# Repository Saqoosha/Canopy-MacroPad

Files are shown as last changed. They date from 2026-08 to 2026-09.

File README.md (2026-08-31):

# Canopy MacroPad

Six keys next to the keyboard. Each key mirrors one Canopy pane: its
LED shows what that pane's Claude session is doing, and pressing it
focuses that pane and brings Canopy forward.

**There are two of these, and one firmware runs both.** The first is
three boards butted together: keys 2-5 a NeoKey 1x4 on I2C, keys 0-1 two
single-key breakouts read straight off GPIO, landing on one 19.05 mm
pitch because the breakout happens to be exactly one pitch wide with its
switch centred in it. The second is a **custom PCB** that is all six keys
on one board — see [Phase 1 scope](#phase-1-scope).

Which board a key sits on, and which device it is, are both invisible to
the host: the protocol has one index space and the device reports its
size. The firmware picks a board profile from the CircuitPython build it
booted, so neither the wire protocol nor the key numbering moves.

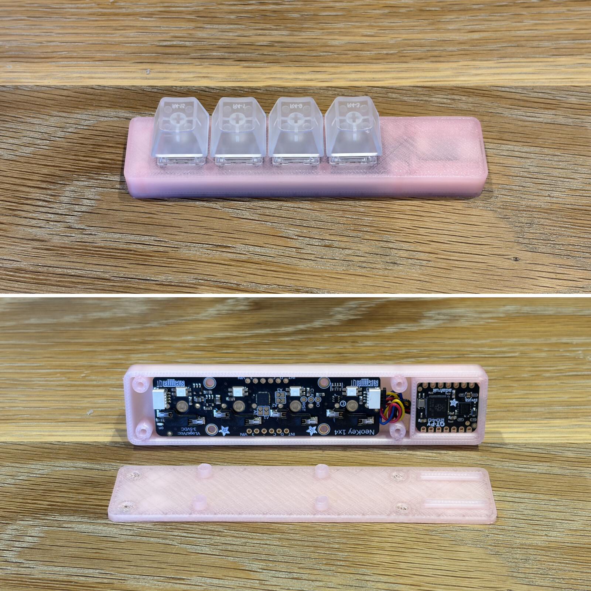
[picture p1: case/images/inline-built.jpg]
The four-key inline case, closed with keycaps on, and open with the NeoKey and the QT Py seated in the shell above the bottom plate


**That photograph is the four-key print**, which is the pad that existed
before the breakouts. The six-key `inline` case is printed, wired and
closing; the photograph of *it* is the wiring shot further down, taken
with the shell turned over. Nothing here is waiting on hardware.

That is the **first** device, in the `inline` case, printed on a Bambu A1
mini. The enclosure is parametric, and it is also **[a model you can turn
in a browser](https://saqoosha.github.io/Canopy-MacroPad/)** — orbit,
explode, cutaway. The published page is the `choc` case, for the custom
board, so it is **not** the case in the photo above. It is a copy rather
than a build, so it goes stale on its own; `case/README.md` carries the
five lines that republish it. How the case is built is there too.

This repository holds the device half. The macOS half lives in the
[Canopy](https://github.com/saqoosha/Canopy) repository under
`Sources/Canopy/MacroPad/`.

## Why not HID

The device enumerates as USB serial only — `usb_hid.disable()` in
`boot.py`. It is never a keyboard. Consequences, all of them the reason:

- keystrokes cannot leak into whatever app is focused
- with Canopy not running, pressing a key does nothing at all
- macOS never asks for the Input Monitoring permission, because nothing
  reads HID. (OpenAI's Codex Micro required it as of 2026-08.)
- a serial port is plain file I/O on `/dev/cu.*` — no entitlement, no
  Hardened Runtime or notarization friction
- raw press/release edges, with no OS key-repeat logic in between

Verifiable rather than asserted: `ioreg -w0 -l -r -c IOHIDDevice | grep
-c 'Canopy MacroPad'` returns 0, and the device's USB descriptor offers
CDC control and CDC data, plus mass storage in the states described
under [The CIRCUITPY drive](#the-circuitpy-drive) — no HID class at all,
in any of them.

Two limits worth stating, since the argument above reads as exhaustive
and is not. **The filesystem is still writable from the host**, and the
drive gate below does not change that: any process that can open the
console port has the REPL, and `storage.remount("/", readonly=False)`
from there rewrites `code.py` with no finger going near the device. A
plain `/dev/cu.*` open needs no entitlement, which is exactly the
property this section advertises three paragraphs up. So the threat
model here is "no input injection", not "tamper-proof" — the gate is a
convenience, not a boundary. And a **sandboxed** app would
need `com.apple.security.device.serial` to open the port; Canopy
sidesteps that by not being sandboxed at all (no
`com.apple.security.app-sandbox` key in `Canopy.entitlements`). If that
changes, this design has to be revisited.

## The CIRCUITPY drive

`boot.py` calls `storage.disable_usb_drive()` unless a key is held while
the device boots. The reason is mundane: this pad is unplugged the way
any desk toy is, and a mounted volume disappearing makes macOS say
*"Disk Not Ejected Properly"* every single time, about a disk nobody was
using. Ejecting first works and nobody does it.

**Hold any of the six keys through a boot and `CIRCUITPY` mounts as
before.** Any hard reset counts — replug, `RST` where there is one, or
`microcontroller.reset()` — since that is when `boot.py` runs. The drive
then stays mounted for the rest of the session, so an edit-and-copy loop
needs the finger only once.

How the six are read differs by board, and `boot.py` carries its own small
copy of the profile table to know which. On the **PCB** all six are GPIO
and there is no bus to probe. On the **wired pad** the GPIO pair is read
first, because two pin reads cost nothing against the seesaw's 0.5 s
software reset and a key held there skips the bus entirely; on the I2C
side only `0x30` is probed, so a second NeoKey's keys would not work as
the gate.

Rather than enumerate the ways the read can fail, state the property
that holds by inspection: **`disable_usb_drive()` is reachable on
exactly one path — a completed read that saw no key held.** Every other
outcome leaves the drive enabled, whether it raises inside the guard,
escapes it, or never returns at all. That direction is deliberate: the
filesystem is how a broken board is recovered, and hiding it exactly
when the board is broken would be the worst possible time. The cost of
failing this way is that the macOS warning comes back, which is merely
the annoyance this whole thing exists to remove.

Which way the gate went is recorded in `boot_out.txt` — transcripts, not
examples; every line below was captured from a real boot:

```
usb drive: disabled; hold a key while plugging in for CIRCUITPY
usb drive: enabled (key held at boot)
usb drive: enabled (gate failed: ImportError: no module named 'adafruit_neokey')
```

Read that file **from the REPL** on the console port — `print(open(
"/boot_out.txt").read())`. Reading it off the mounted drive can only
ever show you the two `enabled` lines, because mounting the drive is
what makes the gate take the other branch and overwrite the line you
came for.

Two other ways back to the files, for when a key cannot be held. From
the REPL, `import storage` / `storage.remount("/", readonly=False)`
gives *the device* write access — the drive stays gone, so a new
`code.py` has to be pasted through serial; `os.remove("/boot.py")` and a
reset is the shorter version of the same idea. Or unseat the Qwiic
cable **and then hard reset** — the gate fails open on the next boot and
hands the drive back. Unseating alone changes nothing; `boot.py` does
not run again until the board does.

## Hardware

Two devices, so two bills of materials. The custom PCB is the current one
and replaces every board in the other; the wired pad is still assembled
and still works, and the numbers its assembly settled are inherited whole.

### The custom PCB

One board, 139.60 × 21.59 mm, two layers, 1.6 mm, fabricated and partly
assembled by JLCPCB. Designed in EasyEDA by script — `pcb/README.md` for
that side of it, `pcb/BRINGUP.md` for what to do with the article when it
arrives.

| Ref | Part | LCSC | Role |
|---|---|---|---|
| U3 | RP2040 | C2961140 | controller, CircuitPython |
| U1 | W25Q64JVSSIQ | C179171 | 8 MB QSPI flash |
| U2 | ABM8-272-T3 | C9900091606 | 12 MHz crystal |
| U4 | XC6206P332MR-G | C5446 | 3V3 LDO, everything sits behind it |
| D1 | USBLC6-2SC6 | C323793 | USB ESD |
| USBC1 | TYPE-C-31-M-12 | C165948 | USB-C receptacle |
| LED1-6 | SK6812MINI-E | C5149201 | reverse-mount pixels, one chain on GPIO25 |
| SK1-6 | CPG135001S30 | — | Kailh Choc hot-swap sockets, 19.05 pitch |
| SW1 | TS263065A | — | BOOT, beside the USB-C |
| R3, R4 | 27 Ω | C25100 | USB D+/D− series |
| R5, R6 | 5.1 kΩ | C25905 | USB-C CC pulldowns |
| R1, R2 | 1 kΩ | C11702 | BOOT series, crystal damping |
| — | Kailh Choc v2 ×6 | — | low-profile, hot-swappable |
| — | wrk. MX Pure keycaps ×6 | — | frosted PC |

Everything is on the **bottom** face — the Gerber archive carries a bottom
paste layer and no top one, which is the quickest way to confirm it. No
Qwiic cable, no inter-board wiring, and nothing hangs off an unregulated
rail: the pixels' `VDD` and the RP2040 both sit on 3V3 behind U4. That
last one is a real difference and not a detail — see `pcb/BRINGUP.md` for
what it cost to check, and for why the pixels run below their own
datasheet minimum on purpose.

### The wired pad, which came first

Still assembled, still driven by Canopy, and the source of every number
the case inherited.

| Part | SKU | Role |
|---|---|---|
| Adafruit QT Py RP2040 | ssci 7211 / ADA-4900 | controller, CircuitPython |
| Adafruit NeoKey 1x4 QT | ssci 10048 / ADA-4980 | keys 2-5, on I2C `0x30` |
| Adafruit NeoKey Socket Breakout ×2 | ssci 10047 / ADA-4978 | keys 0-1, on GPIO |
| Qwiic cable 50mm | ssci 6896 / SFE-PRT-17260 | QT Py ↔ NeoKey |
| Durock Ice King Linear ×6 | — | MX compatible, clear housing |
| Clear ABS keycaps ×6 | — | placeholder for printed caps |

Everything from here to this section's last paragraph is that device —
the cable, the five wires, the power tap, the rail argument. None of it
describes the PCB, which has one board and no cable at all.

One thing in there does carry over, because it is physics rather than
wiring: **an SK6812's green and blue dies drop out first**, so a sagging
rail reads as a warm shift and not as darkness. The PCB runs the same
family on 3V3 deliberately, and that sentence is why a white pixel is the
sensitive test for its rail — `pcb/BRINGUP.md` uses it twice.

**Why not a second NeoKey 1x4**: it gives eight keys, not six, and is
152 mm of board. **Why not the Snap-Apart 5x6 broken to 1x6**: one
uniform board with guaranteed LED consistency, but it carries no seesaw,
so I2C disappears, the drive gate is rewritten, and every error path
proven by injection has to be proven again — for ¥5,088 against ¥858.

The 4978s go to the **left** of the NeoKey, and the cable is what forces
it: on the right they strand the NeoKey's socket 114 mm from the QT Py
against a 50 mm cable. This used to give a second reason — that a mated
Qwiic plug stands 2.50 mm proud of its board edge while a butted
breakout's switch body starts 2.525 mm from that edge, so the two miss
by the tolerance — and it was not a reason at all. The plug hangs below
the board and the switch stands above it, so that pair was never in the
same space. Booleaned since, and then assembled: a plug in the NeoKey's
left socket clears the breakouts, the switches and both printed parts,
and there is a photograph of one sitting in there with both breakouts
butted on. The socket is not blocked; the built unit simply leaves it
empty, because power ended up coming off the headers instead.

Five wires and no per-key soldering — the breakouts ship with Kailh
sockets and their NeoPixels already fitted:

| from | to |
|---|---|
| QT Py `MOSI` | breakout 0 `NEO_IN`; its `NEO_OUT` to breakout 1 `NEO_IN` |
| QT Py `MISO` | breakout 0 `SWITCHA`, pulled up |
| QT Py `SCK` | breakout 1 `SWITCHA`, pulled up |
| NeoKey `JP1`/`JP5` `VIN` | both breakouts' `VDD` |
| NeoKey `JP1`/`JP5` `G` | both breakouts' `GND`, and `SWITCHC` |

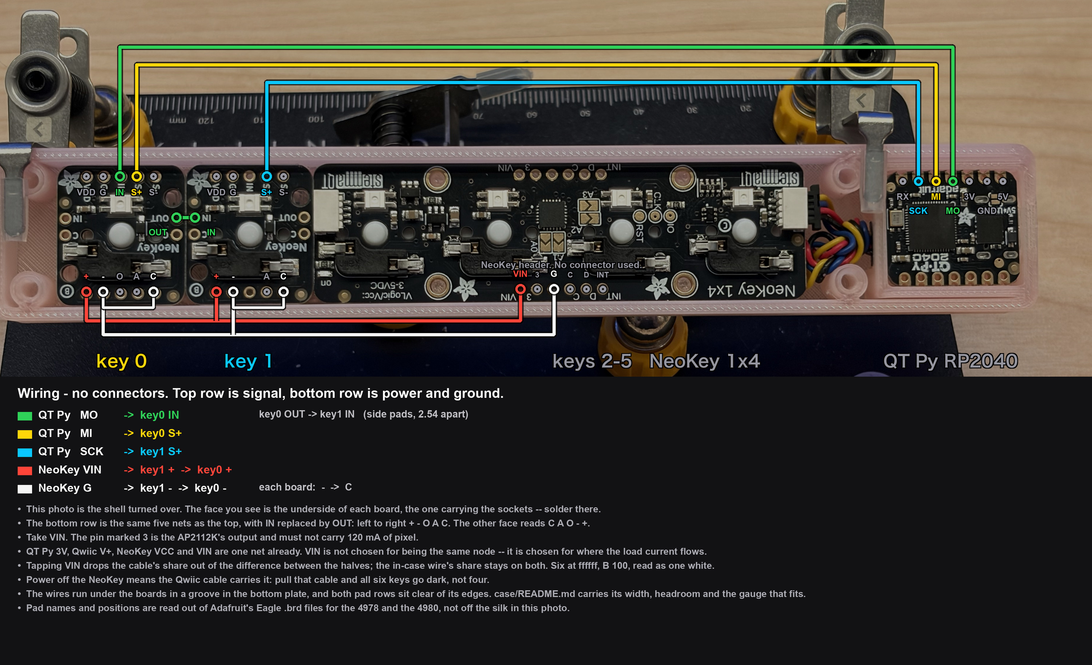
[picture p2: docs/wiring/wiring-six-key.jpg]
The same wiring drawn on the assembled boards: every pad named, the three signal wires on the top row and the two power wires on the bottom one


The photograph is the shell turned over, so the face in it is the one the
wires go on. Pad names and positions in it come out of Adafruit's Eagle
`.brd` files for the 4978 and the 4980, **not** off the silk in the photo
— the boards sit rotated in the case, so that silk runs the opposite way
from the table above, and reading left to right off the picture is how
you get the wiring mirrored.

`docs/wiring/` holds the photograph and the script that draws on it;
`python3 docs/wiring/annotate.py` redraws the image. Every coordinate in
it is a pixel position on `boards.jpg` at its native size, so replacing
that photograph means re-reading all of them — nothing derives a scale.

Power comes off the NeoKey rather than the QT Py, so only three wires
cross the case. `JP1` and `JP5` are the headers on the NeoKey's long
edges, `INT D C - 3 VIN`, and that `VIN` is the `VCC` net — the one the
STEMMA receptacles' `V+` lands on. The pin marked `3` is the `AP2112K`'s
output and feeds no pixel anywhere.

The NeoKey's spare STEMMA socket carries the same net and sits closer to
the boards, and it was the plan for a while. The schematic has both
receptacles fully parallel — `V+`, `GND`, `SDA` and `SCL` all common —
so the left one is the same node as the right, and a plug goes into it
with both breakouts butted on, which there is a photograph of. It is a
real option and it is not the one taken. A header wins on parts: a
solder joint instead of a connector, and the second cable's other pair
would have been `SDA`/`SCL`, live and terminated in nothing — 50 mm of
unterminated stub on a 100 kHz bus, harmless, but better decided on than
discovered.

Neither tap relaxes the wire channel. Both sit at or beyond the NeoKey's
left edge and the narrowest point in the case is immediately left of
that, so all five wires are still abreast where it matters. What the tap
buys is length, not width.

**Taking power off the NeoKey means the Qwiic cable carries it.** Pull
that cable and keys 0 and 1 lose their supply and their ground reference
together: the pixels go dark, `SWITCHA` floats high through its pull-up,
and they report as never pressed. The device stays up and still says
`HELLO 3 6`. Every *other* I2C fault — a missing library, a wrong
address, a seesaw that stops answering — still costs exactly the four
keys behind it, which is what the firmware's separate guards are for. So
the promise is narrower than it reads elsewhere: **a dead NeoKey costs
four keys, a dead cable costs six.** Running `3V` and `GND` from the QT
Py instead buys the wider promise back, for two more wires through that
lane.

Each breakout carries a 1N4148 from `SWITCHA` to `SWITCHC`, so grounding
`SWITCHC` makes a press read low. The forward drop at the ~55 µA an
internal pull-up supplies is about 0.45 V, under the RP2040's 0.8 V
V<sub>IL</sub> but not by much: a key stuck reading pressed is the
symptom of that being wrong, and an external pull-up is the fix.

Both boards carry the same pixel — the schematics name it `_SK6812E`,
same device on both — and on the NeoKey it runs off `VCC`, the incoming
Qwiic rail, *ahead* of the `AP2112K-3.3` that feeds the seesaw. A
`74*1G125` shifts the seesaw's data up to that same rail. So the pixels
see whatever the cable brings, and the status colours below were tuned at
whatever that is.

That is the argument for the colours carrying over: identical part, and
one net. Traced through both schematics rather than assumed — the QT Py's
`3V` pad, its STEMMA `V+` and its regulator output are all `+3V3`; the
cable carries that to the NeoKey's `VCC`, which is what its four pixels'
`VDD` and its `JP1`/`JP5` `VIN` sit on. Wherever the breakouts are
tapped, they are on the same node as the pixels the colours were tuned
against.

Which settles the topology and not the question. What the colours
actually depend on is the **voltage under load**, and six SK6812s at full
white pull it down through a connector, a cable and however much wire
this case makes them share. Same net says nothing about the drop across
it.

The tap point does matter, and not for the reason it first looks. One net
does not mean one potential: taking the breakouts off the QT Py leaves
the NeoKey carrying the Qwiic cable's drop alone, so the two halves land
at different voltages and drift apart in colour. Taking them off the
NeoKey puts that drop in front of all six at once. It does not make the
difference vanish — the breakouts still sit behind their own wire — it
removes the cable's share of it. Whether any of this is visible is a
different question again, since the rail is already about 200 mV below an
SK6812's datasheet floor before a single wire is counted.

**The rail has still not been metered, and it no longer needs to be.**
The voltage was only ever a proxy for a question that can be looked at
directly: on the assembled unit, all six set to `ffffff` at `B 100` —
the worst case, three dies lit on every pixel, the breakouts' current
crossing the cable too — the two halves are the same white. So the
argument above was right, and the tap point stopped being a colour
decision. If a number is ever wanted anyway, `tools/mpad.py --load`
produces that same worst case; probe at an LED's `VDD`, not at the QT
Py.

**The pixels are not identical to each other, though.** One of the six
sits slightly purple against the other five under that test, and it does
not follow the supply — it is on the same node as its neighbours, and
they agree. It is part-to-part variation in the LED. Worth writing down
because the alternative explanation is the rail, and the rail is now
exonerated: a small mismatch found later is a pixel, not a wire.

One consequence worth knowing before anyone "fixes" it. An SK6812's
datasheet floor is 3.5 V and its green and blue dies drop out first, so a
3.3 V rail shows up as a warm shift rather than as darkness. If that is
what this is, all six keys are equally under it and equally warm, which
is the outcome that makes them match — so **do not feed the breakouts 5 V
on their own.** That would fix two keys, break the match, and leave the
breakouts needing a level shifter the NeoKey already has. Both rails or
neither.

Key count is never hardcoded in Canopy — the device reports it in
`HELLO` — and `tools/mpad.py` now reads it from `PONG` rather than
assuming.

## Protocol

Line-delimited ASCII on the **data** CDC port. Human-typeable on
purpose: the whole thing can be driven from a serial monitor.

**host → device**

| Command | Meaning |
|---|---|
| `C <idx> <rrggbb>` | set key to a solid color, e.g. `C 0 ff8000` |
| `S <idx> <rrggbb> [ms] [floor]` | pulse that color, eased by the firmware's `PULSE_CURVE`. `ms` is clamped to ≥100, `floor` to 0-100 |
| `B <0-100>` | global brightness |
| `X <ms>` | crossfade duration for `C` and `S`, default 500 |
| `P` | ping |
| `R` | all keys off, immediately |

`S` runs on the device, not the host. A square blink is one command per
half period and would sit on the host happily, but an eased fade is ~50
updates a second — silly to push down a wire, and it stutters on any host
hiccup. It is also already where it needs to be for BLE. `ms` is the full
period (default 2500); `floor` is the percentage the dip bottoms out at
(default 0). `C` on the same key cancels the pulse.

**Every colour and floor change is crossfaded**, over `X` milliseconds.
An instant switch reads as "something just happened", but most
transitions are a session moving from one continuous state to the next,
so an abrupt change makes the pad overstate the event.

Internally there is only one appearance model: a colour and a floor,
where **solid is a pulse whose floor is 100%** and the curve term drops
out. One interpolation therefore covers all four transitions with no
special cases:

| Transition | What happens |
|---|---|
| solid → solid | colour crossfades |
| solid → pulsing | colour and floor crossfade; phase starts here |
| pulsing → solid | colour and floor crossfade; the breath flattens out |
| **pulsing → pulsing** | **phase is held**; only colour and floor move |

That last row is the one that matters. Going from running to awaiting
approval changes the floor from 50 to 10 — restarting the phase would
drop the breath to its trough, and "the heartbeat stopped" reads louder
than "the urgency changed", which is the opposite of what happened.
Phase restarts only when a solid key starts pulsing, or when the period
itself changes.

**Re-issuing the appearance a key is already heading for is a no-op.**
Not just an identical `S` — any `C` or `S` whose colour, floor and period
match the current target returns without restarting either the crossfade
or the breath. So the host never has to track which keys are already
doing what: push the full picture whenever convenient — after every
`HELLO`, on a timer — and only genuine changes are acted on.

Phase, then, is simply "when the key started breathing". Keys whose
states change at different moments drift apart on their own, with no
phase bookkeeping on either side.

An earlier revision also added a fixed per-key offset, to stagger keys
told to pulse in the same instant. It was removed: an offset that is
non-zero at t=0 is exactly a key that does not start at its floor, and
with four keys it put key 2 at full brightness on its first frame —
breaking the fade-up on whichever key held the approval state. The two
properties cannot both hold for simultaneous starts, and fading up won.

**device → host**

| Message | Meaning |
|---|---|
| `HELLO <ver> <keys>` | a host opened the data port |
| `PONG <ver> <keys>` | reply to `P` |
| `K <idx> <0\|1>` | key pressed (1) / released (0) |
| `ERR <msg>` | command could not be handled, or the firmware died |

`<ver>` is 1 for `C`/`B`/`P`/`R`, 2 once `S` exists, and 3 once `X`,
crossfading, and phase-held colour changes exist. Accept anything `>= 1`:
the number says which verbs and behaviours are available, it is not a
compatibility gate. A v3 device needs no `X` to behave correctly — the
default is already 500 ms.

Three behaviours the host depends on:

- **`HELLO` is sent on host connect, not at power-on.** A banner printed
  at boot is lost whenever the host was not listening yet. Treat every
  `HELLO` as "the device just came up — re-push every color."
- **The device clears all LEDs when the host disconnects.** Stale status
  is worse than none; a frozen orange key claims a session still wants an
  answer. Sending `R` before closing is belt and braces, not required.
- **`C` and `S` with an out-of-range index are dropped in silence**, so
  the host may paint before it has learned the key count.

`ERR unknown <cmd>` covers two cases, not one: a verb outside the six,
**and a known verb with the wrong argument count** — `C 0` reports as an
unknown `C`. Misleading, but stable; a host should not read it as "this
firmware lacks that verb".

### When the firmware itself dies

An uncaught exception is the worst failure here and the quietest one:
CircuitPython stops `code.py`, the data port goes silent, and the LEDs
freeze at whatever they last showed. From the host that is exactly what a
board that never booted looks like.

So the loop has a last line of defence. On any escaped exception the
device sends `ERR fatal <type>: <detail>`, paints every key red, and then:

- **after the first minute of uptime** — waits two seconds and resets,
  landing on the recovery path that already exists. The host sees a fresh
  `HELLO` and re-pushes everything; nothing new has to be wired up.
- **within the first minute** — stays halted and red instead. A fault
  that fires on every boot would otherwise reset-loop, and a board whose
  USB re-enumerates every few seconds is hard to write a new `code.py`
  to. Red-and-halted is both the louder signal and the state you can
  actually recover from.

Painting red is best effort: if the fault *was* the I2C bus, it cannot
work, which is precisely when the reset matters most.

A host that wants to notice silent self-healing can watch for `HELLO`
arriving repeatedly in a short window — that is a reset loop, and it is
detectable entirely host-side.

Debug output goes to the *console* port via plain `print`, never to data
— unless `boot.py` did not take effect, in which case there is no data
port and both share the console. The host is told: it gets
`ERR no-data-cdc-check-boot-py` right after `HELLO`.

Keep the protocol layer separate from the transport in the host code: on
BLE these same lines become a GATT characteristic payload.

## Status colors

Tuned on the assembled hardware — clear housings, clear keycaps, normal
desk lighting. Values picked on a screen do not survive that trip.

| Pane state | Color | Motion | Command |
|---|---|---|---|
| no pane, or launcher | off | — | `C n 000000` |
| idle | `273027` | static | `C n 273027` |
| running (`isThinking`, `.spawning`) | `00ffff` | breath | `S n 00ffff 2500 40` |
| background task (`isWaiting`) | `2800ff` | breath | `S n 2800ff 2500 40` |
| **awaiting approval (`isAsking`)** | `ff8000` | **pulse** | `S n ff8000 2500 10` |
| done, unread | `00ff00` | static | `C n 00ff00` |
| error (`.crashed`, `.reconnectFailed`) | `ff0000` | static | `C n ff0000` |

Global brightness 60. Every period is 2500 ms; only the floor changes,
and that is what separates "alive" from "answer me".

**This table is a copy and `SessionActivity.swift` is the original.** Two of
these colours were wrong here for a while -- `running` and `background task`
were listed as `0040ff` and `00ffa0` long after Canopy had moved them to
`00ffff` and `2800ff`, and the Swift's own comment records the blue slot
changing meaning in that same edit. Nothing checks the two against each
other, so read the source before trusting a value here.

The floors are `40 / 40 / 10` now rather than `50 / 40 / 10`: `running` was
deepened on a lit pad, which costs the thing the original 50 bought -- it
used to read as static in peripheral vision and no longer does. `running`
and `background task` are told apart by hue alone.

**These values are tuned against a supply voltage nobody has written
down, and that is no longer a debt.** The pixels sit on the incoming
Qwiic rail rather than behind the NeoKey's regulator, so the number that
produced this table is whatever the QT Py hands the cable, minus whatever
the wire drops under load. It was never metered — see
[Hardware](#hardware): the voltage was only ever a proxy for whether the
two halves of the keypad match, and six pixels side by side answer that
directly. They do.

If a number is ever wanted anyway, `tools/mpad.py --load` puts every key
at full white and brightness 100. Two things about that reading, each of
which changes what it means:

- **Probe at an LED's `VDD`, not at the QT Py.** The two differ by
  exactly the cable drop being looked for.
- **Under full white, not at idle.** Idle is the flattering case and it
  is not the case that browns out. `--load` exists to produce the other
  one; the shipped brightness of 60 is not what the supply has to
  survive.

What the bench actually taught, none of which was predictable on paper:

- **Hue does all the state separation, amplitude does the ranking.** The
  colors are spaced by hue alone, as the design requires. Depth of pulse
  is a second, orthogonal axis: static → shallow breath → deep pulse
  reads as increasing urgency without ever competing with hue.
- **Cyan is boxed in between blue and green and cannot be fixed by moving
  it.** At 180° it is equidistant from both. The separation came from
  moving its *neighbours* — green off `00ff40` to pure `00ff00` — and
  from cutting cyan's blue channel so it reads green-dominant against a
  blue-dominant blue.
- **Dark colors are unstable, and it is quantisation, not the LED.**
  `101010` at 30% brightness is `(5,5,5)` — it was `(4,4,4)` when the
  brightness multiply lived in pixelbuf and truncated twice; five steps above off, where
  WS2812 mixing is coarse enough to visibly flicker. Hence a lighter idle grey
  (white-balanced to `273027` below), and 60% global brightness rather than 30.
- **The same shortage stalls a deep pulse — and the first explanation of
  why was half wrong.** At 30% brightness an orange pulse with a floor of
  5 has a handful of distinct values in its lower half, so it freezes at
  the bottom; that much held. What was blamed for it was `PULSE_GAMMA`
  2.0 "crawling through" those few values, and the fix was to drop the
  constant to 1.0. Simulated against the exact quantiser afterwards, the
  two effects turn out to be independent and to *meet*. The gamma-2.0
  breath really does dwell — its bottom is quartic in time where gamma
  1.0 is quadratic, so the lowest 1% of the swing lasts 410 ms of a
  2000 ms breath against 128 — measured at the 2 s period of the time,
  and both scale with it — but that is true at infinite precision and
  at any brightness, and in what the eye responds to rather than in
  linear units it is not a dwell at all. The freeze is those 410 ms
  landing inside a span under 2 LSB wide. Raising global brightness buys
  steps, and dimming via the color value is the same multiply, so trading
  one for the other buys none — scaling the color down on its own makes
  the shortage worse. What actually buys steps back is temporal
  dithering, which the firmware now does on boards that can paint at
  200 Hz and above `DITHER_FLOOR`.

  **And then the board answered a question this note could not.** Keys held
  at 0/1/2/3/4/5 side by side: 0 to 1 is a different world, 1 to 2 is
  plainly visible, and 2/3/4/5 cannot be told apart at all. So the visible
  steps are the first two and nothing below the floor is recoverable by any
  temporal trick -- but also, the deepest breath Canopy sends bottoms out at
  7.7 of 255 in its faintest lit channel, which never reaches them.
  Everything above was found at brightness 15 with a floor of 0. That is
  outside the envelope the pad is driven in, and the whole quantisation
  story is insurance rather than a fix for something happening.

  The curve moved for a different reason, and the gamma question is closed:
  1.0 read as "the bottom is short and the top is long", 2.0 as a pause at
  the bottom, 1.5 was the best of that family, and `exp(sin)` beat all of
  them -- each judged against five alternatives carried on the six keys at
  once. `firmware/code.py`'s `PULSE_CURVE` carries the numbers and
  `tools/dither_check.py` re-measures the quantisation without a device.
- **Equal RGB is not neutral, and the correction is level-dependent.**
  The green channel is the weak one, so an equal-RGB value reads purple
  through a clear keycap. What is surprising is that the size of the fix
  is not constant: white needed red and blue trimmed ~6% (`ffffff` →
  `f0fff0`), while idle at the same global brightness needed ~18%
  (`303030` → `273027`). Per-channel efficiency diverges as drive drops,
  so **a single global white balance is wrong at one end or the other by
  construction** — the grey-axis values are corrected individually
  instead, by eye, like every other colour here. The five saturated status
  colours need none of this.
- **Some of the cast is per-LED, and that part is left alone.** On the
  four-key pad, one of the NeoKey's four read neutral at a value the
  other three did not; on six, one pixel reads faintly purple against the
  rest. Same finding twice, and the second time it was checked against
  the supply and cleared — that pixel is on the same node as its
  neighbours, and they agree. Correcting it needs a per-key gain table,
  which would be valid for this one assembled unit and wrong for the next
  — so only the systematic part is corrected, and the residual spread is
  accepted. Idle is the one colour carrying no hue meaning, so a little
  variation in it costs nothing.
- **Equal amplitude does not read as equal motion across hues.** Cyan sits
  near the eye's sensitivity peak and looks far brighter than blue, so the
  same modulation reads as less movement.

  **The arrangement that compensated for it is gone, twice over.** This
  note was written when `running` was blue at a floor of 50 and the
  background state was a green-cyan at 40 — so cyan really was the deeper
  one. The colours later swapped (`running` became cyan `00ffff`,
  background became blue `2800ff`) and the floors did not move with them,
  which silently inverted the compensation; nothing caught it, because
  nothing relates the two. Both are 40 now, so there is no compensation at
  all. The observation still holds and the pad no longer acts on it —
  recorded rather than fixed, because the two states are told apart by hue
  and the deliberate ladder is `asking` against everything else.

## Bring-up

**This is the wired pad's procedure.** The PCB's is different in its first
two steps and has its own file: [`pcb/BRINGUP.md`](pcb/BRINGUP.md). Three
things differ and each will stop you. It has **no RST button** — SW1 is
BOOT and there is nothing to tap, so the bootloader is entered by holding
SW1 through a plug-in (or by bridging its bare footprint, before SW1 is
soldered). It runs a **stock `raspberry_pi_pico` build**, not the QT Py
one. And its `lib/` needs **`neopixel.mpy` only** — `adafruit_neokey` and
`adafruit_seesaw` are for a bus it does not have, and their absence is
never even reported. Everything from step 3 down is the same on both.

1. With USB connected, **hold BOOT, tap RST, release BOOT** → the
   `RPI-RP2` volume appears. Double-tapping RST did not work here on
   2026-08-08 with CircuitPython 10.2.1. Drop the [CircuitPython
   UF2 for QT Py RP2040](https://circuitpython.org/board/adafruit_qtpy_rp2040/)
   on it; the board reboots as `CIRCUITPY`.
2. From the [CircuitPython Library
   Bundle](https://circuitpython.org/libraries), copy `adafruit_neokey/`,
   `adafruit_seesaw/` **and `neopixel.mpy`** into `CIRCUITPY/lib/`.
   `neopixel` is the one the breakouts need; without it keys 0-1 still
   report presses and simply never light, and the host is told
   `ERR gpio pixels ...`. `adafruit_hid` is not needed and must not be
   used. `adafruit_pixelbuf` is a core module and is not in the bundle
   list for that reason.
3. Copy `firmware/boot.py` **and** `firmware/code.py` to `CIRCUITPY/`,
   then **hard reset**. `boot.py` only re-runs on a hard reset, and only
   a hard reset re-enumerates USB, which is what actually applies the CDC
   interface change. Unplug and replug, or from the REPL on the console
   port: `import microcontroller` / `microcontroller.reset()`.
4. `ls /dev/cu.usbmodem*` — two ports must appear (console and data).
   Give it a second or two: the keypad gate runs before USB enumerates
   and costs about half of one. One port after that means `boot.py` did
   not take effect; repeat step 3, and note that in *that* failure the
   gate never ran either, so `CIRCUITPY` is still mounted to repeat it
   with.
5. `CIRCUITPY` is now gone, which is `boot.py` working as intended — see
   [The CIRCUITPY drive](#the-circuitpy-drive). Hold a key through the
   next hard reset to get it back for the next copy.
6. `tools/mpad.py --probe` — reports which port is data, plus the VID,
   PID and product string the macOS side matches on.
7. `tools/mpad.py --demo` — reads the key count off `PONG`, lights that
   many keys, then turns each one white while it is held. This is the
   whole loop: LED out, key in. Six keys lit means both halves of the
   keypad came up; four means the breakouts did not.
8. **Focus a text editor and press the keys. Nothing must be typed.**

Step 8 is the one that matters. If characters appear, `usb_hid.disable()`
is not in effect and the entire premise of the design is broken. The
objective version of the same check does not need a human:

```
ioreg -w0 -l -r -c IOHIDDevice | grep -c 'Canopy MacroPad'
```

Zero means macOS's HID subsystem cannot see the device at all, so no
keystroke can reach any app — a stronger result than "nothing appeared in
my editor".

### Measured on the bench

First bring-up, 2026-08-08, CircuitPython 10.2.1, board ID
`adafruit_qtpy_rp2040`:

| What | Measured |
|---|---|
| product string | `Canopy MacroPad` (set by `boot.py`, confirmed in the descriptor) |
| manufacturer | `Saqoosha` |
| VID / PID | `0x239A` / `0x80F8` |
| console port | `/dev/cu.usbmodem20101` |
| data port | `/dev/cu.usbmodem20103` |
| USB interfaces | CDC control (class 2), CDC data (class 10), mass storage (class 8). **No class 3 — no HID.** |
| `IOHIDDevice` entries | none |

That table is what the instrument said on that date, and the drive gate
did not exist yet — mass storage was unconditional then. It is not any
more; see [The CIRCUITPY drive](#the-circuitpy-drive) for which boots
carry it. The port names shift with it, since macOS derives the
`usbmodem` suffix from the interface layout, which is one more reason
for the paragraph below.

The data port took the higher trailing number here, but do not select on
that. `P` → `PONG` is the only reliable discriminator: the console port
runs the REPL, which echoes `P` as typed text and never answers.

**And do not select on the PID either.** `boot.py` sets the manufacturer
and product strings and nothing else, so the VID and PID are whatever the
CircuitPython build carries — a property of the binary, not of this
firmware and not of the product. The same `boot.py` on the custom PCB,
running a stock `raspberry_pi_pico` build, measures `0x239A` / **`0x80F4`**
against the QT Py's `0x80F8` above. Both readings are correct; neither is
the device's identity.

So **`Canopy MacroPad` is the identifier**, and `P` → `PONG` is the port
test. `tools/mpad.py` was already written that way — it matches the VID
and the product string and never looks at the PID, which is why it found
the PCB unchanged. A host that matches on the PID will not.

Setting a fixed VID/PID in `boot.py` would make the identity independent
of the build, and is deliberately not done — **and the host agrees.**
Canopy matches on the product string plus the vendor id (accepting a
missing vendor), and `MacroPadDevice.swift` says why the product id is
left out: it belongs to the board and the CircuitPython build rather than
to this project, so pinning it would *fail closed*, and a device that
never connects looks exactly like a bad cable. So the PCB's `0x80F4` costs
nothing on that side, and pinning a PID here would only reintroduce the
coupling both halves went out of their way to avoid.

### When the keypad is missing

**The wired pad only.** The PCB has no bus and no cable, so its profile
carries no I2C addresses and that whole half of the firmware is never
built — no `ERR i2c` of any kind can appear on it. Its equivalent failure
is a different one, `ERR board`, below.

`board.STEMMA_I2C()` raises `RuntimeError: No pull up found on SDA or SCL`
when the Qwiic cable is not seated — the I2C pull-ups live on the NeoKey
board, not the QT Py. The firmware catches this and keeps the serial half
running rather than dying, so the host sees:

```
HELLO 3 6
ERR i2c setup RuntimeError: No pull up found on SDA or SCL; check your wiring (reset required after fixing)
```

The verb is `setup`, not `bus` — this document said `bus` until the
`ImportError` half of it was captured off a real board, which arrives on
the same path and reads `ERR i2c setup ImportError: no module named
'adafruit_neokey' (reset required after fixing)`. `code.py` builds both
from one `"setup {}: {}"`.

**The key count does not drop for a missing keypad.** It used to:
`HELLO <ver> 0` once meant "device present, keypad absent". It stopped
meaning that, because the GPIO half cannot fail to enumerate and key 2 has
to stay key 2 whether or not the NeoKey answered — the host maps index to
pane, and letting the boards renumber when a cable is out would quietly
focus the wrong session. So for any hardware fault the count is 6 and the
`ERR` is what says which half is missing. The host should hold the
connection and paint normally; the four keys behind the missing board
simply do not light, and writes to them are dropped in silence exactly
like an out-of-range index.

`CIRCUITPY` comes back in this state, because the same missing keypad
fails the drive gate open. That is a useful tell rather than a second
fault: drive present *and* two ports means the gate could not read the
keypad, and the keypad is what to go and look at.

### When the firmware does not know what board it is on

`HELLO <ver> 0` is reachable again, with one meaning and only one: the
board profile did not resolve. It arrives with

```
HELLO 3 0
ERR board build 'something' is not one of pcb/qtpy (set MPAD_BOARD in settings.toml)
```

and the device claims no pins and no addresses at all. That is deliberate.
The profile is chosen from `sys.implementation._build`, a compile-time
string, and if it is not in the table the firmware has no honest way to
guess: a wrong guess renumbers every key silently, which is the one
failure the whole file is arranged to prevent. Claiming six keys that
resolve to no hardware would be a positive claim of health, and that is
worse than saying nothing.

It is not a wiring fault and no amount of looking at the board will fix
it. The fix is one line in `CIRCUITPY/settings.toml` — `MPAD_BOARD="pcb"`
or `"qtpy"` — and a reset; no reflash. The most likely cause is a
CircuitPython upgrade that renamed a build.

### When nothing enumerates

No `RPI-RP2`, no `/dev/cu.usbmodem*`, and no VID `0x239A` in `ioreg -p
IOUSB -w0 -l`: the board is not on the bus at all. A missing `CIRCUITPY`
is *not* part of this symptom — that is the normal state now, and says
nothing either way; go by the ports. In
descending order of likelihood — a charge-only USB-C cable (most USB-C
cables sold with phones carry no data pairs), a hub or dock passing power
but not data, or a dead cable. Try a known-good data cable straight into
the Mac before suspecting the board.

## Where this is

Six keys, USB wired, status out and focus in. **Built, and built twice.**

The first device is an Adafruit QT Py RP2040 with two 4978 breakouts on
GPIO and a NeoKey on I2C, in the printed `inline` case — the one in the
photo above. It is assembled, wired, closing, and Canopy drives it.

What that unit settled, none of which the model could have: both halves
of the keypad read as the same white at `B 100`, so the Snap-Apart
fallback is not needed; a breakout wants no locating peg, because the
switch clips to the plate and ties the board to it through its socket;
the five wires needed a millimetre of case they did not have; and the
Qwiic pocket's notch, the last thing on that list, is simply fine at 1.00
several builds later. The rest of its numbers are in [case/](case/), and
the custom board inherited all of them.

The second is a **custom two-layer PCB** that replaces all of it: one
board, six Kailh Choc hot-swap sockets on 19.05, six SK6812MINI-E, an
RP2040 and its flash, USB-C and an LDO. Designed in EasyEDA by script
([pcb/README.md](pcb/README.md)), fabricated by JLCPCB with partial
assembly, and brought up with every circuit on it verified — what that
took, in what order, and which of those steps prove less than they look
like they prove, is [pcb/BRINGUP.md](pcb/BRINGUP.md).

**One firmware runs both.** `firmware/code.py` carries a `PROFILES` table
and picks its entry from which CircuitPython build it booted, so the two
devices share a protocol version, a key count and every line of policy.
The pin tables cannot be shared even though the pin *numbers* are: GPIO3
is the breakouts' pixel line on one board and KEY0 on the other.

The enclosure followed the board. `case/` is one layout now, `choc`, sized
from `pcb/params.py` directly rather than from restated dimensions. Both
halves are printed and both fit: the end hook seats through the C's whole
depth, and `COLUMN_SLACK` at 0.40 stopped the board support columns
holding the seam open — the reprinted bottom closes. The `inline` and
`stacked` directories under `case/out/` are the older device's, from
layouts the source no longer has.

The one part not yet in hand is the keycaps.

The remaining phase — wireless on a MagSafe charger — is sketched in
[docs/canopy-macropad-handoff.md](docs/canopy-macropad-handoff.md) and is
deliberately not built. The only requirement now is not to block it.

The wireless one has since been costed properly, without anything being
built:
[docs/wireless-and-magsafe-findings.md](docs/wireless-and-magsafe-findings.md)
carries Apple's own magnet-ring dimensions, why the Qi coil rather than
the magnets is what decides the case depth, why Qi is pointless without
BLE, and why the board to move to is a XIAO nRF52840 rather than the
nice!nano the handoff names.

## License

MIT — see [LICENSE](LICENSE). The case geometry is covered by it too;
print it, change a number, sell one.

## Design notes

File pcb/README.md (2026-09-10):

# pcb/ — EasyEDA bring-up and known API traps

The board's own geometry, licensing, and what it's cloned from are in
`NOTICE.md`. This file is the operational half: how to talk to the EasyEDA
client from Python, and the specific ways the API has already bitten this
project.

**`BRINGUP.md` is the other kind of bring-up** — what to do with the
fabricated boards once they arrive from JLCPCB, in what order, and which
of those steps prove less than they appear to. Nothing here needs the
physical board; nothing there needs EasyEDA.

## Starting the bridge

The bridge is the `easyeda-api` skill's Node server; the EasyEDA side is
the `run-api-gateway` extension. Start it with:

```
node ~/.claude/skills/easyeda-api/scripts/bridge-server.mjs &
```

It scans ports 49620-49629 and identifies itself with `service ==
"easyeda-bridge"`. Check it's actually up and actually talking to a client
before running anything against it:

```
curl -s http://127.0.0.1:49620/health
```

A healthy answer has `"edaConnected": true`. If `edaConnected` is `false`,
or if nothing answers on any port in the range at all, the fix is the same
either way and it is **not** a port problem:

**In EasyEDA, Extension Manager → Config → `run-api-gateway` → tick
*Allow interactive with external*.** The extension's manifest does not
request this permission by default, so without the box ticked the
extension opens no socket at all. What you see instead is `"Bridge not
found"` (or a `health` check that never returns `edaConnected: true`)
against a bridge process that is itself perfectly healthy — the failure
reads like the bridge is broken when the actual gap is a permission
EasyEDA never granted its own extension. Tick the box, then also tick
*Show at header menu* if you want the API Gateway status visible, then use
API Gateway → Reconnect. `bridge.py`'s `find_port()` raises a message
naming this exact fix.

## API traps this project has actually hit

- **Enums are not in the bridge execution context.** Code sent to
  `execute()` runs in an environment where `EPCB_LayerId`,
  `EPCB_PrimitivePadHoleType`, and every other enum object are simply
  absent — referencing one throws a `ReferenceError`, not a wrong value.
  Every enum used in this codebase is the documented **literal** instead,
  with a comment naming which enum it stands in for: `build.py`'s `TOP =
  1` (`EPCB_LayerId.TOP`), `footprint.py`'s `MULTI = 12`
  (`EPCB_LayerId.MULTI`). Before adding a new one, check the literal
  against the enum's reference page under
  `~/.claude/skills/easyeda-api/references/enums/` — do not guess the
  number.

- **`pcb_PrimitiveComponent.create()` takes a device, not a footprint.**
  The first argument is `{libraryUuid, uuid}` naming a *device* (symbol +
  footprint + 3D model bundled together, EasyEDA's unit of "a part"), not
  a bare footprint UUID. `params.DEV_CHOC_SOCKET` and `params.DEV_PIXEL` are
  both device UUIDs, found with `lib_Device.search()` and confirmed live
  by placing them and reading the result back — not read off a footprint
  browser.

- **A pad's hole is `[type, diameter]` (or `[SLOT, diameter, length]`),
  never a `holeDiameter` field.** `IPCB_PrimitivePad` has no such
  property, confirmed live and absent from the class reference. The real
  shape is `hole`, and it is `null` for an SMD pad with no hole at all.
  `footprint.py._pads_near()`'s comment documents this in detail because
  it is exactly the kind of property name a reasonable guess gets wrong
  silently: reading a nonexistent `holeDiameter` doesn't throw, it just
  reads `undefined` forever.

- **A pad having a hole does not make it Multi-Layer.** The USB-C
  `B4A9`/`A4B9` VBUS pads report `layer: 2` and a round `hole`; their copper
  is still Bottom-only. `route.pad_cells()` used to allow every drilled pad
  as a start on both outer layers, so both VBUS routes left on Top and never
  connected to the real pads. `connect.py` repeated the same mistake and
  called the board complete. Only `layer == 12` spans layers. With that rule,
  the router adds the two required VBUS vias and the connectivity check sees
  the same 32 connected nets EasyEDA sees.

- **Physical overlap does not always retire EasyEDA's ratline.** The grid
  router may legally enter a pad away from its centre; EasyEDA retained seven
  short airwires on six nets even though the same-net copper overlapped.
  `center_ties.py` adds seven same-net 0.15 mm stubs from the diagnosed pad
  centres to copper already touching those pads. The final Net panel must say
  `Ratlines (0)`; hiding the Ratline layer is not verification.

- **`pcb_Drc.check()` still exceeds the bridge's 30 s timeout, and the
  button's speed says nothing about that.** Both halves are measured on the
  same board minutes apart: the client's **Check DRC** finishes in about a
  second, while `pcb_Drc.check(false)` through the bridge times out at
  30000 ms. They are different paths, not a fast case and a slow case, so
  "DRC is slow here" is the wrong lesson to carry — it is quick, and worth
  running often. What cannot be done is *scripting* it, which is why the
  export still has no automated DRC gate. This release has also rejected the
  asynchronous result with an internal `Error: undefined`, and the call can
  redraw stale yellow X markers even when it finds no current violation.

  So: run **Design -> Check DRC** in the client and read the bottom **DRC**
  panel; the required result is `All (0)`. Do not scrape the editor's private
  tab state and call that a DRC result, and do not read the X markers on the
  canvas as a count — if an interactive DRC has left old ones behind, use
  **Design -> Clear Errors** once.

- **The Net panel is the PCB editor's *left* panel, and `plane_ratlines.py`
  cannot run without it open.** Its tabs are `Page | Net | Component |
  Object` at the top left, and the tree under `Net` carries Nets, Net
  Classes, **Ratlines**, Differential Pair, Equal Length Group and Pads Pair
  Group. The script reads `[data-itemid="NetTab|_|Ratlines"]` straight out of
  the DOM, so with the panel closed it stops with `Ratlines row is not
  available` — and that message does **not** distinguish "the panel is shut"
  from "there are no ratlines". Both were guessed at here and the guess was
  wrong: the panel was shut, and there were four, all on 3V3.
  `removeIndicatorMarkers()` is a different marker system and does not remove
  DRC Xs, and the public `pcb_Drc` API exposes no Clear Errors method. Yellow X
  objects are UI state, not stored Multi-Layer primitives; hiding Multi-Layer
  never was the fix.

- **The stock footprint geometry and stock DRC table contradicted each
  other.** The reverse-mount LED opening left only 0.10 mm to its four pads,
  and each switch footprint contained two Multi-Layer circular fills exactly
  on top of two real plated holes. `footprint_fixes.py` moves the LED pads
  0.11 mm outward (about 0.209 mm opening clearance after EasyEDA's mil
  rounding) and deletes only those two duplicate fill records. The actual
  switch holes remain: the final NPTH drill has 6 slots plus 12 x 1.905 mm,
  12 x 2.9972 mm, and 6 x 5.0038 mm switch openings.

  `rules.py` then makes the live table match the measured geometry: 0.102 mm
  between copper objects, 0.20 mm from routed openings to copper, 0.25 mm
  from the USB-C shell holes to the outline, and 1.5 mm maximum USB pair
  skew. All values are read back after writing. The 36 switch-hole keepouts
  prohibit tracks, pours, and inner-layer copper, but not components: each
  switch necessarily overlaps the keepout around its own holes, so adding
  `NO_COMPONENTS` created 18 permanent false DRC errors. `all.sh` verifies the
  stored rule values and prints a reminder to run the client-side DRC; it does
  not claim `All (0)` on behalf of an API call that timed out.

- **Same-net clearance rules do not prevent accidental via-in-pad.** The
  router once produced 33 annulus overlaps, 27 with the drilled opening in a
  solderable pad, so the route grid treats every SMT pad as a no-via area and
  dogbones every router-created via. U3's stock 3x3 exposed-pad via array is
  removed too: `thermal_fanout.py` replaces it with four short bottom-layer
  GND spokes and 0.45/0.30 mm vias outside pad 57's paste area. This retains
  short thermal and ground paths without requiring filled-and-capped
  via-in-pad processing. `via_in_pad.py` rejects every annular SMT-pad
  overlap, without exceptions. Every board via uses the ordinary-cost
  0.45/0.30 mm geometry; the NPTH file still contains all 36 switch openings
  and the two 0.60 mm USB-C locating holes.

- **`eda.lib_Symbol.get()` carries no pin data.** Its return's keys are
  `name`, `libraryType`, `uuid`, `libraryUuid`, `classification`, `type`,
  `description`, `subPartNames` — confirmed live, nothing resembling a pin
  list or a pad-number-to-signal mapping anywhere in it. The instinct when
  a question is "which pad is which signal" is to reach for the symbol,
  since that's where a schematic tool would put it — it isn't here.
  `params.PIXEL_PAD_SIGNALS` (the SK6812MINI-E's pad-number-to-signal
  mapping `build.assert_pixel_signal_orientation()` checks against) comes
  from the datasheet (LCSC C5149201) instead, because the library has
  nowhere to get it from.

- **`sch_Document.save()` persists the open schematic.** Returns `true`
  on success, `false` on upload/save failure -- do not treat false as a
  no-op. Call it after any mutation; do not ask a person to File → Save.

- **`sch_PrimitiveWire.modify({line})` echoes the request and does not
  persist.** `toAsync().setState_Line()` throws `modify failed!`. The
  shape that actually changes a wire is delete-then-create. Same-net
  stubs that touch merge into one object; that is how D+ shorted to D-
  when their stars shared a vertex at x=1025, and how the split put each
  rail back together on its own net without sharing one.

- **`getExportDocumentFile()` leaves a grey loading cover if it times out,
  and the cover locks every menu.** `showLoading()` is documented as
  阻止用户进一步操作 -- clicks and menu items go nowhere while it is up.
  The bridge's default execute timeout is 30s; the PDF export hung past
  that and the cover stayed. `sys_LoadingAndProgressBar.destroyLoading()`
  / `destroyProgressBar()` clears it. `schematic_tidy.clear_overlay()` is
  that call. Restarting EasyEDA also works, but any unsaved annotation is
  gone until you can reach File → Save.

- **PCB coordinates are 1 mil; schematic coordinates are 0.01 inch.**
  `params.mm_to_mil()` is the PCB-side conversion the whole placement
  pipeline runs on. The schematic side is a different unit entirely: a
  live test placing `sch_PrimitiveComponent.create(dev, 100, 100, ...)`
  read back as `x: 100, y: 100`, and that's 1.00 inch each axis, not 100
  mil. The two documents are 10x apart on identical-looking integer
  coordinates -- the same `100` is 0.1 inch on the PCB and 1.00 inch on
  the schematic. Mixing them — e.g. reusing a PCB-side mil value as a
  schematic-side argument — places a part at roughly 1/10 of the
  intended distance from origin, silently; nothing errors, the part just
  lands in the wrong place by a factor that isn't obviously wrong at a
  glance.

- **A pad's rotation is RADIANS. A component's is DEGREES.** Same
  document, same client, same call to `getAll()`. The only sixteen
  rotated pads on this board are the USB-C receptacle's, all at
  `1.5707963`, and reading that as degrees turns a quarter turn into 1.6
  degrees — the shield tabs end up lying flat across the board edge and
  nothing complains. `geom.pad_polygon()` takes radians for that reason
  and says so.

- **A POLYGON pad's points are absolute and already rotated.** Every
  other pad shape is local to the pad and takes its translation and
  rotation; a POLYGON takes neither. Its list is also a *path*, with `L`
  and `ARC` tokens between the numbers, so pairing the raw list into
  points without skipping the keywords produces garbage.

- **A polyline's geometry is wrapped; a pad's is not.** A pad's POLYGON
  field is a bare list. A polyline's `polygon` field is an *object* with
  a `polygon` list inside it. A flattener that only descends into lists
  returns nothing for the second — which reads exactly like "this board
  has no outline", for a board whose outline is right there.
  `geom._flatten()` walks dicts because of this.

- **A polygon path must be explicitly closed.** The docs say an open
  path is closed automatically (`如果首尾不重合将会自动重合`). It is
  not: `createPolygon` refused a triangle and a square, and accepted the
  same square with its first point repeated at the end.

- **`regionName` is accepted and then not stored.** Pass one to
  `pcb_PrimitiveRegion.create()` and read the region back: there is no
  name field at all. A cleanup keyed on the name therefore matches
  nothing and every run adds another set of regions on top of the last.
  `layout.keepouts()` identifies its own by layer and rule set instead.

- **`overwriteCurrentRuleConfiguration` returns `undefined`,** not the
  documented boolean — and an undefined value disappears from the JSON
  the bridge returns, so the key is simply absent rather than false.
  Whether a rule took has to be answered by reading a number back out.

- **The class methods are not all the methods.** `PCB_PrimitivePour` has
  no rebuild function and it is easy to conclude there is no API for
  filling copper. There is: `rebuildCopperRegion()` lives on
  `IPCB_PrimitivePour`, the *instance* interface, reached by
  `pcb_PrimitivePour.get([id])`. When a class looks like it is missing
  an obvious verb, grep `references/_quick-reference.md` — it lists both
  sides.

- **The bridge has its own 30 s request timeout** and the `timeout=`
  passed to `execute()` does not raise it. `pcb_Drc.check()` and
  `sch_Netlist.getNetlist()` both outrun it on this board and come back
  as a bridge timeout while the operation completes fine inside the
  client. Neither is reachable from a script here; run them in the UI.

- **Four lines forming a closed rectangle are not a board outline.** They
  are four lines. `zoomToBoardOutline()` returns true, the render looks
  right, DRC says nothing — and Auto Routing refuses to start with
  "Please draw a board outline first!". The edge has to be **one closed
  polyline** (`pcb_PrimitivePolyline`, layer 11). Related: widening the
  board left the old right-hand edge in place and the client split the
  new top and bottom edges against it, giving seven segments — one of
  them a full-height cut line down the middle of the board, which a fab
  would route. `layout.strip()` checks the edge is a single closed loop
  for both reasons.

- **EasyEDA's rounded-rectangle `R` path has an inverted Y anchor.** For a
  board spanning y=0..21.59 mm, `['R', 0, 0, w, h, 0, r]` produces an
  outline at y=-21.59..0. The source has to start at y=21.59 mm. The
  documented polygon `discretize()` methods return `Not implemented`, so
  `board_edge.py` verifies both the raw path and the primitive's measured
  bounding box after creation. A render that merely looks rounded is not
  enough; the old inverted outline looked plausible below the components.

- **A copper pour whose boundary no longer matches the board vanishes on
  rebuild.** The GND and 3V3 planes were drawn for the 121.60 mm board;
  after widening to 139.60 they were removed by the next copper rebuild,
  silently. The only symptom was an autorouter that did nothing. And a
  pour that reaches *nothing* is discarded the same way: 3V3 refused to
  fill at all until `stitch.py` gave its pads vias, because every 3V3 pad
  on this board is surface-mount on the bottom. `planes.py` derives both
  boundaries from `params` so they cannot outlive the board again.

## Schematic-side API traps (`schematic.py`)

Everything above was learned placing sockets and pixels on the **PCB**.
Building the RP2040 block on the **schematic** turned up a second, distinct
set of traps, all confirmed live:

- **`SCH_ManufactureData.getNetlistFile()` breaks permanently after
  `createNetFlag()` or `createNetPort()`.** Not occasionally -- every time,
  reproduced twice independently, on both calls. Before either is placed the
  netlist reads fine (the very first read after a batch of edits can be
  stale or `undefined`, but a short retry recovers it every time this was
  watched). After either is placed, every subsequent `getNetlistFile()` call
  on that document returns `undefined` forever, with no amount of retrying
  or waiting fixing it -- only a full component clear does.
  `schematic.py`'s `assert_nets()` reads the netlist once, early, for
  everything that is a physical wire (QSPI, the crystal pair, VBUS, DVDD,
  USB D+/D-, CC1/CC2), *before* placing any flag or port, and falls back to
  `assert_nets_by_graph()` (a union-find over this file's own recorded wire
  segments) for anything checked after that point.

- **`eda.sch_PrimitiveComponent.getState_Component().uuid` is not the uuid
  passed to `create()`.** EasyEDA clones the library device into the
  project's own local library on placement and hands back *that* copy's
  uuid from then on -- confirmed live: `params.DEV_RP2040` is
  `"a550c651..."`, but the placed RP2040's own reported component uuid
  reads `"a67eb1f3155fc4f9"`, 16 hex characters, unrelated-looking. The
  netlist's `props.Device` field carries the same cloned uuid, not the
  original. `params.LCSC_OF` matches on the netlist's `props.Supplier Part`
  (the LCSC number) instead, which survives the clone unchanged.

- **A placed part's Designator is assigned by placement order within its
  own default prefix, not by anything this file controls.** The crystal
  (`Y1` in this file's own naming) landed on Designator `"U4"`, not the
  USBLC6-2SC6 -- EasyEDA numbers every `"U?"`-prefixed device (chips,
  crystals, LDOs alike) in one shared counter, in the order they were
  placed. Match components by LCSC number, not Designator.

- **A pin placed exactly coincident with another primitive is not provably
  on its net.** A `Ground`/`Power` net flag, or a net port, placed at the
  exact same coordinate as a target pin, with no wire at all, creates
  successfully and reads back at the right position -- but nothing in the
  API distinguishes that from a symbol merely occupying the same pixel.
  `getAllPinsByPrimitiveId()` on the flag itself shows it does have its own
  real connection point; the fix is a short, real, two-point wire from the
  flag's point to the target pin, not reliance on coincidence.

- **`eda.sch_PrimitiveWire.create()`'s coincidence-based net inheritance
  (rule 1 in its own doc comment: "if one endpoint lands on a primitive
  with a net, follow it") does not populate `getState_Net()` the way an
  explicit `net` argument does.** A stub wire from a net flag to a target
  pin, created with `net` left `undefined` so it should inherit the flag's
  declared net by coincidence, reads back `getState_Net() === ''` --
  every time this was tried. The same stub, created with the net name
  passed explicitly, reads back correctly. Pass `net` explicitly; do not
  rely on inference from a touched flag or port.

- **Two wires sharing any coordinate -- not just their nominal endpoints --
  get silently merged into one wire object, and the merge can reassign
  which net the combined object reports.** Confirmed via
  `ISCH_PrimitiveWire.getState_Line()`: a wire object's line array showed
  two unrelated 2-point segments concatenated together after two separate
  `create()` calls happened to touch the same point. In the densest area
  of this board (the ten 100 nF decoupling caps, all at the same y) a
  handful of GND/3V3 flag stub wires ended up merged into the *other*
  rail's wire object despite passing this file's own pin- and
  segment-crossing checks -- meaning the merge criterion is not fully
  captured by "does a registered pin or a previously-drawn segment sit on
  this new segment", the check `schematic.py`'s `elbow()` and
  `_find_clear_offset()` both use. `assert_power_flags()` samples a few
  stub wires per rail with `getState_Net()` rather than trusting placement
  alone, and reports (not silently swallows) any sample that came back on
  the wrong net -- see its own docstring for the exact count on the last
  run.

- **A single-bend Manhattan route between two pins routinely passes
  through a third, unrelated pin on the same crowded column or row, and
  the collision is a real electrical short, not a cosmetic overlap.**
  Every densely-pinned cluster on this board -- the RP2040's own 57-pin
  symbol, the crystal's 4-pad footprint, the flash's two pin columns, the
  USB-C connector's packed 12-signal column -- produced at least one
  wiring attempt where both of the two "obvious" bend points landed on an
  unrelated pin instead of empty space. `schematic.py`'s `elbow()` checks
  every candidate route against every pin on the board
  (`getAllPinsByPrimitiveId()`, read back once after placement) before
  committing to it, and searches a widening set of detour offsets before
  raising -- six pin columns needed that search before a route was found,
  one (the crystal's boxed-in first pin, and the USB-C connector's
  fully-packed 545-655 column) needed a hand-built path instead. A route
  that "looks like" the obvious 3-point elbow is not evidence it avoids
  every pin in between; only checking it against the actual pin list is.

## PCB-side MCU import traps (`place_mcu.py`)

- **`create()` never builds EasyEDA's flying wires.** UniqueIds,
  `pad.modify({net})`, `importChanges()`, and `setNetlist()` can all
  report success while the canvas still has no ratsnest. The path that
  actually creates them is PCB **Design → Import Changes from Schematic**
  (`Alt+I`) against an empty board (or schematic-tab **Design → Schematic
  to PCB** — that item is not on the PCB Design menu). After convert,
  move existing parts (`place_mcu.py --relayout`); do not delete and
  recreate, and do not run `build.py`. Convert dumps SK/LED on TOP at
  schematic-relative coords (negative Y, off the outline); `--relayout`
  puts them on BOTTOM at `params` field positions and keeps the 32 nets.
  Switch holes are not in the schematic; `footprint.place_switch_holes`
  goes back on after the move. After convert, `pcb/cluster.py` packs the
  MCU block by net (crystal on XIN/XOUT, ESD/LDO on the USB tab, flash
  in the next pixel gap). `cluster.py` records the superseded four-layer
  experiment; the finished board uses `stack.py` to require exactly two
  copper layers. `planes.py` creates Bottom GND and Top 3V3 pours, and
  `rebuildCopperRegion()` verifies that both filled copper primitives remain.
  `sch_Net.getAllNetsName()` stays `[]`
  even when `getNetlistFile("JLCEDA")` is complete — do not call
  deprecated `sch_Netlist.getNetlist()` (hangs). The SK6812 symbol's pin
  *names* (1=GND …) do not match its footprint or `PIXEL_PAD_SIGNALS`
  (1=VDD …); convert maps by pin *number*, which is why it still ran.

## The RP2040 reference: GUI-only

Raspberry Pi's Minimal Viable Board reference design needs to come in by
**hand, through EasyEDA's Start Page → Import KiCad**, not by script.
This was checked, not assumed: every plausible import entry point in the
bridge's API reference was read — `DMT_Project` (`createProject`,
`getAllProjectsUuid`, `getCurrentProjectInfo`, `getProjectInfo`,
`moveProjectToFolder`, `openProject` — no import method of any kind),
`SYS_FormatConversion` (the class whose entire job is cross-EDA format
conversion, and it supports exactly two formats, Altium Designer and
T/DISA 4001 — no KiCad), and a grep across the full 120+-class reference
tree for "kicad" (nothing). There is no scripted path in.

The schematic *primitives* the API does expose — `sch_PrimitiveComponent
.create()`, `.getAllPinsByPrimitiveId()` for pin positions,
`sch_PrimitiveWire.create()` with net names — were each proven live
(placed a test component, read its pins, wired a net-named connection,
then deleted all three). They work. What's missing isn't the ability to
place and wire parts by script; it's a source for the reference design's
actual values (LDO part, ESD diode array, crystal load caps, the exact
decoupling network) that doesn't require either clicking Import KiCad or
hand-transcribing a KiCad schematic into individual `create()` calls,
which is authoring the schematic by hand with extra steps. So: import
the reference by hand, then use the script to verify the result — count
parts, check net names, and so on — rather than trying to build the
schematic from the API end to end.

## Re-running the finished routed board

```
cd pcb
./all.sh
python3 plot.py
```

`all.sh` replaces the rounded outline, requires a two-layer stack, applies
placement and silkscreen, routes all signal and power nets, rebuilds Bottom
GND and Top 3V3 pours, requires the EasyEDA Net panel to read `Ratlines (0)`,
checks that all 32 nets are single connected islands, and runs the
review-specific checks in `polish.py`. The reverse-mount LED rectangles are physical board
openings and are obstacles to both the signal router and power-via stitcher.
KEY0 uses y=7.9 mm through the repeated opening/centre-hole passage, the
farthest legal row on the 0.10 mm router grid; KEY3 avoids the narrow
passage. PIXEL2--PIXEL5 must have no 90-degree copper corners.

There are deliberately no board mounting holes. The printed case already
locates and clamps the PCB between its shell standoffs and bottom support
columns; adding holes would consume routing area without adding retention.
The case imports `BOARD_CORNER_RADIUS` from `pcb/params.py`, so its pocket
and the R2.54 mm board corners have one source.

## Manufacturing export and JLCPCB quote

Export the exact open PCB revision, then verify the three files before an
upload:

```
cd pcb
python3 export_manufacturing.py
```

This writes `out/manufacturing/canopy_macropad-gerber.zip`,
`canopy_macropad-bom.xlsx`, and `canopy_macropad-cpl.xlsx`. The exporter checks
that the archive contains both outer copper layers and drill data, and no
inner copper layers; that the BOM contains U1 as W25Q64JVSSIQ / C179171; that the old
unavailable C2940195 XSON part is absent; and that U1 is present in the CPL.
Passing export checks prove file completeness, not DRC cleanliness, so run the
EasyEDA DRC panel immediately before upload.

**And run `./all.sh` before the export, not after.** The exporter runs
none of the design guards -- not `via_in_pad.py`, not `thermal_fanout.py`
-- so it will produce a perfectly complete Gerber from a document `all.sh`
would reject. This is not hypothetical: U3's stock 3x3 exposed-pad via
array reappeared in the live document after one export, nine GND vias
straight through pad 57, which is exactly the via-in-pad this board is
built to avoid. DRC does not catch it either, because a same-net via in a
same-net pad breaks no rule -- it is a manufacturing decision. The first
fabricated boards escaped only because the export happened before the
regression rather than after it. `pcb/BRINGUP.md` carries the two commands
that compare a fabricated drill file against the document at any time.

The board is now a dedicated two-layer redesign: Bottom carries the GND pour,
Top carries the 3V3 pour and backbone, and every signal and power net has an
explicit ordinary-copper path. Do not reuse an older four-layer Gerber archive.

For the intended cheapest partial assembly, start with 5 green FR-4 boards,
2 layers, 1.6 mm, 1 oz copper and the cheapest available HASL finish. Enable
Economic PCBA on the bottom side for 2 boards and
use customer/self-service parts selection. U3 (RP2040) and U1 (C179171 flash)
must be assembled; the reverse-mount LEDs, hot-swap sockets, and SW1 may be
marked DNP for hand soldering. The checked cheaper flash candidates were
Standard-only in Economic assembly, so retain C179171 unless the live parts
filter shows a compatible in-stock Economic option. Recheck live stock and the displayed total before
saving the quote because JLCPCB availability and fees can change after these
files were exported. Never advance from the reviewed quote to payment without
an explicit order instruction.

## Re-running the original key-cell `build.py`

```
python3 pcb/build.py                # place sockets + pixels, DRC, export
python3 pcb/build.py --inject        # last socket placed half a pitch off
python3 pcb/build.py --inject-pixel  # pixel 0's y nudged off its switch's offset
```

Every run opens the named project (`MPAD_EDA_PROJECT` env var, default
`Canopy MacroPad`), clears and re-places the sockets and pixels (never the
switch holes — those are `footprint.py`'s job and a separate call, since
`probe.clear_components()` only clears components, not the holed pads
`footprint.py` places), then checks count, position, pitch, and pixel
pairing before running DRC and exporting fabrication data. `--inject` and
`--inject-pixel` are mutually distinct faults, each proven to make its own
check fail on its own — not inferred from the other's failure. Neither
flag touches DRC or export; those are checked on whatever's actually on
the board regardless of which (if any) injection flag was passed.

`assert_drc()` calls DRC with `userInterface=false`; the call may still exceed
the bridge timeout or fail inside this EasyEDA release. Use the client-side DRC
panel for the manufacturing decision rather than treating this legacy helper
as final evidence.
`export_fabrication()` does not depend on DRC passing; Gerber, BOM, and
pick-and-place all export successfully even with DRC errors present, which
is realistic (a fabricator's tooling doesn't refuse a design with DRC
violations, a human has to catch that first) but also means a green
`export_fabrication()` is not evidence the board is fabrication-ready.

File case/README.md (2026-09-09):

# Canopy MacroPad — case

A two-part printed enclosure for the **custom MacroPad PCB** — one board,
six Choc sockets on 19.05, its own RP2040 and USB-C. Parametric, in
`build123d`; the way to change it is to change a number in `params.py` and
rebuild.
**One layout**, `choc`, and no switch to select it. `params.py` loads
`pcb/params.py` by path, so the board's width, corner radius, switch pitch
and pad positions are read rather than restated — the two files cannot
drift into disagreeing. It is printed, both halves, its
column heights settled on the printed parts, and the bottom that
`COLUMN_SLACK` asked for has been reprinted and fits. The model has since
grown the **slide latch** — ten small hooks along the long sides that
close the middle of the seam, the end hook multiplied — and the latched
case is **printed and working** at `SLIDE_FIT` 0.30 ("perfect" is the
word that came back from the desk). Six prints shaped it, and *The
slide latch* under *How it holds together* carries every turn and why.
The screws are gone -- the latch carries the case alone -- and with
them went the left bay that existed to hold their posts: the case is
**145.27 long now, 5.73 shorter**, and what remains of the bay is a
looks number -- 1.27 that makes the cap margin equal on the three
non-USB sides (3.795 from cap edge to case edge; the fourth side is
the electronics'). **The corners are the corner cap's, grown.** `OUTER_CORNER_R` is
7.995 -- the 3.795 cap margin plus the cap's own 4.2 -- so the case's
corner arc is concentric with the corner keycap's and the border wraps
it at a constant 3.795, straights and arc alike; the shell's top edge
carries `SHELL_TOP_CHAMFER` 1.20, which also serves as the flipped
print's first-layer relief (a 0.50 chamfer applied later inside a
try/except had silently failed at 1.20 -- the bed-inset probe reading
0.35 instead of ~1.2 is what told). The radius has a price paid at the
diagonals: the board's own corner and the case's arc fight over the
same space, and the corner wall is **0.65** -- all the material the
two leave between them, with `CAVITY_CORNER_R` 2.70 the most the board
permits. Less than that and the cavity pokes a slit hole through the
outer face (0.07 at the old 1.00 -- invisible to every interference
boolean, a hole shares volume with nothing); a four-corner leak probe
owns that class now, watched failing at 4/4 on the reproduced fault.

The **detent** pins home in x, and its second
shape is the one that works on a printer: a vertical round ridge on
the mid tab's pocket skin, parking in a notch cut into that eave's
outboard tip -- vertical features in both halves' print orientations,
immune to the slicing that smeared the first cut (a 0.40 bump raised
on the stair-stepped ledge slope, whose spring was also only the
plate's own weight: "theres no bit change"). The spring now is the
skin panel bending 0.15 -- ~1.5% strain, the barb arithmetic passed,
and the same felt force that expanded the shell at the 0.20 fit.
Slide home: drag, click in. Slide back: the same click in reverse, no
special gesture. Home pinned to +-0.30.

Three sections here are about the **earlier device** rather than this one
— *The earlier device*, *Cable, per layout*, and *Stack, in `stacked`* —
kept because that device is still assembled and in use. Its two layouts
are gone from the source, so those sections are a record rather than a
menu: nothing in them can be rebuilt, and the STLs under `out/inline/` and
`out/stacked/` are the only form of them left. *What the checks have
actually caught* is that device's model too — the lessons carry, the parts
do not, and this case's own catches are in the repository's `AGENTS.md`.

## The earlier device: two layouts, and the `inline` one printed

The device before this one was three boards — a NeoKey 1x4 on I2C and two
single-key breakouts on GPIO — driven by a QT Py, and the case came in two
layouts from one source, chosen with `MPAD_LAYOUT`. They differed only in
where the QT Py went, and that one decision moved every dimension:

| | `stacked` | `inline` (default) |
|---|---|---|
| QT Py | under the keys, **face down** | right of the keys, **face up** |
| USB-C | back wall, low | right end |
| size | **135.7 × 27.6 × 17.49** | **158.6 × 25.99 × 13.33** |
| footprint | 37.5 cm² | 41.2 cm² |
| to the top of a keycap | 31.9 mm | **27.7 mm** |
| BOOT / RESET | open the case: they face you | open the case: unclip the board |
| who holds the QT Py | bottom plate, alone | shell from above, plate below |
| Qwiic cable | **100 mm**, down an end bay | **50 mm**, but with 35 mm of slack to fold into a 12 mm gap |
| handedness | either end takes the cable | **right-handed**: the cable can only come off the right socket |

One plate spans all three boards, which is why they are one field and not
three pockets: `KEY_FIELD_W` is `2 × 19.05 + 76.20 = 114.30`, the boards
are the same 21.59 deep and the same 1.570 thick, and the switch pitch
carries straight across the seams with nothing to tune.

`stacked` was the compact one and `inline` the low one. Neither was
strictly better — a shorter pad sits closer to keyboard height, a smaller
one takes less desk.

The four-key inline case, closed with keycaps on, and open with the NeoKey and the QT Py seated in the shell above the bottom plate
`inline` is the layout that exists as a physical object, and it has been
printed twice: **the four-key case in the photograph, and the six-key one
that replaced it** — printed, wired, closing, and the pad in use. The
photograph is the older one; the picture of the six-key unit is the
wiring shot in the main README, shell turned over.

The four-key print took four numbers out of the guess column. It printed
flat, without supports, and closed on the first attempt: `SWITCH_HOLE` at
14.15 (a Durock Ice King seats correctly), `PEG_DIA` at 2.30 (the NeoKey
drops onto the pegs free, with a little play), `QTPY_SLOP` at 0.40, and
the USB-C opening, where a real cable seats fully with about 1 mm around
its housing — worth knowing, because `USB_PLUG_W/H` were never measured
off anything.

One thing the part says that the model does not. The M3 has now been
driven into a post: it goes, but hard enough to be the first thing
anyone says about the part. That
sent `PILOT_DIA` to the coupon, which settled it at 2.95 — the how is
under "Print the coupon first" — and put a Ø3.40 × 0.60 lead-in at every
mouth. The reprinted shell has both and the screw goes in clean.

Then the part nobody was looking at: the bottom plate's screw holes are
tight. They pass a screw, but they guide it, and a clearance hole is
supposed to be free. The obvious answer was the same 0.15 shrink a third
time, and it was wrong — see "Print the coupon first", where two rows of
holes found the real cause under the counterbore. **A plate has been
printed at Ø3.70 with the 0.60 chamfer and it is right**: the bores come
out clean, with no filament hanging in them, and the screws go in easily.
That is the last *printed fit* on this case to stop being a prediction —
every hole, post and pocket has now been felt against the real part.

**Then the six-key unit was wired, and three things came back that no
check could have asked for.** Each one is a fact about assembly rather
than about geometry, which is exactly the class the boolean cannot see:

- **The wires would not lie down.** `UNDER_BOARD_AIR` went 0.40 → 1.40 on
  that evidence, so the gap under the boards is 4.36 and the case 13.33
  instead of 12.33. It bought a shape rather than a size — see *The wires
  have a trench* below.
- **A breakout wants no locating peg.** A plate-mount switch clips into
  the top plate and its pins go into the board's socket, so the switch is
  what ties the board to the plate; the supports set its height and the
  shell presses it down. Removing the pegs also removed the only feature
  that made a breakout look like it had a wrong way round.
- **The field's outer left edge had nothing pressing on it.** A seam is
  between two boards, so the leftmost breakout was held on one side only.
  `EDGE_RIB_W` at 1.50 is the plate reaching down along that edge —
  more bearing area than the 4.20 circle that will not fit there anyway.

And one that was arithmetic all along: the first six-key unit closed with
0.2 of gap at the centre of the seam, because the board stack was holding
the halves apart. `BOARD_CLAMP_SLACK` at 0.20 stops the standoffs acting
as jacks; the rest is the parts not being flat off the bed, which is what
the seam step is for.

**One entry came off this list by being done again.**
`QTPY_STEMMA_NOTCH` at 1.00 was written up as tight — "the plug goes in,
but a reprint would want 1.5–2.0" — on one impression from one print.
Several builds later the plug goes in every time and nothing about it is
a problem, so 1.00 is settled and the reprint knob is not needed. Worth
keeping as a shape rather than a number: **a fit is a claim about a
distribution, and one assembly is one sample.** The numbers on this case
that held up were all felt more than once, side by side or minutes
apart; this one was not, and it read worse than it was. Nothing checks
it either way — `mock.py` builds the mated plug at the receptacle's own
6.00 width, so the plug's width is assumed rather than measured and no
boolean has an opinion.

`stacked` has never been printed at all.

Print target is a **Bambu A1 mini**, 0.4 nozzle, 0.2 layer, PLA Basic.
Both parts print flat and **neither needs supports**. If the slicer wants
supports, something changed — find out what before printing.

## Print the coupon first

There are four, and the small ones exist so that re-asking one question
does not cost a reprint of the answers already settled:
`out/<layout>/coupon-stem.stl` is the keycap mount's slot sweep, which
*Dummy keycaps* covers;
`out/<layout>/coupon-clear.stl` is the clearance-hole row on its own and
`out/<layout>/coupon-hole.stl` is the switch-hole row, three diameters
engraved, on a plate at the real `PLATE_T` -- a Choc v2 clips into that
thickness, so a thicker test piece would answer neither half.
`out/<layout>/coupon.stl` is 68 × 46 mm and takes about twenty minutes.
It exists because a few numbers in `params.py` are things only a printer
can settle, and getting them wrong costs a two-hour reprint:

| Test | What it settles | Status |
|---|---|---|
| switch into the square hole | `SWITCH_HOLE` | **settled at 14.00 on a Choc v2** — all three swept holes take the switch and 14.00 is the one that grips. It won at the bottom of the sweep, so tighter was never printed; the direction of better is tighter and a hole that grips is the whole requirement. `out/<layout>/coupon-hole.stl` asks this on its own, at the real `PLATE_T`, since the plate's thickness has to hold the clips too. The 14.15 above it is the **MX** answer from the three-board case and does not carry over: 13.95 nominal plus this machine's 0.15 hole shrink predicted 14.10, and 14.00 is what grips, so the shrink is not one number across features |
| M3 self-tapper into four pilots, Ø2.50 to Ø2.95 | `PILOT_DIA` | **settled** — 2.95 bites without a fight; 2.50 is the tight one the built case has |
| M3 dropped through four clearance holes, Ø3.40 to Ø3.85, over two transitions | `SCREW_CLEAR_DIA`, `CLEAR_CHAMFER` | **settled, and confirmed on a printed plate** — 3.70 with a 0.60 chamfer is the smallest that comes out clean and falls through |
| a printed cross socket onto a real stem | `STEM_CLEAR` | **settled at 0.00**, across two sweeps and then on the caps themselves. `out/<layout>/coupon-stem.stl` asks it alone, four tokens at 0.00 to 0.10; what the number is really against is the arm's retention ribs, and *Dummy keycaps* carries why 0.00 is a floor rather than an untested edge |
| standoff + peg against a real NeoKey hole | `PEG_DIA`, standoff height | **settled** — the built `inline` case seats the board flat on Ø2.30 pegs |

`PILOT_DIA` was the last one open, and the only one the coupon could
still save a reprint on: it is the guess that fails destructively. So it
is the one test the coupon runs more than once. `PILOT_SWEEP` puts a post
down for every candidate, each engraved with its own diameter, because
the answer is a feel rather than a measurement — the screw that goes in
too easily and the one that needs a fight only separate side by side,
same screw, same plastic, minutes apart. Driving an M3 into all four
picked 2.95.

Two things about that answer are worth carrying. It is **not** where the
arithmetic pointed: 2.95 prints as ~2.80 here, or 0.93× major, against
the 0.83× the tables want. The tables do not know this screw or this
plastic. And it won at the **top** of the range, so the diameter that
strips was never found — **and is deliberately not being looked for**,
because finding it means driving screws into posts until they fail and
the answer changes nothing. 2.95 works. The failure mode is still real:
this number does not split a post on the first turn, it lets go on the
third time the case is opened. If one ever does, re-run the sweep
downward from 2.95.

`CLEAR_SWEEP` is the same idea pointed at the other end of the same
screw, and it took the longest to answer. Its row is a pad raised to the
bottom plate's real `BOTTOM_T`, not the 1.6 the rest of the coupon is:
how free a hole is depends on how many layers it passes through, and it
is the 12 that ships. The counterbore is on the **bed** face, where
`bottom()` puts it, so the through-hole starts 1.00 up and never meets
the squashed first layer — printed the other way up, the coupon would
read tighter than the plate it stands in for and the answer would be
wrong in the safe-looking direction. The labels are on that same face and
mirrored, so the side you read is the side the screw goes in. **Turn the
coupon over for this row.** The right hole is the smallest one a screw
falls through under its own weight while its head is still fully caught
by the counterbore.

When the clearance row is the *only* thing open — which is where this
sits today — print `out/<layout>/coupon-clear.stl` instead. Same holes,
same pitch, same relative positions, on a 57 × 28 × 2.4 pad of its own:
minutes rather than the full coupon's twenty, and no switch-sized hole
spent on a fit that was settled months ago. It shares the row with the
big coupon rather than restating it, so the two cannot drift.

It prints the row **twice**, and that is what settled the number. The
first one printed came back with filament hanging in every bore, and the
geometry says why: the counterbore is a Ø6.10 void and the hole above it
was Ø3.55 at the time, so the layer closing it is a ring 1.275 mm
wide printed over air, all the way round. It sags, and what it sags into
is the top of the hole. **The built bottom plate has exactly this
feature** — the coupon did not invent it, it made it visible — which
means it is a better candidate for why the screws are guided rather than
cleared than the 0.15 hole shrink is.

Sweeping the diameter alone cannot separate those two explanations: it
would find a diameter that works and leave the reason unknown, which is
the same answer a wrong theory gives. So the rows differ only in the
transition — `C0.00` is the plate as it shipped, `C0.60` puts a 45° cone
above the counterbore. **Do not add supports** — the plate prints without
them, so a supported coupon stands in for nothing.

**Both explanations were right, and neither was the variable.** The eight
holes sort perfectly by the width of the ring left unsupported over the
counterbore, which is `(SCREW_HEAD_DIA - dia) / 2 - chamfer` and which
neither the diameter nor the chamfer sets on its own:

| ring | holes | result |
|---|---|---|
| 0.525, 0.600 | 3.85 and 3.70 at `C0.60` | clean |
| 0.675 | 3.55 at `C0.60` | a little sag |
| 0.750 and up | 3.40 at `C0.60`, all of `C0.00` | filament in the bore |

So **0.60 is this machine's limit for an annular ceiling printed over
air** — `CLEAR_RING_MAX`, a constant about the printer in the same way
`SWITCH_HOLE`'s 0.15 shrink is, and it re-measures with it. The plate now
runs Ø3.70 with a 0.60 chamfer, which lands exactly on that limit. 3.85
also passes and was not taken: it buys nothing and costs 0.075 more of
the seat.

That ring is the one dimension in the case squeezed from both ends — it
is *also* the flat the screw head bears on — so `build.py` checks it
against a maximum as well as a minimum, the only clearance here that
gets both.

To re-settle any of it after a filament or nozzle change: print the
coupon, drive a screw into each post, drop one through each hole, set the
numbers to the smallest ones that pass, rerun `build.py`, print the real
thing. The coupon carries the real features at their real sizes — the
plate is 1.6 mm and the post is whatever that layout's post is, 9.3 mm
inline and 13.5 mm stacked — so a fit that works here works in the case.

## Dummy keycaps

The wrk. MX Pure set is ordered and is not here, so `out/choc/keycap.stl`
is a blank 1U to press in the meantime — 0.65 cm³ each, about 0.8 g in
PLA, and six are printed and on the switches.
It carries the photographed cap's envelope, 18.40 square on a 4.20
corner, so the swap when the real ones land changes the plastic and
nothing else.

**The mount is measured rather than looked up.** Choc v2 is sold as
MX-compatible and its stem is not a bare cross: it is an MX cross
standing *inside* a ring, and the cross does not stand proud of it, so
the only way onto it is a boss that goes down the bore. Every number
below was read off `ref/choc-v2.step` with a boolean probe, and
`build.py` reads all twelve back out of that file on every run — a
re-exported or swapped switch model goes red there instead of quietly
redefining what the cap mounts on.

That dependency is **hard**: `build.py` exits if `ref/choc-v2.step` is
not there rather than falling back to the constants, so a fresh clone
runs `sh ref/fetch.sh` before it can build anything. `product.py` has
always needed the same file, but only for a picture — the difference now
is that a missing reference is a case that will not build.

| | size | switch-local z, 0 at the PCB top |
|---|---|---|
| cross, tip to tip | 4.00 | 0.20 → 8.60 |
| cross arm, body | 1.20 thick | the top 0.10 is chamfered off |
| eight retention ribs | 1.30 over them | 4.10 → 8.39, at 1.20 out the arm |
| ring | Ø6.50 outer, Ø5.50 bore | 3.60 → 8.60 |
| fixed housing, top face | — | 5.30 |
| mouth the ring travels through | Ø6.60 | at 5.30 |

Two things follow from the cross tip and the ring rim being the **same
plane**. The cap seats on the *ring*: a Ø6.50 rim resists rocking that
8.6 mm² of cross tip cannot, so the bore is sunk `CAP_SOCKET_OVER` 0.10
past that plane and the cross never carries the press. And the pad that
lands on it has 1.10 of window to live in — wider than the ring's bore
so it bears on something, narrower than the housing's mouth so it can
never come down on the lip. Ø6.00 leaves 0.25 and 0.30, and neither
clears the 0.25 the margin table asks of everything else, so that pair
is checked on its own terms rather than by loosening the table.

**The arms are not 1.20 and that is the whole fit.** Each carries a rib
on each flat — eight of them, 0.05 proud, about 0.10 wide, running
nearly the stem's full height — so what a slot actually meets is 1.30.
They were found by a boolean and not by reading: every probe of the arm
returned 1.200, because a 0.10-wide feature fits between probes, and the
first version of the cap fouled the switch by 0.075 mm³ with no
explanation until the eight pieces of that interference were listed
individually.

`STEM_CLEAR` is measured from the arm **body**, so the number doubles as
how much rib is left alone: 1.20 + `STEM_CLEAR` against 1.30 is the
squeeze, 0.05 per side at 0.00 and none at 0.10.

**The tube is closed on a 0.4 nozzle at boss 5.40, and the number was
found by two failed prints.** At 4.90 the tip walls are 0.30 and
slicing drops them (the six early caps are tip-less and still grip --
the ribs do that); at 5.20 the tips printed but **floated,
connected to nothing**, because the thin spot is not the tip's centre
but the arm's corners, where a cross meets a circle at 0.37. The rule
that fell out is now a margin -- `tube wall at the arm corners`,
anything under ~0.44 is a slicing casualty -- and 5.40 clears it all
round: 0.468 at the corners, 0.55 at the tips, with the mouth gone
width-only (0.15) so its own corners clear too at 0.447. The price is
the ring bore: 0.05 a side, virtually a press. It is an assembly-only
joint (the ring travels with the cap), the boss's tip carries a 0.25
lead-in, and the rib squeeze is untouched -- but **print one cap and
seat it before printing six**; if it fights the ring, the walk-back
is the tip-less 4.90 that six caps already validated.

**Settled at 0.00, on two printed sweeps and then on the caps
themselves** — six printed at 0.00 go onto the switches and fit really
well, which is the claim the tokens could only stand in for.

The sweeps that got there. The first — 0.10, 0.15, 0.20, 0.25 — came
back *0.10 grips, the other three are loose*, and that
is the ribs answering: 0.10 puts the slot exactly on them and every
looser entry clears them by 0.025 or more, which is a cap held by
nothing. So that whole sweep sat at or above the ribs and could only
find the top of its range. The second ran downward — 0.00, 0.04, 0.07,
0.10, the last kept in as the control, because a feel only separates
from another feel side by side, same plastic, minutes apart — and 0.00
is tight enough.

That is the fourth number in this case to win at the **bottom** of what
was printed, after `SWITCH_HOLE`, `PILOT_DIA` and its own first sweep,
**and it is the first one where the bottom is not an untested edge.**
Those three ran off the end of what had been printed, and each carries a
note saying re-run downward from here if it ever disappoints. This one
has a mechanism under it: 0.00 puts the slot on the arm body, so it
squeezes the ribs flat and nothing else, and below it the bore stops
squeezing ribs and starts eating the arm — a different thing to be
doing, and one `build.py` refuses. There is no third sweep to run.

Print shrink sits underneath all of it — this machine pulls a hole in by
0.05 to 0.15 — so the slot arrives narrower than 1.20 and the ribs give
the difference. That is also the failure mode left: a cap that comes
loose after a few pulls means the ribs were shaved rather than
deflected, and the answer is to come **up** from 0.00, because down is
not available.

`out/choc/coupon-stem.stl` is four tokens, engraved, each with the pad
and boss at the heights the cap has them so the slot prints in the same
air. It stays in the tree for the next filament or nozzle: press each
onto a switch, keep the one that grips, set `STEM_CLEAR`, rebuild. They
are four separate tokens on purpose — at 19.05 a single bar would engage
every switch it spans at once, and the question is one slot on one
stem.

**So the interference check had to be split**, because "the bore must
not touch the stem" stopped being true the moment the ribs were known —
the bore is *supposed* to squeeze them. The arm body is a wall and is
checked at 0.000; the squeeze is printed as a **reading rather than a
guard**, since no value of it is wrong in the model and only a pressed
token can say. The envelope that separates the two is built from
the ribs' own measured extent, and what keeps it *on* them is the
read-back, not the envelope: moved 0.50 out the arm it still caught
0.174 mm³ of the cross's flare and looked healthy, the squeeze silently
read 0.000, and the only thing that went red was `arm over a retention
rib` at 1.200 against 1.300. An envelope that misses reads exactly like
a slot that clears.

The cavity's corner radius is **2.00 and deliberately not**
`CAP_R - CAP_WALL`. Rounding a corner pulls the boundary inward along
the diagonal, and the diagonal is where the switch is widest — its
15 × 15 base stands 1.50 proud of the plate, so the skirt passes it at
bottom-out. At 3.00 the cavity reached 10.071 against the base's
measured 10.200 and the two fouled by 0.082 mm³; 2.00 reaches 10.485.
The cost is a corner wall of 0.79 instead of 1.20, which is two
perimeters on a blank.

Watched failing, because a guard nobody has seen go red is not a guard:
the bore against the real cross 3.032 mm³ at `STEM_CLEAR` −0.20, the cap
into the shell 70.851 mm³ with the ride cut to 2.20, into its neighbour
22.725 mm³ at `CAP_XY` 19.50, into the housing the 0.082 above, the
missing seat 0.532 mm³ with the pad at Ø5.00, the bore itself 7.474 of a
wanted 31.409 mm³ when it was cut in the wrong direction — that one was
a real bug, and the volume is what found it — the sweep's four tokens
identical, and the STEP read-back at `STEM_TOP` 8.50.

It prints top face **down**, like the shell: the cavity opens upward,
the pad and boss stand up out of it, the bore opens up, and there is no
overhang anywhere in it. No supports, and the bed face is the visible
top.

## The keyboard mount

`mount.py` builds two stands that perch the case behind a **Nuphy Air75
v2.1**, at the keyboard's own tilt, and writes them to `out/choc/`:

```bash
.venv/bin/python mount.py      # must say all checks passed; also draws mount.png
```

**The keyboard is a tilted rectangle, and that decides the arithmetic.**
Three numbers were measured on the desk with the feet as used: top
plate 13.0 above the desk at the near edge, 25.8 at the far edge, body
133.2 deep. The body is a slab whose near bottom corner stands on the
desk and whose far end the rear feet hold up, so the 12.8 rise over the
133.2 is a **sine** (`KB_TILT` 5.51°), not a tangent (5.49°), and every
face of the slab is square to its plate. The near height then fixes the
slab's thickness: `KB_T` = 13.0 / cos = 13.06. The first drawing of this
had the body as a slab with slanted front and back faces, which put the
mount's front on a lean the keyboard does not have; the first
correction went the other way and leaned the faces *in*. Both were
guesses standing in for one sentence from the person holding the
keyboard.

**Both mounts are the case's own plan outline pushed down to the
desk.** Same 145.47 x 25.99, same R 7.995 corners, drawn in
slab-local coordinates (x along the keyboard, y toward the far end, z
off the plate), tilted about x by `KB_TILT`, and cut flat at z 0. The
front is a plane at the keyboard's rear face, square to the plate, so
the mount butts against the keyboard with no gap; its foot lands 1.24
behind the keyboard's bottom corner, which is where that plane meets
the desk. The two differ in two numbers:

- **`mount-raised`** -- the case bottom on the keyboard's plate plane
  (`KB_T`), slid `MOUNT_OVER` 10.0 toward the user. The case's front
  rests on the keyboard's rear strip and its back on the mount, which
  is only the 16 mm behind the keyboard. The case's plate stands 9.5
  above the keyboard's. 10 is a knob, up to the width of the plain
  strip behind the F row; the strip was never measured with a rule,
  and the print measured it instead -- at 10 the case clears the
  F-row caps.
- **`mount-flush`** -- the case's plate top on the keyboard's plate
  plane (`KB_T` - `CASE_H`), so the two read as one continued slab and
  the whole case sits on the mount. The case bottom is 3.56 above the
  keyboard's underside plane.

**Location is pegs through the plate, not walls, and the shape of that
joint was settled entirely by printing it.** Ø4.50 x 2.30 pegs
(`MOUNT_PEG_DIA`, `MOUNT_PEG_H`) stand in Ø5.00 bores that run **straight
through** the bottom plate at `FOOT_XY`. One diameter, no counterbore, no
step. Engagement is the plate's whole thickness less 0.10, so the pad's
own bottom face lands on the cradle rather than a peg top on a bore end.
Nothing in x depends on the keyboard: the pad is narrower than either, so
its lateral position is a choice.

**A peg keeps its place if enough of it survives the front cut**, which
is measured rather than guessed from where its centre lands. The Air75's
raised mount overhangs 10.0, its front pegs sit 3.0 forward of the face,
and what would be left is a 0.75 fin -- so that pair is dropped and the
rear two locate it. The K11 overhangs 5.97 and keeps 3.28 of each 4.50,
so it has all four. A rule written on the centre instead threw the K11's
front pair away for a revision, and every other check passed while it
did: the pad still caught on two pegs, and the cradle probe reads the
cradle rather than the peg standing on it. `mount.py` counts them now.

*It began as the rubber feet's Ø8.00 x 0.50 recess with a Ø7.50 x 0.40
peg in it -- printed, fitting, and holding by 0.40, which resists tilt
and barely resists sliding. On a slope, sliding is how it comes off.*
Two attempts to deepen it failed in PLA before the shape stopped
changing. Blind at 1.20, the bore caught stringing under a ceiling
bridged over air, in the one place nothing reaches in to clean. Opened
through, the **step** was still there: Ø8.00 narrowing to Ø5.00 leaves a
1.5-wide annular ledge printed over the void below it, and a ring of
unsupported overhang droops into the bore. **Any change of diameter is
that ledge**; the fix was to have no change of diameter.

The peg's Ø4.50 is reasoned rather than swept. The one fit this project
settled on printed parts is Ø7.50 into Ø8.00 -- 0.50 nominal, 0.35 after
this machine's 0.15 hole shrink -- and the ratio does not transfer, but
that **effective** clearance does: 0.50 nominal at Ø5.00 leaves the same
0.35. Printed, it fits. `MOUNT_OVER` 10.0 against the Air75's F-row caps
is likewise a value that works rather than a range whose ends were felt.

**The rubber feet are retired.** A Ø5.00 bore through the plate cannot
seat a Ø8.00 foot, and they were not being used at either desk -- the pad
lives on a mount. One bottom plate serves every mount here.

**Print with the desk face down.** It is the one flat face; the
cradle is then a 5.5° top surface and nothing overhangs. The block is
modelled solid (61 cm³ raised, 66 flush) and the slicer's infill is the
weight reduction. The desk edge gets `ELEPHANT_CHAMFER`.

**What the checks watch** -- all in `mount.py`, against a keyboard
stand-in (the slab, 320 wide), a case stand-in with its foot recesses,
and a plug in the case's USB-C port: the desk face at z 0 and nothing
below it; mount, case and keyboard pairwise at 0.000 with the pegs in
their recesses; the pegs catching a case shifted 1.0 in each of ±x, ±y
(3.9 mm³ raised, 7.9 flush); the case's plate top at its near edge
against the arithmetic (34.295 raised, 25.800 flush); a probe just
ahead of the front face lying wholly inside the keyboard, so the two
faces touch; a probe under the overhang lying wholly inside the
keyboard, so the raised case rests on it with no step; and a probe
under the rest of the case lying wholly inside the mount, so the
cradle is solid to the surface. Watched to fail: pegs moved 2.0 in y,
9.926 / 19.853 mm³ against the case; tilt sign flipped, the keyboard's
far corner reading 0.200 for 25.800 before the desk chamfer failed on a
part that had none of its edges where it expected.

### The second keyboard: a Keychron K11 Max

**It is a different solid, and that is the whole lesson.** The Air75 is
a tilted rectangle; the K11 Max is a **wedge** -- its bottom is one flat
plane lying on the desk, and only the top plate is tilted. Nothing was
measured with a tape here: Keychron publish their CAD, and
`k11-Max-US-Knob-Version-Full-Model.stp` says the bottom is a single
33,000 mm² planar face standing 3.33° off the plate's normal, which is
also the feet-up typing angle they publish. Front and rear faces are
square to the plate exactly as on the Air75; what differs is where the
rear face meets the desk. `_build` takes the two numbers that follow --
the tilt, and how high the pad's bottom sits at that face -- and each
keyboard has a thin function that works them out its own way.

Measured off that STEP, in desk coordinates: 117.65 deep, 345.37 wide,
top plate 14.54 above the desk at the rear face, USB-C port 7.19 to
13.19 up that face and 21.03 left of the case's centre.

**The plug picks the height.** Level plates would put the macropad's own
case at 5.04 to 14.54 up the rear face, straight across the port -- and
a case cannot be relieved, only moved. Raising it to the plate plane
clears the port's top edge by 1.35, which makes the plate plane the
lowest position that works rather than a matter of taste. The mount
still crosses the port, and a mount *can* be cut.

**The pad follows the keys, not the base.** Six keys stand off to the
right of the Alice cluster and drag the field's extent back onto the
case's own centre -- 68 caps span x 9.52..345.49, mid 177.50 against a
case centre of 176.30, which reads as "centred" and is misleading. The
62 keys anyone types on sit at 158.37, **17.94 left**, and that is where
the pad goes. It also buys reach: the pad's underside rides the plate
plane, so any cap under it is a collision, and the limit is 3.50 centred
against 6.47 on the keys. The limit holds flat from -17.94 to -24.30, so
the offset the keys ask for is already on the plateau. `K11_OVER` takes
5.97 of the 6.47, and the 0.50 also keeps the front pegs whole -- their
leading edge is at 3.25 - `K11_OVER`.

**The cable, not the plug, shapes the front face -- and four printed
rounds shaped it, not the model.** The L-plug needs a pocket, 30 x 17
with its floor at 2.0, clearing a plug grown 4.0 every way. But the cable
leaves that plug **straight right**, has to get out past the pad's right
edge, and does **not** lie on the desk: it floats around the middle of
the keyboard's base height. So the relief is a slot at the cable's own
height, 14.0 back from the face, running from the pocket's left edge out
through the right end. It takes an 8.0 cable.

Every number in it moved once a printed mount met the real keyboard:

- **The pocket sits 7.0 right of where the STEP put the port.** Whether
  the model's plug solid is off or the L-plug's body is not centred on
  the socket, the keyboard on the desk is what has to be cleared, so
  `K11_PORT_X` carries the correction.
- **The ceiling was hit, twice.** The slot was centred on the cable at
  3.87..12.37, leaving 0.88 of plain material above it doing nothing --
  taking that reached 13.05 and still caught. So the cradle itself thins
  over the slot to `K11_SLOT_ROOF` 2.2, measured at the front face, which
  is its thin end (the plate climbs 0.815 across the slot's 14 of depth).
  Top is 14.04 now, 1.67 above where the first print failed. That roof
  bridges 14 as about five walls on a 0.4 nozzle; the pad on it weighs
  little and the rear wall carries the span's far edge.
- **The right-hand exit was too small.** 1.0 past the pad's edge was
  enough on paper; the cable carries further right before it leaves and
  caught the end. 6.0 now. Nothing bears on the last few millimetres of
  that wall.

Two shapes were wrong before those, and the cable stand-in caught both
without a print: a 10-deep step in the face, drawn against a cable
sloping 27 rearward per 97 right, at 330.9 mm³; then a channel cut to the
desk, which cleared the cable only by taking the floor with it.

**There is no post at the right end, and there cannot be one.** Nothing
that ties floor to cradle through the front wall can stand anywhere right
of the port, because the cable exits there -- and a post with a hole cut
for the cable is the same solid as a slot running to the edge. It was
never needed: what ties floor to cradle is the rear wall, 3.0 thick and
full height along the whole length, plus the back of each rib behind the
slot.

**The mount is a shell with a floor.** 3.0 walls on the pad's outline,
ribs on 22.0, cradle solid on top, and the desk face **closed** -- 2.0 of
floor. Open, the first layer of a 145 mm part is a 3.0 outline plus a few
rib ends, a poor grip on the bed for something that long and 21 deep;
closed, the first layer is 2793 mm², the section resists twisting, and it
stands on an area rather than an edge. 22.5 cm³ against 48.6 solid. Print
desk face down: the cradle bridges each bay and the slot, and nothing
overhangs.

**The keyboard sits 1.70 off the desk on rubber strips, and that is the
only place the CAD is wrong.** The section reads 14.54 from the case's
bottom to the plate at the rear face; the strips measure 1.70; the plate
above the desk measures 16.30. 14.54 + 1.70 = 16.24 against that 16.30 --
**two measurements that did not have to agree do**, which is what says
the section is right and puts the whole difference in the feet. Keychron's
own model has those strips at 1.105 and publishes 15.6 to match, so CAD
and catalogue agree with each other and not with the desk. Every height
here rides on `K11_FOOT_H`, the port's included.

**What the K11's checks watch** -- against a wedge stand-in built from
those measurements, a case stand-in with its bores, an L-plug and a
cable: desk face at z 0 with nothing below; mount, case, keyboard, plug
and cable pairwise at 0.000; the pocket clearing a plug grown 4.0 and the
slot an 8.0 cable; the slot open at the right end so the cable can leave;
the roof over it thick enough to print; the pocket removing material at
all; the shell under 0.75 of solid; the pegs catching a case shifted 1.0
**along the plate** in each of ±x, ±y; and cradle under every peg.
Watched to fail: pocket removed, 421.6 mm³ against the plug; hollow
disabled, 0.845; pegs moved 2.0, 9.926; `K11_OVER` at 14.0, the cradle
gone from under two pegs; the slot stopped 10 short of the right end,
265.1 against the cable and 63.9 in the exit probes; the roof at 0.6,
0.718 against a floor of 1.6.

## Cable, per layout

**The earlier device.** Both layouts here are gone from the source, and
this case has no Qwiic cable at all — one board, with the keys, the
pixels and the MCU on it — so nothing below applies to it. The whole
question went away with the boards rather than being answered somewhere
else.

**`inline` uses the 50 mm cable you already have.** The two sockets end up
facing each other 12 mm apart, so the run is trivial — but 50 mm is the
shortest Qwiic cable anyone sells, and the other 35 mm has to be folded
into the gap. It fits; it is not tidy.

**`stacked` does not.** Stacking puts the sockets about 8 mm apart
vertically and at opposite ends of the case; the run is roughly 60 mm
before bends. Either:

- a **100 mm STEMMA QT / Qwiic cable**, or
- **soldered wires** to the NeoKey's `JP1`/`JP5` headers. Nothing in the
  case needs changing for this: wire takes less room than a plug, and the
  channel is sized for the plug.

The old argument for the cable — that it keeps the pad solder-free — is
gone either way. The six-key field needs five soldered wires, and the
`JP1`/`JP5` header is where two of them already land.

## Build

    uv venv --python 3.12 .venv
    uv pip install --python .venv/bin/python build123d trimesh matplotlib
    .venv/bin/python build.py      # must end in "all checks passed"
There is **one layout now**, `choc`, and it writes into `out/choc/`.
`MPAD_LAYOUT` is gone with the two it used to select: `params.OUT_NAME` is
the name, and it is not a switch. The `inline` and `stacked` directories
under `out/` are the older device's, kept because they are the only
remaining form of a case that is physically in use — the source that
produced them was removed with the layouts.

    .venv/bin/python section.py    # sections.png -- cut through the stack
    .venv/bin/python render.py     # *.png -- shaded views
    .venv/bin/python product.py    # product.png -- assembled and exploded

    .venv/bin/python webgl.py dump
    .venv/bin/python webgl.py page                    # -> out/viewer.html

**Run all five after every geometry change.** `build.py`
rewrites only the STLs and STEPs, so a partial sweep leaves the renders
and the viewer describing the previous shape, which reads as verified
rather than stale. Note that the shell's exports come out byte-different
on every run even when nothing changed — see `AGENTS.md`; compare the
geometry, not the bytes.
**The viewer is live at <https://saqoosha.github.io/Canopy-MacroPad/>**,
served off the `gh-pages` branch, which holds nothing but this one file
as `index.html` plus an empty `.nojekyll`. It is a copy, so it goes stale
on its own — regenerate `out/viewer.html`, then republish it:

    blob=$(git hash-object -w case/out/viewer.html)
    empty=$(printf '' | git hash-object -w --stdin)
    tree=$(printf '100644 blob %s\tindex.html\n100644 blob %s\t.nojekyll\n' \
             $blob $empty | git mktree)
    git branch -f gh-pages $(git commit-tree $tree -m 'Publish the case viewer')
    git push -f origin gh-pages

Plumbing rather than a checkout on purpose: nothing here touches the
working tree, so there is no orphan branch to get stranded on and no
chance of committing the rest of the repo onto a branch that should
carry one page.

`out/viewer.html` is the one to actually look at. `product.py` sorts
triangles by distance and paints them back to front, which is the only
depth test matplotlib offers and is wrong wherever two surfaces
interpenetrate or one is concave — most of this case. The viewer hands
that to a GPU depth buffer and the artefacts disappear. Both layouts,
orbit, explode, per-part visibility, one self-contained file with the
geometry embedded as int16.

It has **orthographic projection and Top / Front / Left presets**, which
is what makes it usable for reading the design rather than admiring it —
in ortho a height is a height, and the plan view puts all six keys on
one line with no foreshortening to argue with.

Four things in it were not obvious:

- **The canvas's own antialiasing does nothing here.** `antialias: true`
  only covers what is drawn straight to the canvas, and every pass goes
  into an offscreen framebuffer first. The targets are supersampled and
  box-resolved in the composite instead — simpler than multisampled
  renderbuffers with a blit per attachment, exact rather than pattern-
  based, and it antialiases the transparent edges too. It costs real
  fill, so the frame is only redrawn when something actually moved.

- **The case has a glass mode**, which is the whole reason the viewer is
  worth having: the pad is only ever *used* shut, and exploding it to see
  the inside answers a different question. Turning the two printed parts
  translucent needs nothing special once transparency is
  order-independent — their near walls blend over the boards and their
  far walls fail the depth test against those same boards and drop out.

- **Transparency is order-independent** (weighted-blended, McGuire &
  Bavoil), not sorted. Sorting by object cannot be right here — a
  keycap's skirt and the switch housing inside it interpenetrate, so no
  ordering of that pair is correct from every angle. The canonical weight
  function had to be replaced: it is tuned for many nearly-transparent
  fragments, and at these alphas every fragment pinned to its clamp and
  the accumulation degenerated into a flat average — four keycaps
  rendered as one fog.
- **The boards are bare slabs, and that is a trap**, so there is a
  *Clearance envelopes* toggle that draws what `build.py` actually
  booleans against: hot-swap sockets, both STEMMA receptacles with a plug
  mated, the USB shell and its overhang, the tact buttons. What you look
  at and what was verified are otherwise two different models, which is
  the same gap that produced most of the bugs listed above. The envelope
  has the **board subtracted out of it** — the check's stand-in and the
  viewer's slab are the same board, same outline, same Z, and drawn
  together they were coplanar everywhere and tore at each other. What is
  left is exactly what the check claims *beyond* the board, which is the
  more useful picture regardless.

`product.py` and `webgl.py` are the only files here that are not
load-bearing. Their keycap and switch shapes are eyeballed, nothing checks
them, and no dimension in either feeds anything else — they exist so the
pad can be looked at. The keys wear the status colours from the main
README, since what this device is *for* is the one thing a picture of it
should say.

There is no hole over BOOT or RESET in either layout. They are needed
once, to write a CircuitPython UF2; after that a firmware update is a
file copied to CIRCUITPY. Four screws is a fine price for something done
once. The buttons are still modelled, and nothing is allowed to press on
them — widen a rail over one and the interference check reports 68.9 mm³
and fails.

`build.py` ends in a report, and the report is the point. It re-derives
the stack, prints every clearance that is not implied by something else,
then booleans both printed parts against stand-ins for the boards, the
switches and a mated Qwiic plug — and against each other. Anything left
over is a case that cannot be assembled. **Do not print on a run that
says `SOMETHING IS WRONG`.**

`out/*.stl` are already lying the way they print — the shell comes out
plate-face down. Do not rotate them.

## What the checks have actually caught

Every one of these is from the **earlier device's** model — the QT Py, the
NeoKey and the two breakouts — because that is where the checks were built
and where they earned their keep. The parts are gone; the lessons are the
reason the checks exist at all, and they are why this case's stand-ins
model mated plugs and real component faces rather than boxes. What this
case's own checks have caught since is recorded in the repository's
`AGENTS.md`, under "Editing the case".

Not a hypothetical list. Every one of these was in the model and none was
visible in a render. Three of them are the *same* mistake in three
different places — a wall that fits the board and seals off the socket
its cable plugs into — which is why every stand-in here models mated
connectors and not bare receptacles:

- a QT Py pocket wall standing 1.6 mm inside the NeoKey.
- **that pocket's front wall sealing off the socket the Qwiic cable plugs
  into.** The board fitted; the cable could never have reached it. This is
  why the stand-in includes a *mated plug* rather than just a receptacle —
  the receptacle alone fits fine.
- **the same thing again after the redesign**, in the bottom plate's front
  stop, with the socket now facing down instead of forward.
- retaining lips landing on the BOOT and RESET buttons, which stand 1.94
  proud of the face they are on and clear the rails by 0.2.
- the pocket's side walls running 1.4 mm into the shell's back wall —
  caught by the shell-versus-bottom-plate check on the first run after it
  was added.
- an M3 screw post landing on the mated Qwiic plug — **while the margin
  check that was supposed to prevent exactly that read green**, because it
  measured to the NeoKey's board edge and the plug sticks out past it. The
  boolean caught what the arithmetic missed; the arithmetic was corrected
  afterwards.
- the NeoKey's support columns growing with the screws, because they were
  sized off `POST_DIA` and are not screws at all. They have their own
  `COLUMN_DIA` now.
- **two bottom-plate columns standing through a breakout's hot-swap
  socket** — and this one the checks did *not* find, the assembled part
  did. The stand-in drew the socket as one box around its body, so it
  missed the solder wing off each end; and the back face was never
  mirrored for the fact that the board is turned over to put its switch
  side up, so the whole of it sat on the wrong side. Both are fixed at
  the source: `BREAKOUT_BACK_PARTS` is every part on that face as the
  STEP has them, mirrored once on the way into case space.
- **the whole board stack sitting 0.16 too low**, the same disease one
  level up. The deepest thing under a board is not the hot-swap socket at
  1.85 but the STEMMA receptacle at 2.96, and that was modelled on the
  other face where nothing had to clear it. `SOCKET_CLEARANCE` had been a
  hand-written 2.80 reasoned from the socket; it comes from
  `UNDER_BOARD_MAX` now. The printed case closes on a NeoKey pressed into
  the bottom plate — too little to feel, enough to strain the boards, and
  invisible to every check because the model had the part on the far
  side. The case grows 0.56 to fix it.
- **a NeoKey support column standing through the middle of the QT Py** in
  `stacked`, 116 mm³ of it, the moment the key field grew to three
  boards. The NeoKey stopped starting at the field's left edge, so its
  first pair of mounting holes landed at case `x = 0` — where the QT Py
  had always sat. Nothing about the change looked like it was near the
  QT Py; the boolean is the only reason it was not printed that way. The
  QT Py now sits at `x = 19.05`, the centre of the widest gap the columns
  leave, and USB-C is no longer centred on the back wall as a result.
- **the bottom plate blocking the USB plug** — and this one the checks
  did *not* find, a person looking at the render did. The opening's lower
  edge lands exactly on the seam between the two printed halves, and the
  plug's overmold hangs below it, so the plate stopped the plug about a
  millimetre short of seating. Nothing flagged it because the stand-in
  modelled the *receptacle* and not the plug that has to reach it — the
  same omission the Qwiic sockets had already taught three times. The
  plug is modelled now, both halves are relieved to plug size, and the
  check fails without either relief.
- the USB-C opening and its envelope both drawn as rectangles. A USB-C
  shell is a stadium — fully rounded ends, radius half its height — so
  the square envelope was claiming four corners that do not exist, and
  the square hole was the wrong shape to put it through. Both are
  stadiums now, built from two circles and a rectangle rather than a
  rounded rectangle, which cannot express a radius of exactly half the
  height.
- a sharp-cornered switch fouling a 0.3 mm plate-hole corner. The spec
  allows 0.3 max; the model gives way to 0.2 rather than the mock being
  softened, so the check keeps meaning something.

And one thing the checks did **not** catch, recorded because the mistake
was in believing they had. A Ø5.0 standoff between two keys was reduced to
Ø4.2 on the stated grounds that the check flagged it. It never did: 5.0
clears a 14 mm switch body by 0.025 mm a side, and the 0.009 mm³ that was
blamed on it came from the plate-hole corner instead. 4.2 is still right —
0.025 is not clearance on a printed part, it is the tolerance — but it is
a judgement call, not a finding. Fault injection is what settled it: at
Ø6.0 the check reports 1.016 mm³ and fails, so it does fire, just not
where it was credited.

## Stack, in `stacked`

**The earlier device.** This layout is gone from the source; the numbers
below describe a case that can no longer be rebuilt. Kept because the Z
argument is the same argument this case has, one board fewer.

This one is the `stacked` layout, which is where the Z fight is —
`inline` puts the QT Py beside the keys instead of under them and comes
out 13.33 tall against 17.49. Z is measured from the outside of the bottom
plate. Read it bottom-up — the USB-C shell is the lowest thing in the
case now, and everything above is stacked on that one clearance.

```
 0.00  ├── bottom plate                    2.40   12 layers; the M3 button
 2.40  ├── floor                                   head's bore eats 1.0
 2.80  ├── USB-C shell                     4.20   hanging off a board that
 6.00  ├── QT Py PCB                       1.57    is lying face down
 7.57  ├──   its underside parts           1.10   now pointing up
 8.67  ├──   air                           0.40
 9.07  ├── hot-swap sockets                1.85
10.92  ├── NeoKey PCB                      1.57
12.49  ├──   gap                           3.40
15.89  ├── plate underside
       │   plate                           1.60   8 layers at 0.2
17.49  └── plate top                              → 5.00 above the PCB, per spec
```

Depth is set by the QT Py, not the NeoKey: 20.70 of board plus 2.50 for
the mated Qwiic plug ahead of its socket, plus two walls. Packing it
tighter is possible on paper — 25.99 with the board turned 90° into a
corner — and unbuildable. A screw post has to miss the NeoKey above it
*and* the bottom plate's own columns, which leaves only the two end bays,
and an end-mounted QT Py fills one of them. 1.6 mm of depth was the
cheaper thing to spend.
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

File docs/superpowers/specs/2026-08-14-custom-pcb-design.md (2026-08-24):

# One board, six keys

Replace the three Adafruit boards and the QT Py with a single custom PCB,
assembled by JLCPCB. Smaller footprint, and a low-profile switch option
that the current stack cannot express.

Nothing above the device changes. `PROTOCOL_VERSION` stays 3, `HELLO 3 6`
stays, and the macOS half is not touched.

## What this is measured against

The six-key wired pad, built and working:

| | today |
|---|---|
| boards | NeoKey 1x4 + 2 x 4978 breakout + QT Py RP2040 |
| case (`inline`) | 158.60 x 26.00 x 13.33 |
| key field | 114.30 x 21.59, six switches at `9.525 + n x 19.05` |
| wiring | five hand-soldered wires plus a 50 mm Qwiic cable |
| key reads | four on I2C seesaw, two on GPIO, one index space |

## One switch, and why the other two had to go

~~The pad has to take three switches off the same board.~~ **It cannot,
and the claim was mine to check and I did not.** MX and Choc hot-swap
holes do not fit in one position. Measured, from Adafruit's NeoKey for
the MX side and `foostan/crkbd`'s Choc board for the other:

| pair | centres | radii need | result |
|---|---|---|---|
| MX pin b / Choc pin a | 2.669 | 3.055 | **0.39 overlap** |
| MX pin a / Choc pin b | 1.733 | 3.055 | **1.32 overlap** |
| MX post r / Choc post r | **0.42** | 1.857 | **1.44 overlap** |

The alignment posts sit 0.42 apart and need 1.86. This is not a
tolerance argument.

Two things corroborate it. **`kiswitch` is a generated, maintained
library and ships MX+Alps hybrids but no MX+Choc hot-swap hybrid** --
the gap in a thorough library is itself evidence. And the one MX+Choc
combo footprint that does exist, `siderakb`'s, is **through-hole only**,
where the pins are Ø1.5 and Ø1.27 and genuinely do fit. Hot-swap needs
Ø3.0 barrels for the socket, and those do not.

So the board is **Choc v2 only**, chosen over MX-only, two boards, or
going THT. The cost is stated plainly because it is real: **it will not
take the GTMX or the Durock already on the desk**, and no Choc v2 has
ever been in hand here — so the first board and the first switch have to
arrive together or nothing can be checked.

What survives from the three-switch idea is the reason it was attractive:
**Choc v2 takes MX keycaps**, so the keycaps are unaffected and 19.05
stays the pitch.

### The old comparison, kept because it is what forced the decision

Read out of the manufacturers' drawings, not product pages:

| | full MX (Durock Ice King) | Outemu GTMX | Kailh Choc **v2** |
|---|---|---|---|
| drawing | -- | GaoTe `PG618B65` | Kailh `CPG135301D01` |
| **keycap stem** | MX cross | **MX cross** | **MX cross** |
| plate cutout | 14.00 | **14.00** | **13.95 ± 0.05** |
| PCB to plate top | 5.00 | **5.00** | **2.20** |
| plate thickness | 1.50 | **1.50** | **1.30 ± 0.03** |
| body | 14.80 sq | 14.80 sq | 15.00 sq |
| PCB pattern | Ø4.00 + 2 x Ø1.50 | **same** | Ø5.00 + 2 x Ø1.20 + Ø1.60 |
| hot-swap socket | Kailh MX | **Kailh MX** | Kailh PG1350, shared with v1 |
| LED window | 3535 | **2835** | placed in the recommended layout |
| travel | -- | 3.0, pre 1.2 | 3.2 ± 0.25, pre 1.3 ± 0.3, 50 ± 10 gf |

**Choc v2 rather than v1, and the reason is the keycap.** The v2 swaps
v1's 3.40 rectangular stem for a **5 mm MX cross**, so the MX keycaps
already owned still fit and nothing has to be bought twice. It also
means **19.05 is mandatory rather than merely convenient**: MX keycaps
on Choc's own 18 x 17 spacing collide, so a board that offers MX caps
has to be on MX pitch. This design already is, so the trap is avoided by
construction and `SWITCH_PITCH` never becomes an axis.

### The cell, borrowed rather than derived

Every number below is off a board that ships, because four separate
times in this design a figure read from a drawing turned out to be
wrong in a way no arithmetic would have caught. Sources: `foostan/crkbd`
`keyswitch_choc12_hotswap_1u` and `YS-SK6812MINI-E`, cross-checked
against `ebastler/marbastlib`.

| | offset from switch centre | size |
|---|---|---|
| centre (switch boss) | (0, 0) | Ø5.0 |
| pin | (0, 5.9) | Ø3.0 |
| pin | (5, 3.7) | Ø3.0 |
| alignment posts | (±5.5, 0) | Ø1.9 |
| v2 mount | (-5, -5.15) | **oval** 1.5 x 2 |
| socket pads | (8.1, 3.7), (-3.1, 5.9) | 2.3 x 2.6 |
| **pixel** | **(0, -4.74)** | opening **3.6 x 3.1**, pads (±2.8, ±0.7) 1.7 x 0.825 |

**The Ø5.0 is the switch's mounting boss, not a light path** -- a
mistake made here first, which then produced two more: that Choc needed
no opening, and that it needed a 2020 rather than the SK6812MINI-E. Both
wrong. Corne cuts a 3.6 x 3.1 opening and uses the same SK6812MINI-E
this board already specifies.

The pixel offset is the one number with two independent witnesses: 46
switch/pixel pairs on Corne's Choc board measure 4.737-4.749 along the
key's own axis, and marbastlib's Choc add-on carries an alignment arrow
its author drew at 4.7. Two designs with no shared author agreeing is
the strongest evidence available short of a fabricated part.

Its socket is the PG1350 one that v1 uses, so the switch choice does
not add a part. Its footprint is its own -- 3 pins against v1's 5, and
a centre hole that grows Ø3.40 to **Ø5.00** for the fatter centre pin
-- which is what the combo footprint has to carry.

**And its plate cutout nearly is the MX one already printed here.**
13.95 plus this machine's 0.15 shrink lands at 14.10 against the 14.15
that a Durock seats in: **0.05 apart, which is under the tolerance this
printer works to.** Whether one hole serves both is a question for the
coupon and not for arithmetic, but it is a much smaller question than
two plates.

What does differ is thickness. MX wants 1.50 and this case prints 1.60;
Choc v2 wants **1.30**, and the switch's clips are what that number
feeds. So the case axis reduces to two entries -- the plate's height
above the board, and its thickness -- rather than a second geometry.

**GTMX is MX below the plate and short above it.** Its cutout, its PCB
pattern, its socket and its 5.00 are the numbers this case already has --
so it changes the case by nothing at all, and takes 3 mm off the top of
the keycap. That is the whole reason it is the primary switch here.

Choc is the only one that moves the stack, and it moves it by 2.80.

So the board carries a **combo footprint**: the MX pattern and the Choc
pattern on the same pads, an arrangement that is standard practice and
has existing KiCad libraries (`kiswitch/keyswitch-kicad-library`,
`50an6xy06r6n/keyboard_reversible.pretty`). One PCB, three switches, and
the switch is chosen when the sockets are soldered rather than when the
board is ordered.

Both patterns sit on the same 19.05 pitch. Choc keycaps are 18.00, so
they leave 1.05 of gap where MX leaves nothing -- accepted, because the
alternative is two board revisions.

## The board

**121.60 x 21.59 mm**: the key field at 114.30, plus 7.30 at the right
end for the USB-C receptacle. 1.60 thick, four layers -- the RP2040 wants
a ground plane under it and a two-layer board would have to buy that
plane with routing space this outline does not have.

### Everything is on the back face

The back of a keyboard PCB is not empty -- the hot-swap socket already
forces 1.85 mm of clearance under it, and this case already carries that
clearance as `SOCKET_CLEARANCE`. Everything on the board fits inside it:

| part | height under board |
|---|---|
| Kailh MX hot-swap socket | 1.85 |
| RP2040, QFN-56 | 0.90 |
| QSPI flash, SOIC-8 | 1.75 |
| 12 MHz crystal, 3225 | 0.80 |
| LDO, SOT-23 | 1.10 |
| 0402 passives | 0.50 |

And there is room in plan as well as in Z. The socket occupies
y 11.65 - 17.55 of the field's 21.59 depth (measured off
`ref/neokey-breakout.step`, the one Adafruit model that includes its
socket), which leaves a band roughly 114 x 11 running the whole length of
the board under the switches.

The one part that does not fit is the USB-C receptacle at 3.16. It gets
a local pocket in the bottom plate, which is 2.40 thick and can give up
1.00 without argument.

**So the assembly is single-sided.** The top face carries switch pads and
nothing else. That is a real saving on a PCBA order, and it is a
consequence of the geometry rather than a goal that bent it.

### Bill of materials

- RP2040, `C2040`. Stocked at JLCPCB for both Economic and Standard
  assembly.
- QSPI flash, 8 MB, to match the QT Py RP2040 -- see "The firmware that
  is already written" below.
- 12 MHz crystal, 3.3 V LDO, decoupling per the RP2040 hardware design
  guide, BOOT button.
- USB-C 16-pin receptacle, 2 x 5.1 kΩ CC, ESD diodes.
- Six **SK6812MINI-E** reverse-mount addressable RGB, one per key,
  `C5149201` at JLCPCB. Same controller family and same mount style as
  the NeoKey's, which is the point: the status colours in `README.md`
  were tuned on reverse-mount SK6812-class pixels and stay valid.
  Adafruit's own description of the NeoKey -- "mounted on the back of
  the board to shine through to the top" -- is the arrangement this
  board copies.

  Its body is a 3528, i.e. 3.5 x 2.8, which is the same package GTMX's
  drawing calls for by its other name, 2835. That is not luck; it is
  the size keyboard switches leave room for.

  **`SK6812MINI-E` and `SK6812MINI-EA` are not interchangeable on an
  order.** One is reversed in the tape and one has to be placed
  upside-down by explicit instruction to the assembler. Getting this
  wrong lights the inside of the board six times over, and the boards
  arrive looking perfect.
- Six Kailh hot-swap sockets, MX or PG1350, **hand-soldered after the
  PCBA order**. They are the one thing the board must not have decided.

**No diodes and no matrix.** Six keys go straight to six GPIO with
internal pull-ups; a press pulls its pin low. The RP2040 has thirty
GPIO and this board needs seven, so a matrix would save no pins and
would buy a ghosting argument that direct wiring never has to make.

### The firmware that is already written

Wire the six key pins and the LED chain to the **GPIO numbers the QT Py
RP2040 uses**, and put the same 8 MB QSPI flash on the board. Then
Adafruit's released CircuitPython UF2 runs on it unmodified -- no board
definition to author, no toolchain to build, and `board.MOSI` goes on
meaning the pin it has always meant.

From `ports/raspberrypi/boards/adafruit_qtpy_rp2040/pins.c`:

| name | GPIO | | name | GPIO |
|---|---|---|---|---|
| `MOSI` | 3 | | `TX` | 20 |
| `MISO` | 4 | | `SDA` | 24 |
| `RX` | 5 | | `SCL` | 25 |
| `SCK` | 6 | | `A3`..`A0` | 26..29 |
| `NEOPIXEL` | 12 | | `NEOPIXEL_POWER` | 11 |

Eleven pins are broken out and seven are needed. The GPIO chosen for
keys and for the LED chain are a layout convenience -- every one of them
is an ordinary GPIO -- so this costs the routing nothing.

`NEOPIXEL` (GPIO12) is deliberately **not** the LED chain. On a QT Py it
is gated by `NEOPIXEL_POWER`, and a pixel line that needs a second pin
driven high before it works is a failure mode with no symptom. The chain
goes on a plain GPIO.

The firmware is still rewritten -- the point is that the *platform* is
not.

## Firmware

The two halves become one. `adafruit_neokey` goes, the seesaw goes, the
I2C bus goes, and with them `GPIO_BASE` / `SEESAW_BASE`, the per-pad
`get_keys()` guards, and the whole `ERR i2c ...` family.

What replaces it is the GPIO source that already exists, widened from
two keys to six, and one `neopixel.NeoPixel` of length six.

**What this costs, stated plainly.** Three error paths proven by fault
injection stop existing, because the faults they catch stop being
possible. `ERR i2c setup`, `ERR i2c lost at runtime` and the
cable-unplugged row of the known-good table all describe hardware that is
not on this board. That is a smaller device, not a better-tested one --
the new paths get the same treatment, by injection, before they are
believed.

What survives unchanged: the protocol and every verb, the status colours,
crossfade, pulse, phase handling, debounce, the fatal handler and its
60 s brake, `boot.py`'s drive gate (now reading six GPIO and no I2C at
all), and the dual `usb_cdc` split with tracebacks on the console port.

`NUM_KEYS` stays a constant 6. `HELLO 3 6` stays. The host cannot tell.

Known-good answers shrink to:

| State | The device says |
|---|---|
| healthy | `HELLO 3 6`, `PONG 3 6` |
| `neopixel` missing | `HELLO 3 6` + `ERR gpio pixels ...`, keys dark, presses still reported |
| died past 60 s uptime | `ERR fatal ...`, all keys red, port drops, fresh `HELLO` |
| died inside 60 s | `ERR fatal-halted ...` on every later connect, stays red |

## Case

`MPAD_LAYOUT` has done its job. It selected where the QT Py sits, and
there is no QT Py -- so `stacked` and `inline` both retire, and with them
the QT Py pocket, its rails, its lip, its STEMMA notch, the wire lane and
the cable bay.

The new axis is **`MPAD_SWITCH=mx|choc`**, and GTMX is `mx` -- the case
cannot see the difference, because every number it reads is identical
and the 3 mm GTMX saves is above the plate where the case ends.

Derived from the switch:

**`MPAD_SWITCH` never gets built.** With one switch there is no axis --
the case is Choc v2 and nothing else, and every number below is a
constant rather than a branch:

| | value |
|---|---|
| `SWITCH_HOLE` | 14.10 |
| `PLATE_TOP_TO_PCB` | 2.20 |
| `PLATE_T` | 1.30 |
| `SOCKET_DROP` | 1.90 |
| `CASE_H` | **9.50** |

Both hole figures are nominal plus this machine's 0.15 shrink, the
constant `SWITCH_HOLE` has always measured. 14.15 is settled on a
printed part; 14.10 is that arithmetic applied to a cutout read off
Kailh's own drawing, and the coupon's job is now to find out whether
the two are the same hole.

```
2.40 floor + (1.90 socket + 1.40 air) + 1.60 board + 2.20  =  9.50
```

That is **3.83 below the wired pad's 13.33**, and it is the whole reason
this variant was worth the switches it costs.

It is still not *built*, and one claim in it now has to be settled
before anything is printed rather than after: **1.30 of printed plate
holding a Choc's clips.** With MX gone there is no fallback thickness,
so the coupon moves from optional to blocking.

`CASE_H` is derived, not chosen, and it is worth writing the sum out so
it can be argued with:

```
mx     2.40 floor + (1.85 socket + 1.40 air) + 1.60 board + 5.00  = 12.25
choc   2.40 floor + (1.90 socket + 1.40 air) + 1.60 board + 2.20  =  9.50
today  2.40 floor + (2.96 receptacle + 1.40 air) + 1.57 + 5.00    = 13.33
```

The middle term is the whole story. Today's 2.96 is the STEMMA QT
receptacle hanging under the NeoKey -- a connector this board does not
have -- and deleting it is where every millimetre of the `mx` saving
comes from. The plate gap above the board is a switch standard and
cannot be argued down, which is why `mx` saves 1.08 and `choc` saves
3.83.

Locating pegs go. A plate-mount switch clips into the top plate and its
pins go into the socket, so the switch ties plate to board -- the same
thing the first assembled six-key unit found for the breakouts. What
holds the board is its outline and the screws.

`build.py` must end in `all checks passed` for **both** switch settings
before anything is printed, and the mock has to gain the new board and
lose three old ones. Every stand-in models the mated plug, not the
connector, because that mistake has happened four times here.

## The EDA tool: EasyEDA

Both candidates were driven by an agent and measured against the
question this repository always asks: can the result be read back and
asserted, rather than looked at. **Both passed it.** The decision
therefore turned on what neither of them proved about placement, and on
one observation about this repository's own habits.

### KiCad, measured

Proven on this machine, headless, no GUI opened. A script created a
board, placed two real `SW_Cherry_MX_1.00u_Plate` footprints, saved,
**re-read the file from disk** and measured the gap:

```
SW1 x = 9.525000   SW2 x = 28.575000
measured pitch = 19.050000   wanted 19.05
all checks passed
```

The check was **watched failing first** -- placed at 19.00 it reported
`FAIL: pitch is off by -0.050000000 mm` -- so the green means something.
`kicad-cli` then exported Gerbers from the same file. The board is
s-expression text: `(at 28.575 10.795)` is literally greppable, which
makes it diffable and reviewable the way `params.py` is.

Version here is KiCad **10.0.5**, `pcbnew` importable from the app's own
Python. One trap, recorded because it cost a wrong diagnosis: a write to
`/tmp` is killed by the sandbox with **SIGKILL and no traceback**, which
reads exactly like a crash inside `pcbnew`.
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

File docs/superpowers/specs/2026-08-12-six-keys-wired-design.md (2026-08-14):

# Six keys, wired

Take the pad from four keys to six over USB, without touching the
protocol and without asking anything new of the macOS half — Canopy
already reads the key count out of `HELLO`.

## Hardware

Keep the NeoKey 1x4 at `0x30` for keys 2-5. Add two Adafruit 4978
NeoKey Socket Breakouts for keys 0-1, read on GPIO. The QT Py RP2040
does not change.

The numbering is that way round because the case forced it, which this
document originally got wrong -- see Butting them on below.

The alternatives, and why not:

- **A second NeoKey 1x4** gives eight keys, not six, and is 152.4 wide.
- **NeoKey Snap-Apart 5x6 snapped to 1x6** is one uniform board with
  guaranteed LED consistency, but it carries no seesaw: I2C disappears,
  `boot.py`'s drive gate is rewritten, and every error path proven by
  fault injection has to be proven again. ¥5,088 against ¥858.
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

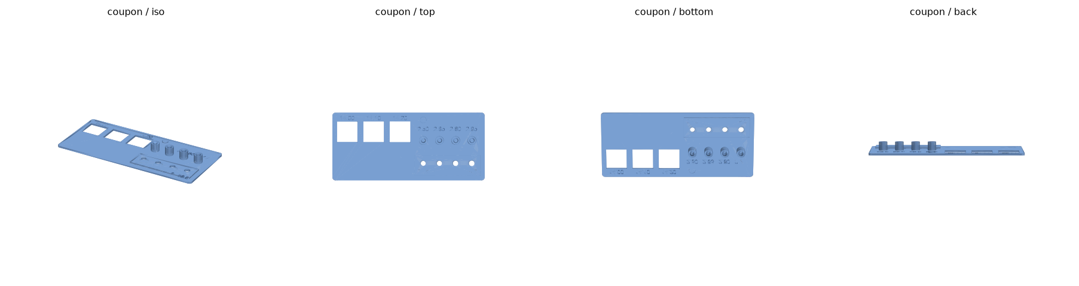
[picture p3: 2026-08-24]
case/out/choc/coupon.png

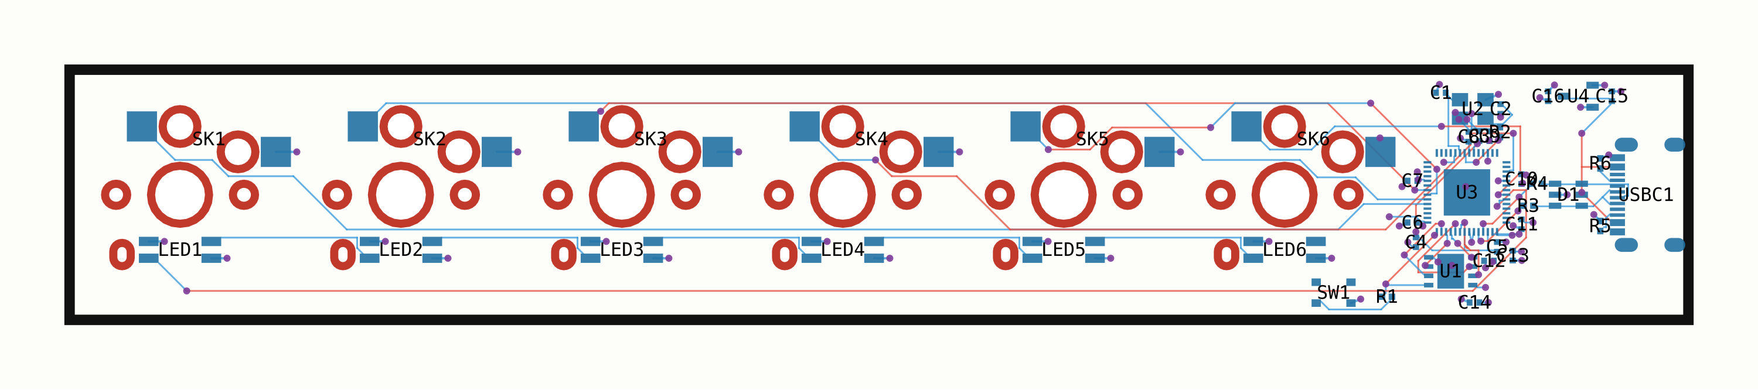
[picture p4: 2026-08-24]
pcb/out/board-final.png

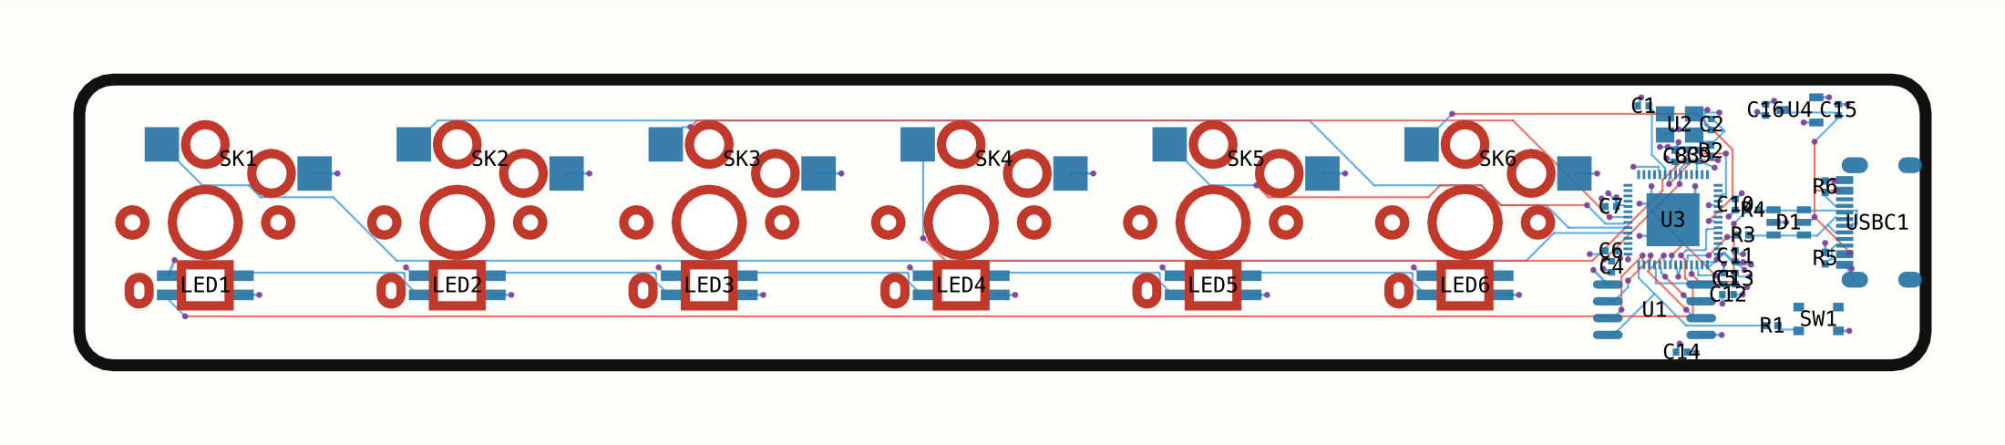
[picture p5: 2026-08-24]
pcb/out/board-final-c179171.png

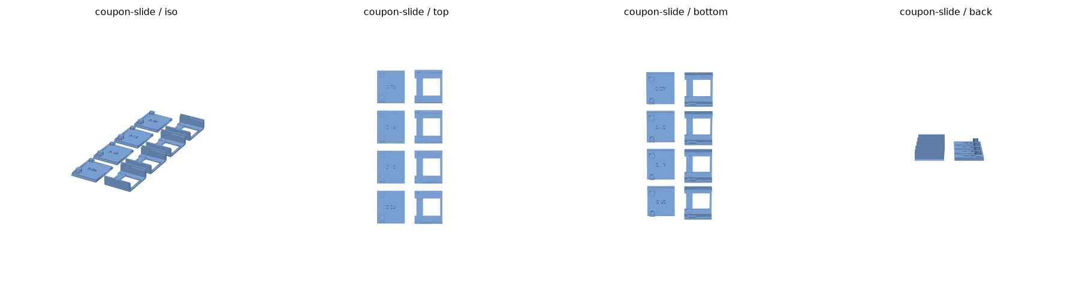
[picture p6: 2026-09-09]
case/out/choc/coupon-slide.png

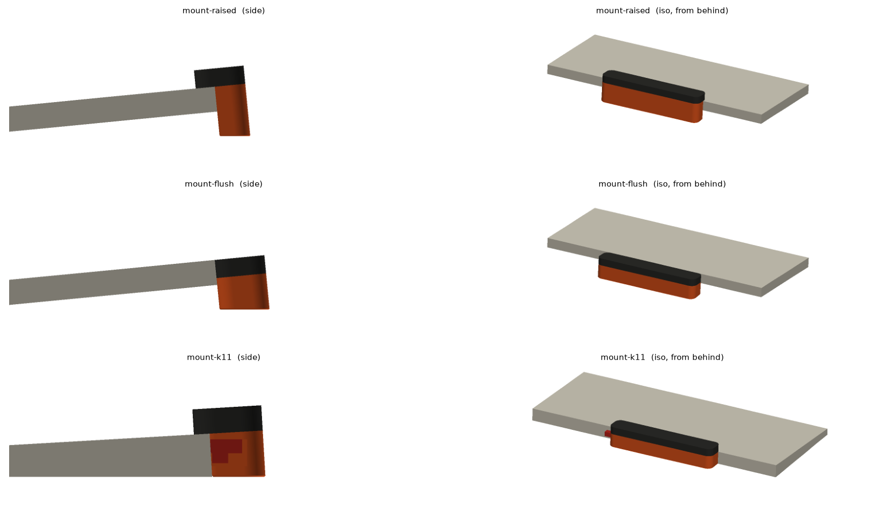
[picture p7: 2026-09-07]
case/out/choc/mount.png

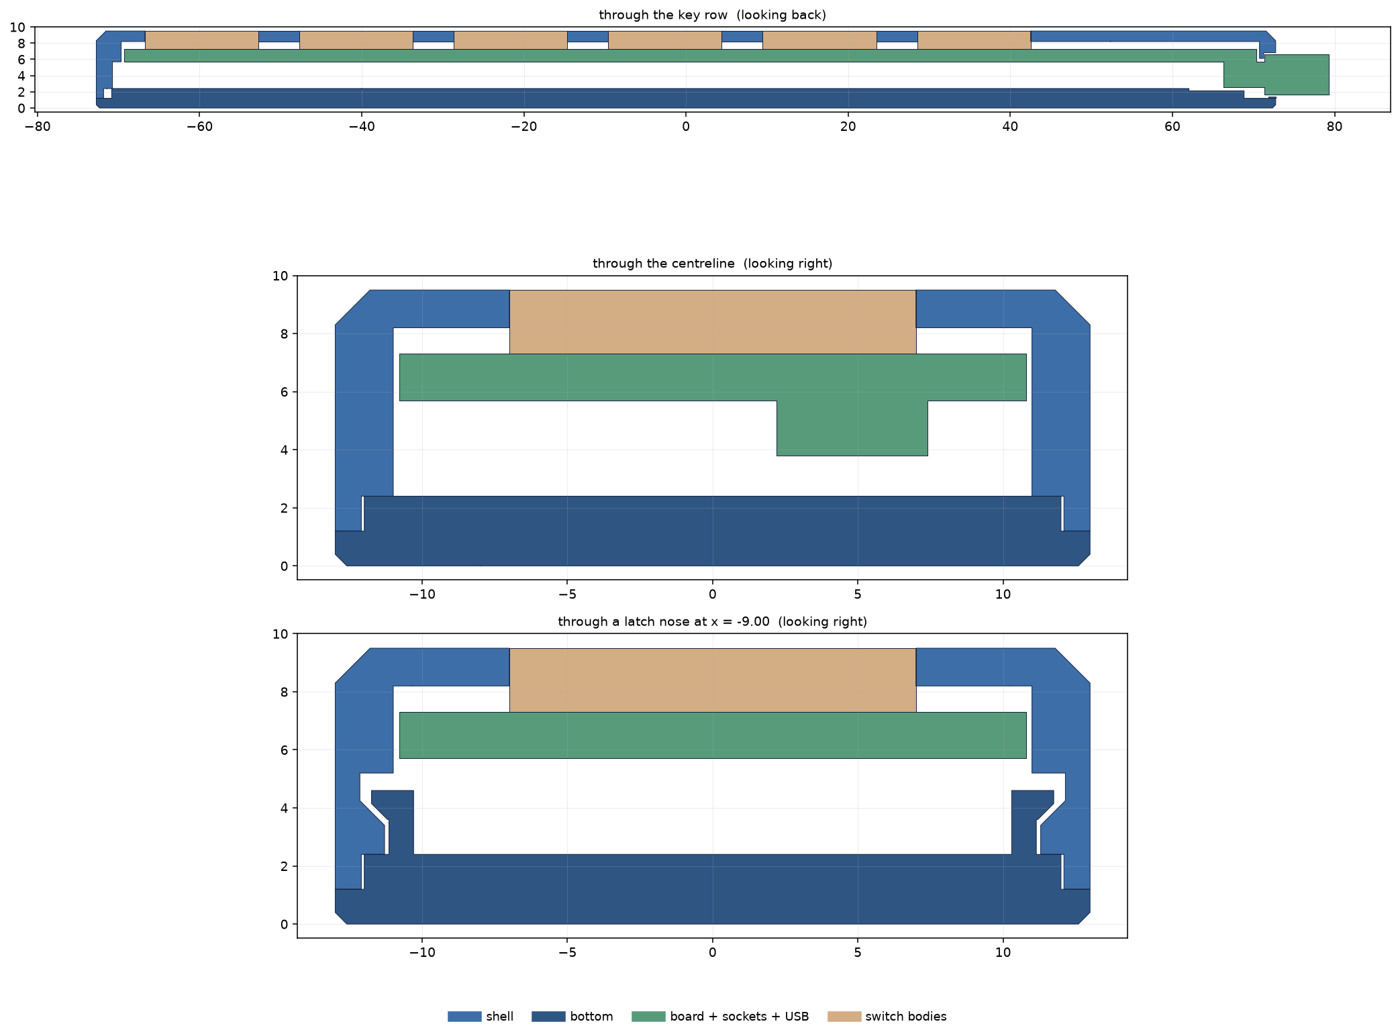
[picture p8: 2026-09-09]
case/out/choc/sections.png

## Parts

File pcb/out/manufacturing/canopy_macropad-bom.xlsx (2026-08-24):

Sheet: bom模板
 |  |  |  | Bill of Materials | canopy_macropadxlsx
 |  |  |  | Project Title： | Canopy MacroPad
 |  |  |  | Variant:
 |  |  |  | Report Time： | 2026年8月17日 17:50:17
No. | Quantity | Comment | Designator | Footprint | Value | Manufacturer Part | Manufacturer | Supplier Part | Supplier | LCSC Price | Total
 | 2 | 15pF | C1, C2 | C0402 | 15pF | 0402CG150J500NT | FH(风华) | 0402CG150J500NT.1 | LCSC
 | 10 | 100nF | C3, C4, C7, C8, C9, C10, C11, C12, C13, C14 | C0402 | 100nF | CL05B104KO5NNNC | SAMSUNG(三星) | CL05B104KO5NNNC.1 | LCSC
 | 2 | 1uF | C5, C6 | C0402 | 1uF | CL05A105KA5NQNC | SAMSUNG(三星) | CL05A105KA5NQNC.1 | LCSC
 | 2 | 1uF | C15, C16 | C0402 | 1uF | CL05A105KA5NQNC | SAMSUNG(三星) | C52923 | LCSC
 | 1 | USBLC6-2SC6 | D1 | SOT-23-6_L2.9-W1.6-P0.95-LS2.8-BL |  | USBLC6-2SC6 |  | C323793 | LCSC
 | 6 | SK6812MINI-E | LED1, LED2, LED3, LED4, LED5, LED6 | LED-SMD_4P-L3.2-W2.8-LS5.9_SK6812MINI-E |  | SK6812MINI-E | 欧思科光电 | SK6812MINI-E_C5149201.1 | LCSC
 | 2 | 1kΩ | R1, R2 | R0402 | 1kΩ | 0402WGF1001TCE | UNI-ROYAL(厚声) | C11702 | LCSC
 | 2 | 27Ω | R3, R4 | R0402 | 27Ω | 0402WGF270JTCE | UNI-ROYAL(厚声) | C25100 | LCSC
 | 2 | 5.1kΩ | R5, R6 | R0402 | 5.1kΩ | 0402WGF5101TCE | UNI-ROYAL(厚声) | C25905 | LCSC
 | 6 | CPG135001S30 | SK1, SK2, SK3, SK4, SK5, SK6 | CONN-SMD_HOTPLUGPAKAGE__C9900010116 |  | CPG135001S30 | Kailh(凯华) | CPG135001S30.1 | LCSC
 | 1 | TS263065A 340gf SX BD SMD Tactile Switch | SW1 | SW-SMD_4P-L3.0-W2.6-P1.80-LS3.4-TL |  | TS263065A 340gf SX BD SMD Tactile Switch | SHOU HAN(首韩) | TS263065A 340GF SX BD SMD TACTILE SWITCH.1 | LCSC
 | 1 | W25Q64JVSSIQ | U1 | SOIC-8_L5.3-W5.3-P1.27-LS8.0-BL |  | W25Q64JVSSIQ | Winbond(华邦) | C179171 | LCSC
 | 1 | ABM8-272-T3 | U2 | CRYSTAL-SMD_4P-L3.2-W2.5-BL-2 |  | ABM8-272-T3 |  | C9900091606 | LCSC
 | 1 | RP2040 | U3 | QFN-56_L7.0-W7.0-P0.40-TL-EP4.0 |  | RP2040 | Raspberry Pi(树莓派) | C2961140 | LCSC
 | 1 | XC6206P332MR-G | U4 | SOT-23-3_L2.9-W1.6-P1.90-LS2.8-BR |  | XC6206P332MR-G | TOREX(特瑞仕) | C5446 | LCSC
 | 1 | TYPE-C-31-M-12 | USBC1 | USB-C_SMD-TYPE-C-31-M-12_1 |  | TYPE-C-31-M-12 | 韩国韩荣 | C165948 | LCSC

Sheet: Field汇总
Project Title | Canopy MacroPad
Borard Title | <Parameter borard title not found>
Schematic Title | Schematic1
PCB Title | PCB1
Variant Name
Total Quantity | 41
Report Time | 17:50:17
Report Date | 2026年8月17日
Report Date&Time | 2026年8月17日 17:50:17
File Name | canopy_macropadxlsx
Filter Option | Add into BOM:no;

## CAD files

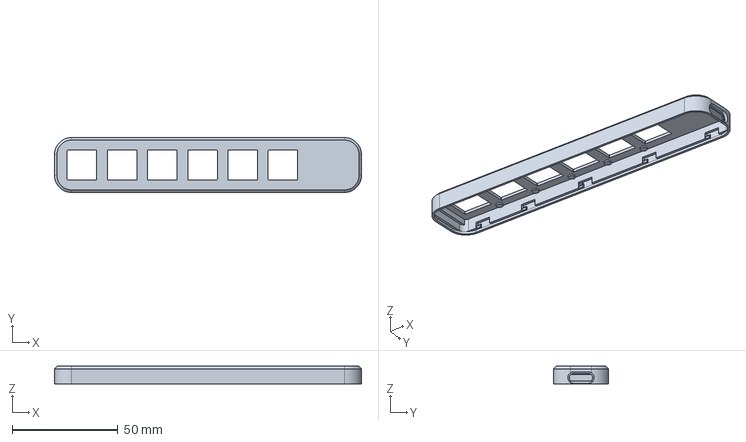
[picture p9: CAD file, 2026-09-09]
case/out/choc/shell.step
145.5 x 26.0 x 8.30 mm

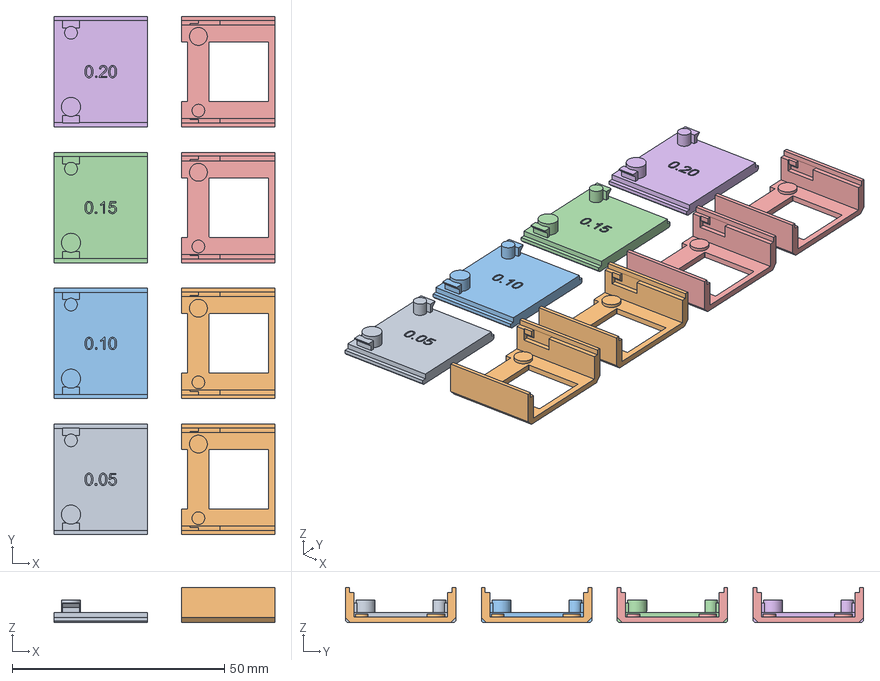
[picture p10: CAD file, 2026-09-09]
case/out/choc/coupon-slide.step
52.0 x 122.0 x 8.30 mm

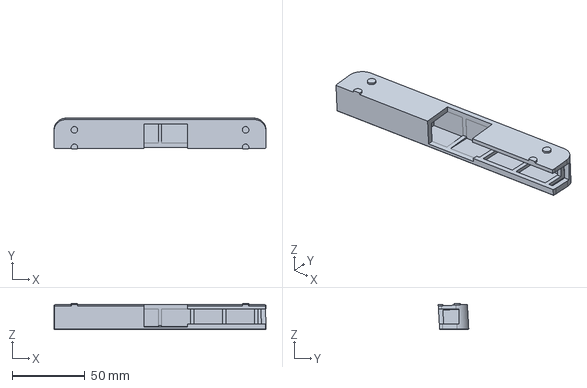
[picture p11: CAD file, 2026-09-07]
case/out/choc/mount-k11.step
145.5 x 21.0 x 18.1 mm

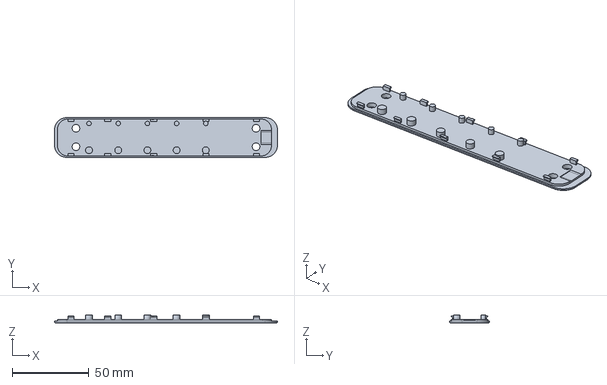
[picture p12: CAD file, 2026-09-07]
case/out/choc/bottom.step
145.5 x 26.0 x 5.30 mm

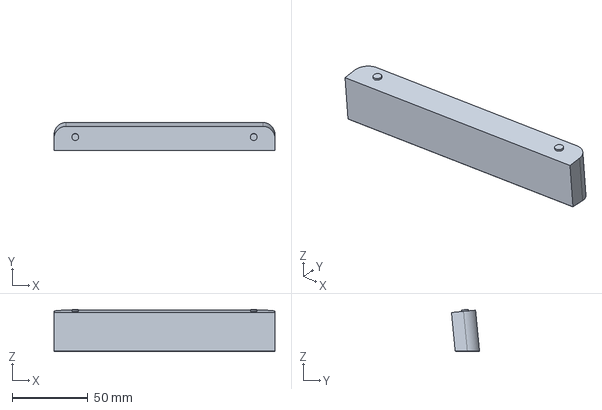
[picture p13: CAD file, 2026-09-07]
case/out/choc/mount-raised.step
145.5 x 18.5 x 27.9 mm

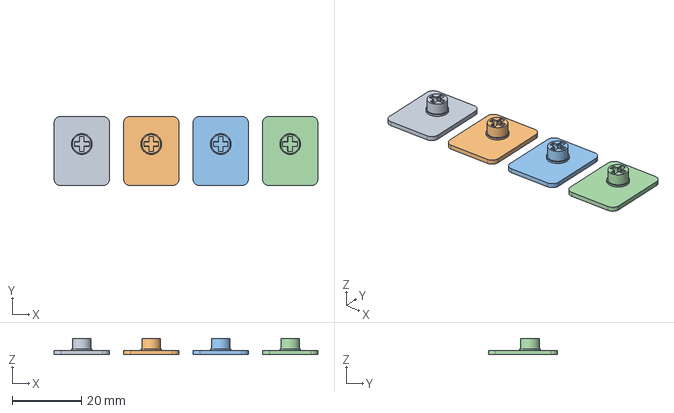
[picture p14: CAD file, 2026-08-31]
case/out/choc/coupon-stem.step
76.0 x 20.0 x 4.70 mm

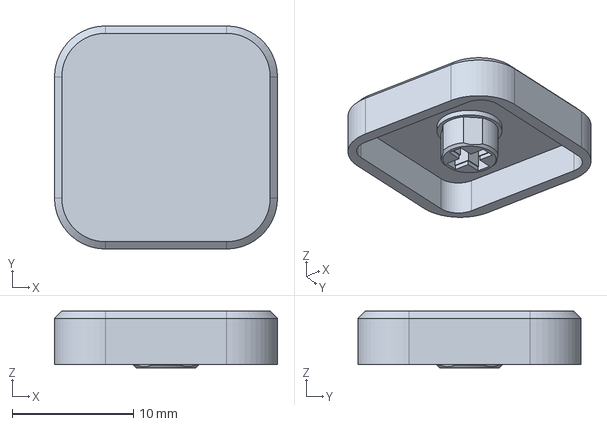
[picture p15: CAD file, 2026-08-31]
case/out/choc/keycap.step
18.4 x 18.4 x 4.70 mm

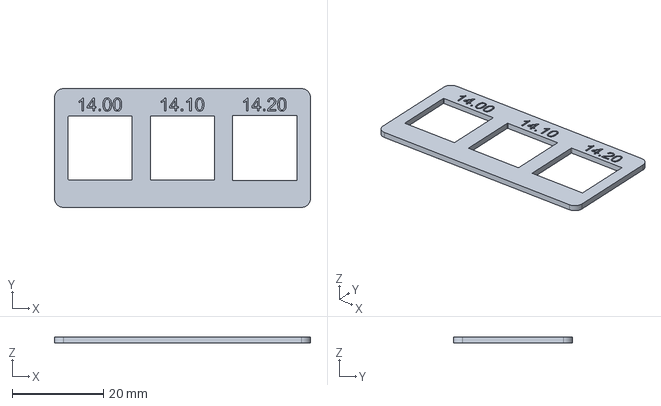
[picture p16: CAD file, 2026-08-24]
case/out/choc/coupon-hole.step
56.0 x 26.0 x 1.30 mm

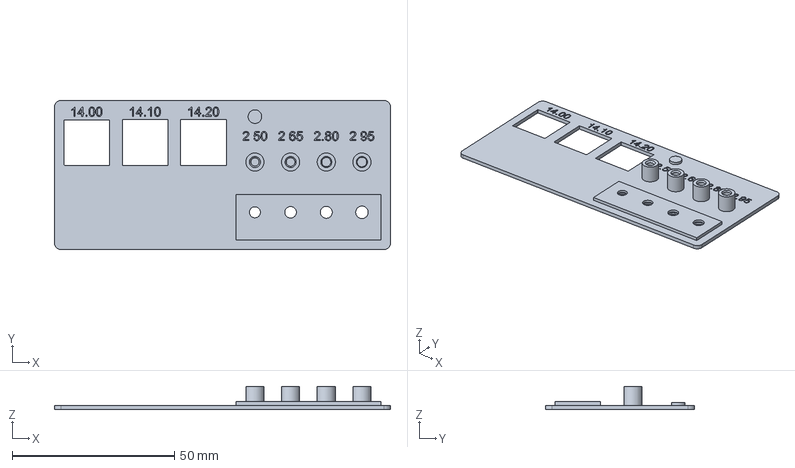
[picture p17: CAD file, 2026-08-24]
case/out/choc/coupon.step
103.6 x 46.0 x 7.10 mm

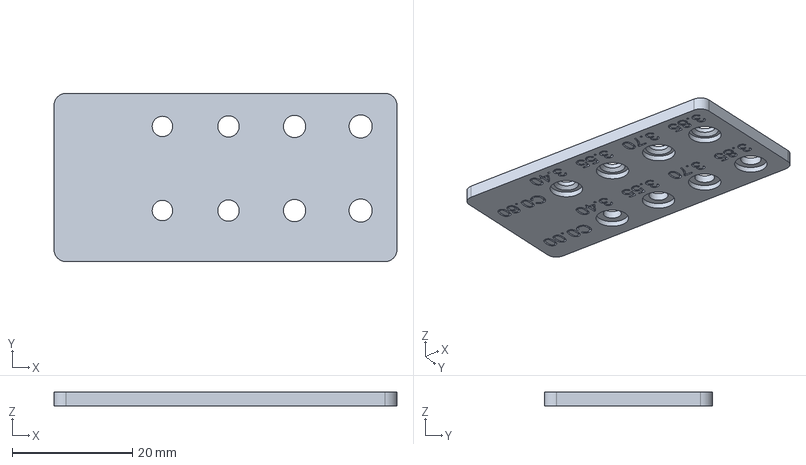
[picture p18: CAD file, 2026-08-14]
case/out/choc/coupon-clear.step
57.1 x 28.0 x 2.40 mm

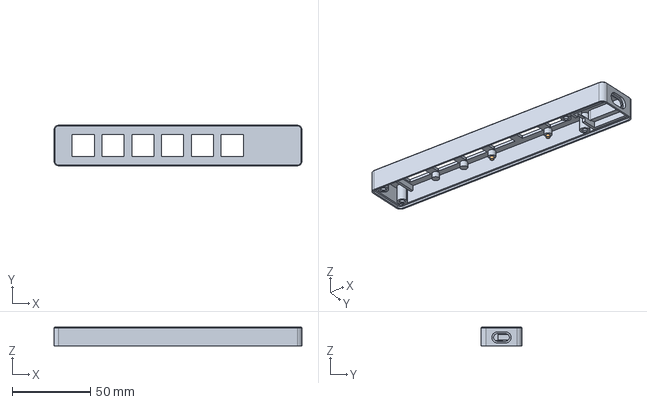
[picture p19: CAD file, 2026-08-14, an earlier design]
case/out/inline/shell.step
158.6 x 26.0 x 12.1 mm

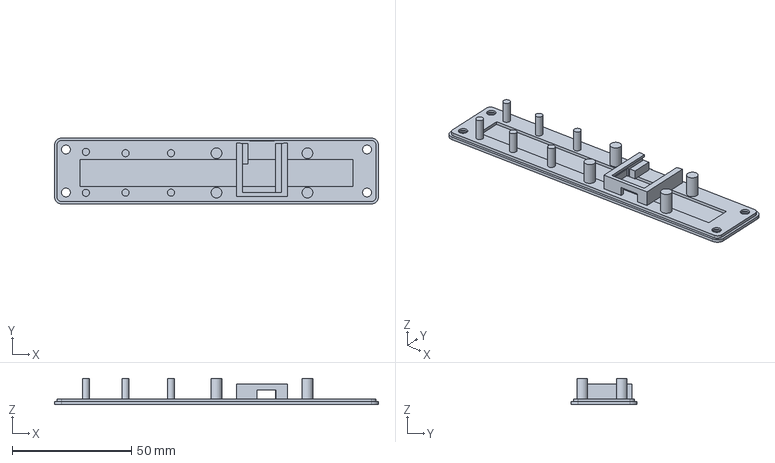
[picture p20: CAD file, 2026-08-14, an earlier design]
case/out/stacked/bottom.step
135.7 x 27.6 x 10.9 mm

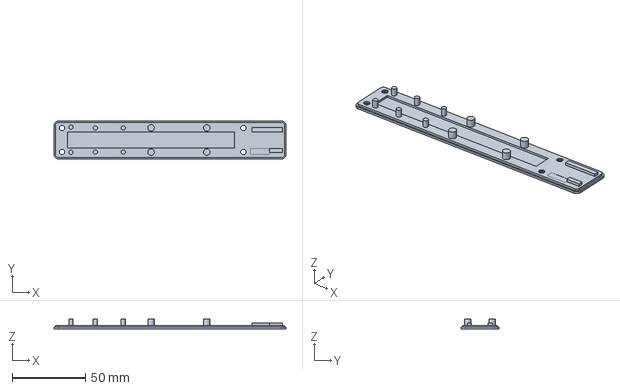
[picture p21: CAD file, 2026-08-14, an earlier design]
case/out/inline/bottom.step
158.6 x 26.0 x 6.76 mm

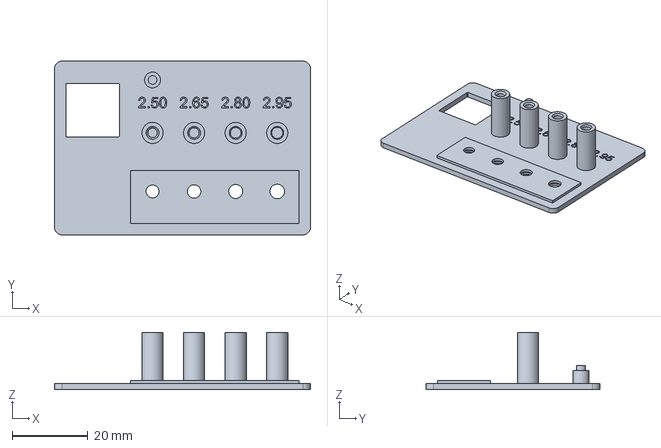
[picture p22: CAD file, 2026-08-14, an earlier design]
case/out/stacked/coupon.step
67.8 x 46.0 x 15.1 mm

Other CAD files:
pcb/out/3d/canopy_macropad_3d.obj
case/out/choc/mount-flush.step
case/out/inline/coupon.step
case/out/stacked/shell.step
case/out/choc/bottom.stl
case/out/choc/coupon-clear.stl
case/out/choc/coupon-hole.stl
case/out/choc/coupon-slide.stl
case/out/choc/coupon-stem.stl
case/out/choc/coupon.stl
case/out/choc/keycap.stl
case/out/choc/mount-flush.stl
case/out/choc/mount-k11.stl
case/out/choc/mount-raised.stl
case/out/choc/shell.stl
case/out/inline/bottom.stl
case/out/inline/coupon.stl
case/out/inline/shell.stl
case/out/stacked/bottom.stl
case/out/stacked/coupon.stl
case/out/stacked/shell.stl

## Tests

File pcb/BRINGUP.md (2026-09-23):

# pcb/ — bringing the fabricated board up

`README.md` next to this file is the design half: how to drive EasyEDA
from Python and every way that API has bitten. This file is the other
half — what to do when the boards arrive from JLCPCB, in what order, and
which of those steps prove less than they look like they prove.

`firmware/` runs on this board and on the QT Py build from one source;
the `pcb` profile in `firmware/code.py` is what this board gets. Two units
have been brought up by the order below.

## The document regressed once, silently, and the boards did not

Worth reading before reordering, because the mechanism is still there.

At one point the fabricated boards carried **88 vias** and the live
document had **97**. The nine extra were a 3x3 grid on 1.0 mm pitch at
x 119.5/120.5/121.5, y 10/11/12 — dead centre on U3, all GND. That is the
RP2040's **stock exposed-pad via array**, which `thermal_fanout.py` exists
to remove: this board uses no via-in-pad process, so the exposed pad is
fanned out to ordinary vias *outside* pad 57's paste area instead.
Reordering in that state would have needed filled-and-capped via
processing, or wicked solder off the thermal pad during reflow.

**Nothing was designed to change.** The array came back on its own, after
the Gerber was exported — the drill file is stamped 2026-08-17 17:50:17
and matches the 88 — so the first order escaped by ordering before the
regression rather than by anything catching it.

**Fixed by re-running `./all.sh`,** which is a full rebuild rather than a
repair, and the rebuild turned out to be near-deterministic: 87 of the
board's 88 vias came back at *identical* coordinates, none appeared that
the board lacks, and the single one that did not return —
(125.400, 3.500) — is proven unnecessary by `connect.py` still finding all
32 nets single connected islands without it. So the document now differs
from the boards by one absent via and nothing else. The guard is silent,
DRC reads `All (0)`.

Two commands settle the question at any time:

```
unzip -p out/manufacturing/canopy_macropad-gerber.zip \
  Drill_PTH_Through_Via.DRL | grep -c '^X'     # what was fabricated
python3 via_in_pad.py                          # what the document is now
```

**And the export cannot catch this.** `all.sh` runs `thermal_fanout.py`
and `via_in_pad.py`; `export_manufacturing.py` runs neither. Its checks
are about file completeness — both copper layers present, U1 in the BOM
and the CPL — so it will happily produce a Gerber from a document
`all.sh` would reject. DRC will not catch it either: a same-net via in a
same-net pad is electrically legal, and it is a manufacturing decision
rather than a rule violation. **Run `./all.sh` before an export, not
after**, and treat a clean `export_manufacturing.py` as saying nothing
about the design.

## What JLCPCB populates, and what it leaves for you

Economic PCBA on the bottom side assembles only what the quote in
`README.md` marks as required — U3 (RP2040), U1 (flash), U2 (crystal), U4
(LDO), USBC1, D1 and every passive. **SW1, LED1-6 and SK1-6 come DNP**,
which is what that section asked for. A board with no BOOT button is the
expected delivery, not a fab error.

Everything is on the **bottom** face. The Gerber archive carries
`Gerber_BottomPasteMaskLayer.GBP` and no top paste layer at all, which is
the quickest confirmation of that.

## The order to test in

Each step exists because it can be done before the next one, and because
a failure at that step is cheaper to find there. **The value of the list
is as much in what each step cannot see as in what it checks.**

1. **Visual, against the render.** `out/board-final.png` and
   `out/board-large.png` are **stale**: both predate SW1 moving beside
   USB-C (`layout.py`'s own comment says "it lives beside USB-C *now*"),
   so SW1 is simply not drawn in them. The Gerbers come from the live
   EasyEDA document and are correct; only the figures are old. Read
   `out/manufacturing/canopy_macropad-cpl.xlsx` for where a part actually
   is — it is generated from the same export.
2. **Shorts, before any power.** VBUS-GND and 3V3-GND. A short here and a
   plugged-in board is a damaged host port.
3. **Power, ideally metered.** 3.30 V out of U4.
4. **Plug in and look for `RPI-RP2`.** This proves U4 and the 3V3 rail,
   the RP2040 itself, the crystal (the bootrom's USB needs the 12 MHz
   XOSC), and the whole USB path — connector, D+/D-, the 27 R series
   pair, the 5.1 k CC pair, the USBLC6.

   **It does not prove the flash.** An RP2040 falls into BOOTSEL when its
   flash is blank, when it is dead, and when it is absent, and all three
   look exactly like a healthy first boot. On a fresh board the flash *is*
   blank, so this step is guaranteed to succeed and tells you nothing
   about U1.
5. **Write a UF2.** This is the flash test, and it is the first step that
   can fail for a reason the previous ones could not see. `CIRCUITPY`
   appearing means the flash was erased, written and read back.
6. **KEY traces, with nothing soldered.** Pull each KEY GPIO up and
   bridge a hot-swap socket's two pads with tweezers — pad 1 is `KEYn`
   and pad 2 is GND (`place_mcu.py`'s net map), so a bridge is
   electrically what the switch does and needs no separate ground lead.
   Six traces, RP2040 ball to socket pad, before committing any solder.
7. **LED1 only.** It is the head of the chain (`GPIO25 -> LED1.DIN`);
   every later pixel is fed by the one before it, so no other LED can be
   tested alone.

   **Orientation: the lead with the notch is GND**, and the bottom silk
   has no outline, only a small dot beside **pad 1, VDD** -- the notch
   goes on the corner diagonally opposite that dot. Lens into the opening,
   all six the same way round (CPL: layer B, rotation 180). Held bottom
   up with USB-C on the left and the sockets at the far edge, GND is far
   right, DIN near right, DOUT far left, VDD near left. `PIXEL_PAD_SIGNALS`
   and `PIXEL_SIGNAL_QUADRANT` in `params.py` are the source.
8. **The rest, then the chase.** See "a chain diagnoses itself" below.
   One look settles the whole chain before any chase: `C 0..5` with six
   different colours (red, green, blue, white, yellow, cyan), held static.
   Then press every key a few rounds and **count downs and ups per key**.
   A key that never appears is one number in that table, while in a
   scrolling log a key that is simply missing is easy to overlook.

## Three ways into the UF2 bootloader

All three watched working on the built board. Worth knowing all of them,
because the first one does not exist until SW1 is soldered and the third
does not exist until the board runs CircuitPython.

- **Hold SW1 through a plug-in.** The normal way, once SW1 is on.
- **Bridge SW1's bare footprint.** The pads are live with no part on
  them: pad A goes through R1 (1 k) to `QSPI_SS`, pad B to GND. Bridge
  **across the 3.4 mm lead span**, not the 1.8 mm pitch — the two pads
  sharing a column are the same net and shorting them does nothing. Hold
  the bridge *while* plugging in; the RP2040 only samples `QSPI_SS` at
  power-on.
- **From the CircuitPython REPL.**
  ```python
  import microcontroller
  microcontroller.on_next_reset(microcontroller.RunMode.BOOTLOADER)
  microcontroller.reset()
  ```

There is no reset button on this board, so before flashing anything onto
a bare board it is worth knowing which of these is available. **A fresh
board needs none of them**: with a blank flash the bootrom goes to
BOOTSEL by itself, and the second unit showed `RPI-RP2` on its first
plug-in with SW1 never fitted and nothing bridged.

Which of SW1's columns is which, held bottom up: the column **nearer
USB-C is GND**, the far one is `BOOT` (pad 1, at x 130.0 against 133.0 in
the Gerber). The bridge does not care, as long as it crosses columns.

## Measured on the board

Numbers from the first assembled unit, usable as a baseline for the next
one.

| Fact | Value |
|---|---|
| Board UID | `DF6590575F5D2026`, unit 2 `DF6590575F7A2426` |
| Firmware | CircuitPython 10.2.1, stock `raspberry_pi_pico` build; `neopixel.mpy` from the 10.x bundle (unit 2: bundle 20260923) |
| CPU | 125 MHz — the PLL locked to the 12 MHz XOSC, so CircuitPython running at all proves U2 |
| `CIRCUITPY` free | 7,308,288 bytes |
| Die temperature, idle | ~31.8 °C |
| KEY0-5 | GPIO 3, 4, 6, 20, 5, 24 — measured in order, no swaps, no shorts |
| PIXEL | GPIO25 |
| Debounce that holds | 3 samples at 5 ms; every press of a real Choc measured 142 ms or longer |
| Flash write, host over USB MSC | 53 kB/s — 7,086,080 bytes took 131 s |
| Flash read, device side | 1231 kB/s — the same bytes back in 5.8 s |

That 23x asymmetry is the number to remember when a deploy feels slow:
it is the flash's erase-and-program cost plus the mass-storage layer, not
a fault. Copying `code.py` is ~50 kB and lands inside a second; copying
something megabyte-sized will take minutes.

**7 MB means the flash *reported* 8 MB.** CircuitPython reads the JEDEC
capacity at runtime, which is why a build compiled for a 2 MB Pico
exposes 7 MB here. On its own that confirms U1 is the W25Q64 and that
QSPI works — it is not a surface test, because formatting writes
structures, not every block.

**The surface test was run separately and passed**: 7,086,080 bytes
(1730 x 4096, 98% of the free space) written from the host over USB mass
storage, then read back **by the RP2040 out of its own flash** and
compared block by block. Both halves of that arrangement matter. Reading
it back on the host would let macOS's page cache answer instead of the
flash, so the two directions deliberately take different paths. And each
block carries its own index in its first four bytes, because a fault that
returns the *wrong* block rather than corrupt bytes would pass a
body-only comparison — under a uniform pattern, address aliasing reads as
success. The body pattern is `bytes(range(256))` repeated, not zeros, so
a stuck-at value cannot hide in it either.

What that does and does not settle: the FAT-visible ~7 MB reads back what
was written, once. It says nothing about the ~1 MB the firmware occupies,
and nothing about retention or wear.

**SK6812MINI-E runs on the 3V3 rail**, which is below its 3.7 V datasheet
minimum. Red, green and blue all came up at full strength — and blue is
the one that would have died first, having the highest forward voltage, so
its survival is the meaningful half of that result. The rail was chosen on
the other side of the trade: at 3V3 the RP2040's 3.3 V output clears the
part's `0.7 * VDD` = 2.31 V input threshold with room, where a 5 V rail
would have put 3.3 V against 3.5 V.

**And that rail carries everything, which the QT Py's does not.** On the
QT Py the pixels hang off the incoming Qwiic rail, unregulated; here every
pixel's VDD and the RP2040 both sit behind U4, one XC6206 in SOT-23-3. So
the pixels' worst case is the regulator's worst case, and it was worth
asking about.

**It holds.** Six pixels at `ffffff` through a 10/25/50/75/100 brightness
ramp caused no reset at any step — and a reset is the signal that cannot
be missed, because the firmware announces a fresh `HELLO` on the same port
the test is listening to. Then an A/B with **load as the only variable**:
LED0 told `ffffff` at brightness 100 with only itself lit, against LED0
told the same thing with all six lit. No colour difference. That is the
sensitive form of the question — blue and green have the higher forward
voltage and starve first, so a sagging rail shows up as one white going
warm, which is the same reading that found LED4's dry supply pad. Staring
at a single 100% white and asking "is that reddish?" cannot answer it;
there is nothing to compare against and the eye adapts.

Not measured, and deliberately: **sustained** full white. 1.7 V times the
board's draw is not much thermal room in that package, and no host holds
that state — so the case that would need a heat measurement is one the
device never enters. That is a scope decision, not a gap.

**`neopixel_write` is a core module** on the RP2040 port, so the pixels
need nothing in `lib/`. Its argument is the whole chain's buffer, three
bytes per pixel, **GRB on the wire**.

## A chain diagnoses itself

LED4 came out a visibly different colour from the other five, and it was
fixed by reflowing without desoldering anything, on this reasoning:

**Data passed through LED4 and reached LED5, and LED5 was correct.** That
alone proves LED4's DIN, its internal IC and its DOUT are all healthy —
the digital path is not a suspect, by evidence rather than by probing.
What remains is VDD and GND. A half-wetted supply joint adds resistance,
and blue and green starve first, so the symptom of a bad supply pad on a
chained pixel is *one pixel gone warm*. Reflowing its supply pads fixed
it; the part was innocent.

This only works because the part sits in a chain. An isolated LED offers
no such evidence and has to be metered.

**The hand-soldered joints are where the faults have been.** Both faults
found so far were on DNP parts soldered by hand, not on anything JLCPCB
assembled -- unit 1's LED4 above, and unit 2's hot-swap socket SK2: key 1
never reported, not once across many rounds, while the other five were
clean -- and reflowing the socket's two SMD pads fixed it. So a single
key that is **completely** silent points at its socket's solder before
the switch or the RP2040. The tweezer bridge from step 6 separates the
two in one press, and swapping the switch into another socket settles
the switch.

Which is also what the **chase** phase of a pad test is for: light one
pixel at a time, 0 through 5. It is the only test that *locates* a broken
hop — everything downstream of a dead link stays dark, so the index where
the walk stops names the break (stops after N ⇒ `N.DOUT -> (N+1).DIN`).
In every other pattern, a downstream failure just looks like "some LEDs
are off".

## Two things a host-side log cannot tell you

Both of these produced a confident-looking pass on this board before
someone noticed what they were actually reporting.

- **A console log proves the firmware sent the data, not that a pixel
  lit.** A chase printing `chase 0` through `chase 5` prints exactly the
  same lines on a board with no LEDs on it at all. Only the person
  looking at the board can answer that one, so ask them what they saw
  rather than reporting the log as a result.
- **A reader that stops on a press leaves the release queued.** A
  script that exits the moment it sees `K 1 1` never reads the `K 1 0`
  that follows, and the next run sees that release first -- one up more
  than downs, which looks like a bounce. Unit 2's final count read 6
  downs and 7 ups on key 1 right after such a run, and that is the
  likeliest reading -- a bounce would add a down as well, because the
  firmware reports edges only -- though the first event's timestamp was
  not kept, so it is inferred rather than shown.
- **Change-only logging cannot see a stuck input.** A KEY net shorted to
  GND on the board reads low from the very first sample and never
  produces an edge, so it is invisible in a log of transitions. Print the
  **initial** state, and repeat it in a heartbeat — all six reading high
  is itself a fab-defect check, and it costs nothing.

## Driving the board from the host

Once `firmware/boot.py` is on the board and it has had a **hard** reset,
`tools/mpad.py --probe` is the whole test:

```
usb: product='Canopy MacroPad' vid=9114 pid=33012 (0x239a / 0x80f4)
  /dev/cu.usbmodem2101  console/silent (no PONG (saw: nothing))
  /dev/cu.usbmodem2103  DATA   -> PONG 3 6
```

That PID is **not** the one the root `README.md` records, and neither
reading is wrong: `boot.py` sets only the manufacturer and product
strings, so the VID and PID come from the CircuitPython build. The QT Py
build answers `0x80F8`, the stock Pico build this board runs answers
`0x80F4`. Match on `Canopy MacroPad`, never on the PID — which is what
both halves already do. `tools/mpad.py` never looks at it, and Canopy's
`MacroPadDevice.swift` leaves it out of the match on purpose, because
pinning a number that belongs to the build would fail closed and look
like a bad cable. So this board needs nothing on the host side.

Before `boot.py` is on the board there is one console port only, and
`code.py` falls back to it — `HELLO`, `PONG` and `K` lines arrive mixed in
with `print` output, which is enough to test the whole protocol. Two
things about reading it, the second of which is the fix for the first:

- **`code.py`'s startup prints are emitted before a host can reattach**
  after a reset, so they are dropped. Watching the console for a
  boot-time line is not a test.
- **Attach first, then force a reload.** `\x03` stops `code.py` and
  prints *"Press any key to enter the REPL"* — and that next key is
  consumed opening the prompt, so send it alone and wait to actually see
  `>>>`. Then `\x04` re-runs `code.py` with the host already listening,
  and the startup lines arrive.

Copying `code.py` to `/Volumes/CIRCUITPY/` triggers auto-reload, which is
a **soft** reset — enough for `code.py`, never enough for `boot.py`. And
`rm` the `._*` AppleDouble files macOS leaves behind.

## Where this stands

Nothing on the electrical side is open any more. What is left is one
requirement and one piece of paperwork.

- **`lib/neopixel.mpy` has to be on the board.** `adafruit_pixelbuf` is a
  core module on this build, so that one file is the whole dependency;
  `adafruit_neokey` is not needed, because the `pcb` profile never touches
  I2C. Without it the keys still report presses and the host is told `ERR
  gpio pixels ImportError`.

`firmware/` now runs on both boards from one source, selected by the
`PROFILES` table at the top of `firmware/code.py` (and a deliberately
smaller copy of it in `firmware/boot.py`, which cannot import `code.py`).
That table and the comment above it are the explanation, and `AGENTS.md`'s
"Editing the firmware" section describes both boards.

Verified on both units: `HELLO 3 6`, `PONG 3 6` on the data port, all six
keys reporting edges through the protocol, all six pixels lit in their
assigned colours, and no `ERR` of any kind. Both branches of `boot.py`'s
drive gate were checked on the first unit.

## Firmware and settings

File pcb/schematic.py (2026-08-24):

# pcb/schematic.py
"""Place and wire the RP2040 microcontroller block on the schematic.

Run with: python3 pcb/schematic.py

Schematic-only, on purpose (see the task brief) -- this does not touch the
PCB or route anything; `build.py` and `footprint.py` own that half.
Coordinates here are 0.01 inch, per pcb/README.md's own warning: mixing
them with the PCB's 1-mil coordinates misplaces everything by 10x, so this
file never imports `params.mm_to_mil()` and never shares a coordinate with
build.py/footprint.py.

Every device placed here is placed by uuid (params.DEV_*), found with
lib_Device.search() / getByLcscIds() and confirmed live -- see the task
report for the search trail. Every pin used below was read back from the
placed component with getAllPinsByPrimitiveId() and matched by name, not
assumed from a datasheet -- the one exception is the USBLC6-2SC6 (U4),
whose placed pins come back as bare "1".."6" with no name at all (unlike
every other device here), so its pin function *does* have to come from the
datasheet (ST's own USBLC6-2SC6 datasheet, pinout table: 1=I/O1, 2=GND,
3=I/O2, 4=I/O2, 5=VBUS, 6=I/O1) -- named in PINOUT_USBLC6 below rather than
trusted blind.
"""
import json
import os
import sys
import time

import params
from bridge import execute

PROJECT_NAME = os.environ.get("MPAD_EDA_PROJECT", "Canopy MacroPad")
LIB = params.LIB_UUID
SCHEMATIC_PAGE = 1  # EDMT_EditorDocumentType.SCHEMATIC_PAGE; the enum object
                     # is absent from the bridge execution context, same
                     # reasoning as build.py's TOP/BOTTOM.

# USBLC6-2SC6 pin function by number, read off ST's own datasheet (the part
# LCSC C323793 carries) -- not from the placed symbol, which returns pins
# named only "1".."6" (confirmed live: no descriptive pinName at all, unlike
# every other device this file places). This is exactly the situation
# pcb/README.md's "pin identity must come from datasheets" describes.
PINOUT_USBLC6 = {"1": "IO1", "2": "GND", "3": "IO2", "4": "IO2", "5": "VBUS", "6": "IO1"}


def open_project_schematic():
    """Open the project's schematic page and leave it active.

    Mirrors build.py's open_project_pcb(): the project is opened by name
    and never created (dmt_Project.createProject() is beta and returns
    undefined -- see build.py's own comment), and the active document is
    asserted rather than assumed, the way build.py asserts documentType==3
    for the PCB.
    """
    js = (
        "const teams = await eda.dmt_Team.getAllTeamsInfo(); "
        "for (const t of teams || []) { "
        "const us = await eda.dmt_Project.getAllProjectsUuid(t.uuid); "
        "for (const u of us || []) { "
        "const i = await eda.dmt_Project.getProjectInfo(u); "
        "const n = (i && (i.friendlyName || i.name)) || ''; "
        f"if (n === {PROJECT_NAME!r}) {{ "
        "await eda.dmt_Project.openProject(u); "
        "const pages = await eda.dmt_Schematic.getAllSchematicPagesInfo(); "
        "if (!pages || !pages.length) return {error: 'project has no schematic page'}; "
        "await eda.dmt_EditorControl.openDocument(pages[0].uuid); "
        "const doc = await eda.dmt_SelectControl.getCurrentDocumentInfo(); "
        "return {opened: n, page: pages[0].name, documentType: doc.documentType}; "
        "} } } "
        "return {error: 'project not found'};"
    ).replace("'", '"')
    got = execute(js)
    if got.get("error"):
        raise SystemExit(f"cannot open the schematic: {got['error']}")
    if got["documentType"] != SCHEMATIC_PAGE:
        raise SystemExit(f"active document is type {got['documentType']}, not a schematic page")
    print(f"opened {got['opened']} / {got['page']}")


def clear_schematic():
    """Delete every component (except the sheet symbol) and every wire.

    The sheet/title-block symbol is type 'sheet' and is not ours to touch --
    it pre-existed on this page. Mirrors probe.clear_components()'s
    "clear, then assert nothing is left" shape.
    """
    js = (
        "const all = await eda.sch_PrimitiveComponent.getAll(); "
        "const nonSheet = (all || []).filter(c => c.getState_ComponentType() !== 'sheet'); "
        "if (nonSheet.length) { await eda.sch_PrimitiveComponent.delete(nonSheet.map(c => c.primitiveId)); } "
        "const allw = await eda.sch_PrimitiveWire.getAll(); "
        "if (allw && allw.length) { await eda.sch_PrimitiveWire.delete(allw.map(w => w.primitiveId)); } "
        "const leftC = (await eda.sch_PrimitiveComponent.getAll()).filter(c => c.getState_ComponentType() !== 'sheet').length; "
        "const leftW = (await eda.sch_PrimitiveWire.getAll()).length; "
        "return {leftC, leftW};"
    )
    left = execute(js)
    if left["leftC"] or left["leftW"]:
        raise AssertionError(f"clear left {left['leftC']} components and {left['leftW']} wires behind")


# --- placement ---------------------------------------------------------------
# key -> (device uuid, x, y). Rotation is 0 throughout -- schematic-only, no
# routing constraint forces a rotation the way the PCB side's socket/pixel
# mirroring did.
PARTS = {
    "U1": (params.DEV_RP2040, 600, 450),
    "U2": (params.DEV_FLASH, 200, 600),
    "U3": (params.DEV_LDO, 950, 750),
    "U4": (params.DEV_ESD, 900, 620),
    "J1": (params.DEV_USB_C, 1050, 600),
    "SW1": (params.DEV_BOOT_SW, 200, 700),
    "Y1": (params.DEV_CRYSTAL, 300, 430),
    "R1": (params.DEV_R_27R, 780, 610),   # USB_DP series
    "R2": (params.DEV_R_27R, 780, 650),   # USB_DM series
    "R3": (params.DEV_R_5K1, 1150, 625),  # CC1 pull-down
    "R4": (params.DEV_R_5K1, 1150, 565),  # CC2 pull-down
    "R5": (params.DEV_R_1K, 380, 420),    # crystal XOUT damping
    "R6": (params.DEV_R_1K, 330, 650),    # BOOT series resistor
    "C15": (params.DEV_C_15P, 150, 410),  # crystal load cap, XIN side
    "C16": (params.DEV_C_15P, 150, 470),  # crystal load cap, XOUT side
    "C11": (params.DEV_C_1U, 560, 780),   # VREG_IN
    "C12": (params.DEV_C_1U, 540, 780),   # VREG_VOUT / DVDD
    "C13": (params.DEV_C_1U, 850, 700),   # LDO input -- off U3's own y=750/770
    "C14": (params.DEV_C_1U, 1050, 700),  # LDO output rows on purpose, so a
    # straight wire from U3 to either cap doesn't run collinear through the
    # other's pins (see elbow()'s own collision check, added after exactly
    # this shape of accidental short was caught live).
}
# The ten 100 nF decoupling caps are positioned relative to the RP2040 power
# pins they serve, computed after U1 is placed and its pins read back --
# see place_decoupling() -- rather than hand-guessed here, because a
# hand-guessed x that drifts from the real pin x is exactly the kind of
# mistake this project's README warns about (footprint.py's whole existence
# is proof that a hole can be near the right spot and still not be there).
DECOUPLE_PINS = [
    ("C1", "IOVDD", "1"), ("C2", "IOVDD", "10"), ("C3", "IOVDD", "22"),
    ("C4", "IOVDD", "33"), ("C5", "IOVDD", "42"), ("C6", "IOVDD", "49"),
    ("C7", "DVDD", "23"), ("C8", "DVDD", "50"),
    ("C9", "USB_VDD", "48"), ("C10", "ADC_AVDD", "43"),
]


def place_all():
    """Place every part in PARTS, then the ten decoupling caps against U1's
    real, read-back power-pin coordinates. Returns {key: primitiveId}.
    """
    pids = {}
    for key, (uuid, x, y) in PARTS.items():
        js = (
            f'const dev = {{libraryUuid: "{LIB}", uuid: "{uuid}"}}; '
            f"const c = await eda.sch_PrimitiveComponent.create(dev, {x}, {y}, undefined, 0, false, true, true); "
            "return c ? c.primitiveId : null;"
        )
        pid = execute(js)
        if not pid:
            raise AssertionError(f"create returned nothing for {key}")
        pids[key] = pid

    u1_pins = get_pins(pids["U1"])
    # DVDD pins share x=310/320 at U1's placement; C12 (VREG_VOUT/DVDD cap)
    # was hand-placed near them above. The 10 decoupling caps go directly
    # below their own power pin, same x, +130 units in y -- far enough that
    # a 2-segment elbow wire between cap and pin doesn't cross another cap.
    for i, (key, pin_name, pin_num) in enumerate(DECOUPLE_PINS):
        px, py = pin_xy(u1_pins, pin_name, pin_num)
        cx, cy = px, py + 130
        js = (
            f'const dev = {{libraryUuid: "{LIB}", uuid: "{params.DEV_C_100N}"}}; '
            f"const c = await eda.sch_PrimitiveComponent.create(dev, {cx}, {cy}, undefined, 0, false, true, true); "
            "return c ? c.primitiveId : null;"
        )
        pid = execute(js)
        if not pid:
            raise AssertionError(f"create returned nothing for {key}")
        pids[key] = pid
    return pids


# --- pin lookup ---------------------------------------------------------------
_PIN_CACHE = {}


def get_pins(pid):
    if pid not in _PIN_CACHE:
        js = (
            f'const pins = await eda.sch_PrimitiveComponent.getAllPinsByPrimitiveId("{pid}"); '
            "return (pins || []).map(p => ({name: p.pinName, num: p.pinNumber, x: p.x, y: p.y}));"
        )
        pins = execute(js)
        if not pins:
            raise AssertionError(f"no pins read back for {pid}")
        _PIN_CACHE[pid] = pins
    return _PIN_CACHE[pid]


def pin_xy(pins, name=None, num=None):
    """Find exactly one pin by name and/or number; raise on 0 or >1 matches
    rather than silently taking the first -- the same "assert every
    substitution" discipline CLAUDE.md asks of string patches applies here
    to pin lookups: a name that matches zero or two pins is a wrong
    assumption, not a thing to paper over with [0].
    """
    matches = [
        p for p in pins
        if (name is None or p["name"] == name) and (num is None or p["num"] == num)
    ]
    if len(matches) != 1:
        raise AssertionError(
            f"pin lookup name={name!r} num={num!r}: {len(matches)} matches, wanted 1"
        )
    return matches[0]["x"], matches[0]["y"]


# --- wiring --------------------------------------------------------------------
_WIRE_LOG = []  # (net_label, [(x,y), ...]) for every wire created, for the report
_ALL_SEGMENTS = []  # every (a, b) segment already drawn, for crossing checks


def _segment_overlap(a1, a2, b1, b2):
    """The overlap between two axis-aligned segments, as an (x0, x1, y0,
    y1) box (a bounding-box intersection, exact for a pair of segments
    that are each already a degenerate zero-width or zero-height
    rectangle), or None if they do not touch at all.
    """
    ax0, ax1 = sorted((a1[0], a2[0]))
    ay0, ay1 = sorted((a1[1], a2[1]))
    bx0, bx1 = sorted((b1[0], b2[0]))
    by0, by1 = sorted((b1[1], b2[1]))
    if ax0 <= bx1 and bx0 <= ax1 and ay0 <= by1 and by0 <= ay1:
        return (max(ax0, bx0), min(ax1, bx1), max(ay0, by0), min(ay1, by1))
    return None


def _overlap_allowed(overlap, allowed):
    """True if an overlap box (from _segment_overlap()) is nothing more
    than one of this path's own declared points -- a legitimate T-junction
    or fan-out, not a crossing with an unrelated wire. A box that is a
    single point is allowed exactly when that point is in `allowed`; any
    wider overlap (two segments running along the same line for more than
    one point) is never allowed, regardless of what `allowed` contains.
    """
    x0, x1, y0, y1 = overlap
    if x0 != x1 or y0 != y1:
        return False
    return (x0, y0) in allowed


def wire_path(points, net=None, label=""):
    """Create one polyline wire through points (a list of (x,y) tuples,
    already Manhattan -- every consecutive pair must share x or y, per
    sch_PrimitiveWire.create()'s own documented rule that a horizontal
    segment followed by a diagonal one is rejected).
    """
    flat = []
    for x, y in points:
        flat.extend([x, y])
    line_js = "[" + ",".join(str(v) for v in flat) + "]"
    net_arg = f'"{net}"' if net else "undefined"
    js = (
        f"const w = await eda.sch_PrimitiveWire.create({line_js}, {net_arg}, undefined, undefined, undefined); "
        "return w ? w.primitiveId : null;"
    )
    wid = execute(js)
    if not wid:
        raise AssertionError(f"wire create returned nothing for {label or points}")
    _WIRE_LOG.append((label, points))
    for i in range(len(points) - 1):
        _ALL_SEGMENTS.append((points[i], points[i + 1], net))
    return wid


_ALL_PINS = set()  # every pin coordinate on the board, populated by place_all()


def _pin_on_segment(p, a, b):
    """True if p sits on the axis-aligned segment a-b (inclusive)."""
    if a[0] == b[0]:
        return p[0] == a[0] and min(a[1], b[1]) <= p[1] <= max(a[1], b[1])
    if a[1] == b[1]:
        return p[1] == a[1] and min(a[0], b[0]) <= p[0] <= max(a[0], b[0])
    return False


def _path_collides(path, allowed, net=None):
    """True if any pin (other than the path's own declared endpoints,
    `allowed`) lies on any segment of path, OR any segment of path
    crosses/touches an already-drawn wire segment of a *different* net
    anywhere other than a real shared endpoint -- three distinct shapes
    of the same underlying mistake, all watched happening live:

    - a bend landing exactly on an unrelated pin (R5-Y1's bend landed on
      the crystal's own GND pin);
    - a straight run passing over one (R1-USB_DP's bend landed on
      U1.USB_DM, a different signal three pins away in the symbol's own
      pin list);
    - and the one this function's earlier version still missed entirely:
      two *different* signals' own detour paths crossing each other at a
      waypoint that is not a registered pin at all, which EasyEDA still
      merges into one wire object and one net. Confirmed live, and not a
      near miss: QSPI_SCLK and QSPI_SD3 (and, separately, QSPI_SD1 and
      QSPI_SD2) ended up on the same wire object this way, and so did
      USB's D+ and D- at the connector -- three real shorts, caught only
      by directly probing `getState_Net()` on two supposedly-different
      pins and finding the same wire `primitiveId` came back for both.
      Checking against `_ALL_SEGMENTS` (every segment any wire_path()
      call has already drawn) is what the pin-only check could not do.

    `net`, if given, is the net this new path is itself going to carry --
    a crossing against an *already-drawn segment of that same net* is not
    a fault (VBUS's own star, wired point by point from one anchor,
    legitimately has several of its own segments passing near each other
    in the LDO/ESD/J1 cluster); only a crossing against a segment carrying
    a *different* (or no) net is.
    """
    for i in range(len(path) - 1):
        a, b = path[i], path[i + 1]
        for p in _ALL_PINS:
            if p in allowed:
                continue
            if _pin_on_segment(p, a, b):
                return True
        for wa, wb, seg_net in _ALL_SEGMENTS:
            if net and seg_net == net:
                continue
            overlap = _segment_overlap(a, b, wa, wb)
            if overlap is None:
                continue
            if _overlap_allowed(overlap, allowed):
                # The only point of contact is one of *this path's own*
                # declared endpoints -- legitimate fan-out (e.g. QSPI_SS
                # to both the flash and R6) or a deliberate T-junction
                # (a bus_connect() drop meeting its own rail) -- not a
                # crossing with an unrelated wire.
                continue
            return True
    return False


def elbow(a, b, net=None):
    """Two points -> a Manhattan path between them that does not pass
    through any other pin on the board.

    Tries, in order: the direct line (if a and b already share an axis),
    both single-bend elbows, then a widening search of double-bend
    detours (a -> sideways by a growing offset -> across -> in to b) on
    both the a-side and b-side. Raises rather than silently returning a
    wire that shorts two unrelated nets together -- see
    _path_collides()'s docstring for why that risk is real here, not
    theoretical -- but the two-signal-dense pin columns this board's QSPI
    bus and BOOT path both turn out to have needed the detour search
    before a hand-picked route was tried: single-bend routing failed for
    6 of the 8 QSPI/BOOT connections on the first attempt, every one of
    them because the bend, or the straight run itself, landed on a third,
    unrelated pin on the same crowded column -- not a one-off, a pattern.
    """
    ax, ay = a
    bx, by = b
    allowed = {a, b}
    candidates = []
    if ax == bx or ay == by:
        candidates.append([a, b])
    else:
        candidates.append([a, (bx, ay), b])
        candidates.append([a, (ax, by), b])
    for cand in candidates:
        if not _path_collides(cand, allowed, net=net):
            return cand
    for offset in (10, 20, 30, 40, 50, 60, 70, 80, 90, 100, 120, 150, 180, 210, 250, 300):
        for dy in (offset, -offset):
            cand = [a, (ax, ay + dy), (bx, ay + dy), b]
            if not _path_collides(cand, allowed, net=net):
                return cand
        for dx in (offset, -offset):
            cand = [a, (ax + dx, ay), (ax + dx, by), b]
            if not _path_collides(cand, allowed, net=net):
                return cand
    raise AssertionError(
        f"elbow({a}, {b}): no route up to a 100-unit detour clears every "
        "other pin -- needs a manually chosen path, not this function's "
        "search"
    )


def bus_connect(rail_y, points, net=None, label=""):
    """Wire every point in points to a single horizontal rail at rail_y,
    each with its own straight vertical drop, rather than star-wiring from
    one of the points as an anchor.

    Exists because DVDD's three real pins -- VREG_VOUT and both DVDD pads
    -- sit on U1's own bottom edge, all at the identical y, with other
    power pins between them on that same edge. A star from any one of them
    to another runs straight along that edge and through whatever pin
    happens to sit in between (confirmed live, via elbow()'s own collision
    check firing here first). A rail below the edge sidesteps the whole
    row: every drop is a single vertical segment at its own x, and the
    only shared line is the rail itself, which nothing else on the board
    occupies at rail_y by construction (the caller picks a y no other net
    uses).
    """
    xs = [p[0] for p in points]
    rail = [(min(xs), rail_y), (max(xs), rail_y)]
    rail_allowed = {rail[0], rail[1]}
    if _path_collides(rail, rail_allowed, net=net):
        raise AssertionError(f"{label}-rail at y={rail_y} collides with an existing pin")
    ids = [wire_path(rail, net=net, label=f"{label}-rail")]
    for i, (x, y) in enumerate(points):
        drop = [(x, rail_y), (x, y)]
        if _path_collides(drop, {(x, rail_y), (x, y)}, net=net):
            raise AssertionError(f"{label}-drop[{i}] at x={x} collides with an existing pin")
        ids.append(wire_path(drop, net=net, label=f"{label}-drop[{i}]"))
    return ids


def connect(anchor, points, net=None, label=""):
    """Star-wire anchor to every point in points, each as its own elbowed
    2-or-3-point path, every one of them carrying the explicit net name.

    An earlier version only named the first branch, on the assumption
    that later branches would inherit the name by coincidence once merged
    with it -- true for what EasyEDA reports (confirmed live: VBUS, DVDD,
    and USB_DP_RAW all read back their correct name this way), but it
    also meant every branch after the first was registered in
    `_ALL_SEGMENTS` with no net at all, so this file's own crossing check
    could not tell two branches of the *same* star apart from two
    branches of *different* nets crossing by accident -- exactly the bug
    that turned into the USB D+/D- short. Naming every branch explicitly
    fixes both: the check can now skip same-net crossings on purpose (see
    elbow()/_path_collides()), and there is no longer a silent gap in
    what the registry itself remembers.
    """
    ids = []
    for i, p in enumerate(points):
        ids.append(wire_path(elbow(anchor, p, net=net), net=net, label=f"{label}[{i}]"))
    return ids
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

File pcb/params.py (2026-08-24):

# pcb/params.py
"""The key field's numbers, and the only place they are written.

This file used to be case/params.py's job, derived from the NeoKey and the
4978 breakout. The boards are gone and the copper is ours now, so the PCB
owns the field and the case imports it. Changing the pitch here moves the
sockets, the pixels and the plate holes together, which is the whole point
of the inversion.

Stdlib only, deliberately: case/.venv must be able to import it without
installing anything, and so must a fresh machine.
"""

# --- units -----------------------------------------------------------------
# EasyEDA's PCB editor works in 1 mil. 1 mm = 1/0.0254 mil.
MIL_PER_MM = 1.0 / 0.0254


def mm_to_mil(v):
    """Millimetres to whole mils.

    Rounds, and every number this design uses is exact at 1 mil: 19.05 is
    0.75 inch (750), 9.525 is 375, 10.795 is 425.
    """
    return round(v * MIL_PER_MM)


# --- the key field ---------------------------------------------------------
# Pitch and depth are inherited from the NeoKey 1x4 the pad was built on, so
# every keycap and every printed plate hole that already works still does.
SWITCH_PITCH = 19.05
KEY_COUNT = 6
FIRST_SWITCH_X = 9.525          # half a pitch in from the field's left edge
SWITCH_Y = 10.795               # NeoKey 4980's switch centre, read off its .brd

KEY_FIELD_W = KEY_COUNT * SWITCH_PITCH      # 114.30
KEY_FIELD_D = 21.59                         # the NeoKey's depth, kept


def switch_centres_mm():
    """Board-local switch centres, left to right, key 0 first."""
    return [(FIRST_SWITCH_X + n * SWITCH_PITCH, SWITCH_Y) for n in range(KEY_COUNT)]


# --- the board -------------------------------------------------------------
# The USB-C receptacle is the one part that does not fit under the plate, so
# it gets a tab off the right end rather than growing the whole outline.
USB_TAB_W = 7.30

# And then everything else did not fit either. Under the key field the only
# free copper is the gaps between adjacent pixels -- 11.8 mm wide, 9.4 deep --
# plus two lanes 4.3 and 3.0 mm tall along the edges. The RP2040 is 7.48 mm
# square, so it fits one of those pockets and nothing else does; the flash,
# the crystal and fourteen decoupling caps then queue up around it with
# half-millimetre gaps, and the crystal ends up 0.46 from the MCU and 0.55
# from a pixel. Legal, and not a design -- a board that tight has no room
# for the routing that has to follow.
#
# So the field gets a bay of its own between the last key and the USB tab.
# Grown along the length rather than the depth deliberately: depth is what
# the pad occupies on a desk, length is not, and keeping the USB tab on the
# far side of the bay leaves the connector a few millimetres from the MCU
# instead of the board's whole length away.
MCU_BAY_W = 18.00
BOARD_W = KEY_FIELD_W + MCU_BAY_W + USB_TAB_W   # 139.60
BOARD_D = KEY_FIELD_D                           # 21.59
BOARD_CORNER_RADIUS = 2.54       # matches the case pocket's established radius

# Where the bay starts and ends, so nothing has to re-derive it by adding
# up widths -- that arithmetic is exactly what put an earlier round's
# targets ten millimetres out.
BAY_X0 = KEY_FIELD_W                            # 114.30
BAY_X1 = KEY_FIELD_W + MCU_BAY_W                # 132.30
USB_CX = BOARD_W - USB_TAB_W / 2                # 135.95
BOARD_T = 1.60
BOARD_LAYERS = 2

# --- parts -----------------------------------------------------------------
# EasyEDA library identifiers, found with lib_Device.search() and confirmed by
# placing them. The library UUID is the local system library.
LIB_UUID = "0819f05c4eef4c71ace90d822a990e87"
DEV_CHOC_SOCKET = "f3e2517f939147fe98be0c77b26c4c09"  # Kailh CPG135001S30,
# the Choc v1 hot-swap socket, shared by v2 -- no separate v2 part exists.
# Footprint CONN-SMD_HOTPLUGPAKAGE__C9900010116, LCSC C9900010116.
DEV_PIXEL = "d9e1e1a9f4bb4f1e8bb56ab67689f9e6"        # SK6812MINI-E_C5149201,
# matched on lib_Device.search("SK6812MINI-E") against LCSC_PIXEL below.

# LCSC numbers for the BOM, from the spec.
LCSC_RP2040 = "C2040"
LCSC_PIXEL = "C5149201"          # SK6812MINI-E, reverse mount
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

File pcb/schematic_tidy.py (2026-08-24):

# pcb/schematic_tidy.py
"""Annotate and space the schematic so a human can read it.

Run with: python3 pcb/schematic_tidy.py
         python3 pcb/schematic_tidy.py --report   # also print USB D- / empty nets
         python3 pcb/schematic_tidy.py --layout   # move parts; do not use yet

Default is annotate-only: number the `?` designators, move nothing.
`--layout` is how the previous pass wiped the page on timeout.

Does not redesign the circuit and does not change a component value or a
net name. Coordinates here are 0.01 inch -- the schematic unit, never the
PCB's 1-mil unit (see pcb/README.md).

The async primitive pattern is the one the class reference documents:
get the primitive, .toAsync(), setState_*(), await .done(). Enums are
absent from the bridge execution context, so documentType 1 is the
literal for EDMT_EditorDocumentType.SCHEMATIC_PAGE, and the PDF export
type is the literal "PDF" for ESCH_ExportDocumentFileType.PDF.
"""
import base64
import json
import os
import re
import sys

from bridge import execute

PROJECT_NAME = os.environ.get("MPAD_EDA_PROJECT", "Canopy MacroPad")
SCHEMATIC_PAGE = 1  # EDMT_EditorDocumentType.SCHEMATIC_PAGE
OUT_DIR = os.path.join(os.path.dirname(os.path.abspath(__file__)), "out")
EXPORT_PDF = os.path.join(OUT_DIR, "schematic-page.pdf")

# Destination windows from the brief. A part's origin (setState_X/Y) lands
# inside its group's window. The RP2040 symbol is taller than its window,
# so the bounding box is allowed to spill; the origin is not.
REGIONS = {
    "rp2040": (300, 620, 180, 460),
    "flash": (660, 880, 180, 340),
    "crystal": (660, 880, 370, 480),
    "ldo": (90, 280, 500, 700),
    "usb": (90, 360, 180, 460),
    "boot": (380, 560, 520, 640),
    "ports": (660, 1010, 520, 780),
    "keys": (50, 1100, 960, 1200),
}

# Group by what the part *is*, not where it currently sits. LCSC numbers
# are the identity schematic.py already matches on (the cloned device uuid
# is not the uuid that was passed to create()).
GROUP_BY_LCSC = {
    "C2961140": "rp2040",       # RP2040
    "C179171": "flash",         # W25Q64JVSSIQ, SOIC-8-208mil
    "C9900091606": "crystal",   # ABM8-272-T3
    "C5446": "ldo",             # XC6206
    "C323793": "usb",           # USBLC6-2SC6
    "C165948": "usb",           # TYPE-C-31-M-12
    "C318884": "boot",          # BOOT switch
    "C25100": "usb",            # 27 Ω USB series
    "C25905": "usb",            # 5.1 kΩ CC pull-downs
    "C1548": "crystal",         # 15 pF load caps
    "C1525": "rp2040",          # 100 nF decoupling
    "C9900010116": "keys",      # Kailh CPG135001S30 socket
    "C5149201": "keys",         # SK6812MINI-E
}

# USBLC6-2SC6 pin function by number, from ST's datasheet (same table
# schematic.py carries). The placed symbol returns pins named "1".."6".
USBLC6_PINOUT = {
    "1": "IO1",
    "2": "GND",
    "3": "IO2",
    "4": "IO2",
    "5": "VBUS",
    "6": "IO1",
}


def open_schematic():
    """Leave the project's schematic page active.

    Does not call openProject -- that discards unsaved edits. The project
    is already open; this only switches to the schematic page if the
    active document is something else, then asserts documentType is 1.
    """
    js = (
        "const proj = await eda.dmt_Project.getCurrentProjectInfo(); "
        "const name = (proj && (proj.friendlyName || proj.name)) || ''; "
        "if (name !== " + json.dumps(PROJECT_NAME) + ") { "
        "return {error: 'current project is ' + JSON.stringify(name)}; "
        "} "
        "const pages = await eda.dmt_Schematic.getAllSchematicPagesInfo(); "
        "if (!pages || !pages.length) return {error: 'project has no schematic page'}; "
        "let doc = await eda.dmt_SelectControl.getCurrentDocumentInfo(); "
        "if (!(doc && doc.documentType === 1 && doc.uuid === pages[0].uuid)) { "
        "await eda.dmt_EditorControl.openDocument(pages[0].uuid); "
        "doc = await eda.dmt_SelectControl.getCurrentDocumentInfo(); "
        "} "
        "return {opened: name, page: pages[0].name, documentType: doc.documentType, uuid: doc.uuid};"
    )
    got = execute(js)
    if got.get("error"):
        raise SystemExit(f"cannot open the schematic: {got['error']}")
    if got["documentType"] != SCHEMATIC_PAGE:
        raise SystemExit(
            f"active document is type {got['documentType']}, not a schematic page"
        )
    print(f"opened {got['opened']} / {got['page']}")


def save_schematic():
    """Persist the open schematic. `sch_Document.save()` returns false on
    upload failure, which is indistinguishable from a no-op, so treat
    false as an error rather than 'probably fine'.
    """
    got = execute("return await eda.sch_Document.save();")
    if got is not True:
        raise AssertionError(f"sch_Document.save() returned {got!r}")
    print("saved")


def snapshot():
    """Every non-sheet component, every wire, and each part's pins."""
    js = r"""
const comps = await eda.sch_PrimitiveComponent.getAll();
const parts = [];
for (const c of comps || []) {
  const type = c.getState_ComponentType();
  if (type === 'sheet') continue;
  const id = c.getState_PrimitiveId();
  const other = c.getState_OtherProperty() || {};
  const pins = await eda.sch_PrimitiveComponent.getAllPinsByPrimitiveId(id);
  const attrs = await eda.sch_PrimitiveAttribute.getAll(id);
  const vis = [];
  for (const a of attrs || []) {
    if (a.getState_ValueVisible() === true) {
      vis.push({
        k: a.getState_Key(),
        v: a.getState_Value(),
        x: a.getState_X(),
        y: a.getState_Y()
      });
    }
  }
  let mfr = null;
  for (const a of attrs || []) {
    if (a.getState_Key() === 'Manufacturer Part') mfr = a.getState_Value();
  }
  const bbox = await eda.sch_Primitive.getPrimitivesBBox([id]);
  parts.push({
    id: id,
    type: type,
    des: c.getState_Designator() || '',
    name: c.getState_Name() || '',
    x: c.getState_X(),
    y: c.getState_Y(),
    net: c.getState_Net() || '',
    sid: c.getState_SupplierId() || '',
    val: other.Value || '',
    mfr: mfr || '',
    bbox: bbox || null,
    vis: vis,
    pins: (pins || []).map(p => ({
      n: p.getState_PinName() || '',
      num: p.getState_PinNumber() || '',
      x: p.getState_X(),
      y: p.getState_Y()
    }))
  });
}
const wires = await eda.sch_PrimitiveWire.getAll();
const wout = [];
for (const w of wires || []) {
  wout.push({
    id: w.getState_PrimitiveId(),
    net: w.getState_Net(),
    line: w.getState_Line()
  });
}
return {parts: parts, wires: wout};
"""
    return execute(js, timeout=90)


def census_from(wires):
    """Count of wires per net name, empty string included."""
    counts = {}
    for w in wires:
        net = w.get("net")
        if net is None:
            net = ""
        counts[net] = counts.get(net, 0) + 1
    return counts
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

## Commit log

2026-08-08 Add Canopy MacroPad firmware and bring-up tooling
    - boot.py disables USB HID and exposes console + data CDC ports, so the
    device can never type into a focused app and macOS never asks for the
    Input Monitoring permission
    - code.py reads NeoKey 1x4 edges with a 15 ms debounce and drives the
    per-key NeoPixels over a line-delimited ASCII protocol
    - Report key count in HELLO/PONG so the host never hardcodes it, and send
    HELLO on host connect rather than at power-on, where it would be lost
    - Clear all LEDs when the host disconnects, so a crash or an unplugged
    cable cannot leave a key claiming a session still wants an answer
    - Survive a missing keypad: I2C init failure degrades to HELLO <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
    [boot.py, code.py]
2026-08-08 Harden the firmware, crossfade state changes, white-balance idle
    Review fixes, five of them defects that could brick or mislead:
    - Remove the per-key phase offset. It was applied unconditionally, so a
    key at index 2 started its pulse at the cosine peak — full brightness
    on the first frame, exactly what the comment two lines above said could
    not happen. It cannot coexist with "every pulse begins at its floor",
    and the property it was breaking is the one the approval key needs
    - Set usb_cdc write_timeout. It defaults to None, so a host that holds
    the port open and stops draining blocked the only loop forever, taking
    key scanning and the LEDs with it. `connected` tracks DTR, not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
    [boot.py, code.py]
2026-08-08 Reboot into recovery instead of dying silently
    An uncaught exception in the main loop stopped code.py, leaving a quiet
    data port and frozen LEDs — indistinguishable from a board that never
    booted, and recoverable only by a human noticing and unplugging it.
    - Report `ERR fatal <type>: <detail>`, paint every key red, then reset
    after two seconds. The host already treats a fresh HELLO as "re-push
    everything", so the recovery path needed no new wiring
    - Do NOT reset if the fault arrived within a minute of boot. A fault that
    fires every boot would reset-loop, and a board re-enumerating every few
    seconds is hard to write a new code.py to. Halt red instead: the louder
    signal, and the s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
    [code.py]
2026-08-08 Fix six defects the previous round's own fixes introduced
    A second review pass over 3c01157..6cb5675. Every must-fix below is
    damage from the round that was supposed to harden this, which is the
    argument for reviewing fixes as hard as features.
    - Clamp crossfade progress at zero. `now` is sampled once per loop while
    `retarget` stamps a fresh timestamp, so a key retargeted in the same
    iteration had `fade_started > now`. A negative t made lerp_rgb
    extrapolate past its start, a channel underflowed to -1, the packed
    value went negative, and `>> 16 & 0xFF` decoded 255 — a full-brightness
    wrong colour on exactly the transition the fade exists to smooth. A
    black-to-blue fade at t=-0.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
    [code.py]
2026-08-08 Identify the device as Saqoosha, not Whatever
    This is personal work, not company work — Canopy itself ships as
    sh.saqoo.Canopy. The company name had no business in the USB descriptor.
    Host matching is unaffected: Canopy keys on VID 0x239A plus the product
    string "Canopy MacroPad", both unchanged. Verified after a hard reset —
    ioreg now reports "USB Vendor Name" = "Saqoosha".
    [boot.py]
2026-08-08 Stop claiming four keys after the bus is gone
    `i2c_error` was a snapshot taken at startup, so a host reconnecting
    after a runtime bus loss was greeted with a clean HELLO and a key count
    the device could no longer honour. A positive claim of health is worse
    than silence. It is now live state: set when the scan guard gives up,
    restored to whatever setup found once the bus answers again.
    The advice attached to it differs by cause and must not be guessed at —
    a keypad missing since boot needs a reset once reconnected, a bus lost at
    runtime returns on its own — so the "reset required" suffix is now only
    on the boot-time case.
    The key count in HELLO stays at its startup value even then. Resi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
    [code.py]
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2026-08-09 Write down what the case work taught, not just what it produced
    The case's own README already carries the design; this is the part an
    agent needs before touching it again.
    - The replace-assert rule was never firmware-specific. It bit again in
    case/webgl.py, over two spaces of indentation, so it moves out of the
    firmware section into its own.
    - Fault injection in CAD has a failure mode of its own: a zero-width Box
    makes OCCT throw, so the build dies before the check runs and the test
    proves nothing. Inject by moving geometry, and isolate one axis --
    growing a lip to reach a button grew its height too and tripped an
    unrelated check. The numbers each injection produced are recorded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
    [bottom.step, coupon.step, shell.step]
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2026-08-10 Record that the coupon settled the switch hole
    14.15 is no longer a guess: a Durock Ice King seats in the inline coupon
    with the right amount of push, on an A1 mini in PLA Basic at 0.4/0.2. The
    0.15 over nominal is that machine's hole shrink, so it holds until the
    filament or the nozzle changes -- the number describes the printer, not
    the switch.
    Also repairs three rot spots that had crept into case/README.md: a code
    block that lost the blank line that made it one, a post height quoted as
    13.5 when that is only true of the stacked layout, and a pronoun left
    without its antecedent when webgl.py joined a sentence about product.py.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
    [params.py]
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2026-08-10 Turn three more guesses into measurements from the built part
    The inline case is assembled, so the numbers that could only be settled
    by a printer are settled: the peg drops into the NeoKey free with a
    little play, the QT Py goes into its pocket without force or slop, and a
    real USB-C cable seats fully with about a millimetre around its housing.
    That last one mattered most -- USB_PLUG_W/H were never measured off
    anything, only chosen generously, and the port would have been dead if
    the guess had been small.
    Also lifts the Qwiic notch margin out of parts.py into params, where the
    project's own rule says numbers belong. It stays at 1.00, which is what
    is printed and what the plug goes into wi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
    [params.py]
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2026-08-11 Stop macOS complaining about a disk nobody was using (#1)
    * Stop macOS complaining about a disk nobody was using
    - Gate the CIRCUITPY mass storage on a key being held at boot, so the
    usual unplug no longer produces "Disk Not Ejected Properly"
    - Fail the gate open: a missing cable, a missing lib or an unresponsive
    seesaw all leave the drive enabled, since the filesystem is how a
    broken board is recovered
    - Record which branch ran in boot_out.txt
    - Document the drive, its three ways back, and the revised bring-up
    order in README.md; update the deploy notes in AGENTS.md
    - Note the REPL gotcha that cost a reset during bring-up: Ctrl-C alone
    lands on "Press any key to enter the REPL" a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
    [boot.py, code.py]
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2026-08-12 Make the M3 go in without a fight
    The screw went into the printed shell hard, and the case fastener numbers
    turn out to have been three separate versions of the same mistake: this
    machine pulls a hole in by about 0.15, which SWITCH_HOLE already measured
    and nothing else was told about.
    - PILOT_DIA 2.50 -> 2.95, settled on the coupon against a real M3 rather
    than by arithmetic. 2.95 prints as ~2.80, or 0.93x major, well past
    what the tables want; the tables do not know this screw or this
    plastic. Recorded with the caveat that it won at the top of the sweep,
    so the diameter that strips is still unmeasured
    - Add a Ø3.40 x 0.60 conical lead-in at every pilot mouth, so a
    self-tapper h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
    [bottom.step, bottom.stl, coupon.step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]
2026-08-12 Settle the clearance hole against the print, not the arithmetic
    The bottom plate's screw holes passed a screw while guiding it. The first
    answer was the 0.15 hole shrink a third time -- 3.40 arrives as ~3.25
    against an M3's 3.00 -- and the coupon that was printed to confirm it came
    back with filament hanging in every bore instead.
    The geometry explains that: the counterbore is a Ø6.10 void and the hole
    above it is smaller, so the layer closing the counterbore is a ring
    printed over air all the way round. It sags, and what it sags into is the
    top of the bore. The built plate has the same feature, so the coupon did
    not invent the problem, it made it visible.
    A diameter sweep alone could not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
    [bottom.step, bottom.stl, coupon-clear.step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]
2026-08-12 Stop treating the stripping diameter as an open question
    2.95 won at the top of the pilot sweep, so the diameter where the thread
    lets go was never found, and three files said so in a way that reads as
    work outstanding. It is not: finding it means driving screws into posts
    until they fail, and the answer changes nothing. 2.95 works, and the
    response to a post that strips is to come down from it rather than to
    know how far up the cliff was.
    Recorded as a decision rather than a gap so nobody spends a print on it,
    the same way the firmware notes carry the diagnostics that were
    deliberately not added. The failure mode itself is left stated -- this
    number lets go on the third opening rather than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
    [params.py]
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2026-08-12 Let two kinds of hardware share one key index space
    Keys 0-3 stay on the NeoKey over I2C; keys 4-5 become two Adafruit 4978
    breakouts read straight off GPIO, with their pixels on one NeoPixel
    chain. Both kinds of pixel object are adafruit_pixelbuf.PixelBuf
    subclasses, so a single routing table covers them and the appearance
    model does not fork.
    - Route pixels through `pixel_groups` -- (pixels, base index, count) --
    instead of dividing the key index by a fixed keys-per-board. Writes
    aimed at hardware that did not come up are dropped in silence, the way
    an out-of-range index already was
    - Make NUM_KEYS a constant 6 rather than a count of what enumerated. Key
    4 has to be key 4 even whe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
    [code.py]
2026-08-12 Make "hold any key" true for all six of them
    The drive gate only ever read the NeoKey, so with keys 4 and 5 on GPIO
    the instruction printed in boot_out.txt, README.md and AGENTS.md would
    have been false for a third of the keypad.
    - Read the two GPIO keys first and skip the I2C probe entirely when one
    is held. Two pin reads against a 0.5 s seesaw software reset, so this
    is also the fast path
    - Move the adafruit_neokey import into the branch that needs it, so a
    missing library costs only the four keys that depend on it. A held
    breakout key now mounts the drive deliberately on a board where the
    library is gone, instead of the drive appearing because the gate threw
    - Deinit the pins a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
    [boot.py]
2026-08-12 Make the key field three boards wide instead of one
    Two Adafruit 4978 breakouts join the NeoKey, and the field stops being a
    synonym for the NeoKey: KEY_FIELD_W is derived from both board kinds, so
    a board that turns out not to be the width it should be fails the pitch
    check instead of quietly agreeing with itself. inline goes 120.50 ->
    158.60 wide; depth and height do not move.
    The breakouts go on the *left*, which is forced rather than preferred. A
    mated Qwiic plug stands 2.50 proud of the board edge, and a butted
    breakout's switch body starts 2.525 from that same edge -- 0.025 apart,
    which this file elsewhere calls "not clearance, the same value as the
    tolerance". Putting them on the rig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
    [bottom.step, bottom.stl, shell.step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]
2026-08-12 Number the keys the way the case has to lay them out
    The breakouts ended up to the *left* of the NeoKey, which the case
    forced: on the right, a mated Qwiic plug lands 0.025 mm from the first
    breakout's switch body, and the NeoKey's socket sits 114 mm from a QT Py
    holding a 50 mm cable. Physical order is key order, so the GPIO pair is
    0-1 and the NeoKey is 2-5 -- the opposite of what this firmware assumed
    when it was written a few commits ago.
    - Add GPIO_BASE and SEESAW_BASE as the only two constants that know
    which way round the boards go, and derive every index from them
    - Correct the comments that named keys 4 and 5
    Nothing else moves: the index space is still static, writes to absent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
    [boot.py, code.py]
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2026-08-12 Use both of the breakout's mounting holes after all
    Saqoosha asked why a board with two mounting holes was being located by
    one of them, and the answer -- a column at the second hole crosses the
    hot-swap socket by 0.738 -- turned out to be an answer about columns, not
    about pegs. A support is a 4.50 pad the board rests on. A peg is 2.30 and
    only has to reach into a hole, and 2.30 clears the socket by 0.362.
    - Every breakout peg now runs the whole way from the floor rather than
    standing on a support, because the second hole has no support under it
    and one rule beats "whichever ones happen to have a column beneath
    them". The first unions harmlessly with the column already there
    - Two di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
    [bottom.step, bottom.stl]
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2026-08-12 Measure BREAKOUT_T instead of assuming it
    The last guess in params.py was documented as unavoidable -- "Adafruit
    publishes no STEP for this board" -- and that was simply wrong. They
    publish one, in the same Adafruit_CAD_Parts repository ref/fetch.sh
    already pulls the QT Py and the NeoKey from. Nobody looked.
    - BREAKOUT_T is 1.57, read off the model, and it is exactly the NeoKey's
    1.570. The guess was right to three decimals, which is why it survived
    a whole session: nothing downstream ever disagreed with it
    - Add the breakout to ref/fetch.sh, so the claim can be re-taken
    The model corroborates two more numbers the case leans on. Its outline is
    19.050 x 21.590, matching the .brd exactly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
    [params.py]
2026-08-12 Rebuild the artefacts against the merged tree
    The rebase resolved every `out/` conflict mechanically by taking this
    branch's side, which was the right call for getting through fifteen
    commits but leaves the artefacts describing a six-key case with no lead-in
    at any pilot mouth. These are the real ones: six keys and PILOT_DIA 2.95
    in the same geometry.
    - `shell` and `bottom` change in both layouts, which is the whole overlap
    between the two branches
    - `coupon` does not change at all. It derives from PILOT_SWEEP and the
    post pitch and knows nothing about the key field, so the committed
    coupon survives the merge byte for byte -- a useful check that the two
    changes really were orthogona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
    [bottom.step, bottom.stl, shell.step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]
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2026-08-12 Put the hole diameters where the hole positions live
    A peer session hit a check that quietly relocated to empty air: its probe
    held its own copy of the coupon's row positions, the part's rows moved,
    and every "this hole is open" assertion passed by finding nothing at all.
    The warning that came with it — look for coordinates held outside the
    thing that built them — is worth acting on rather than agreeing with.
    Audited the five scripts. `product.py`, `webgl.py`, `section.py` and
    `build.py` derive everything from `params.py`; `mock.py` holds component
    measurements as literals, which is the point of a stand-in and not the
    failure mode. One thing did not fit either description:
    - The hole *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
    [params.py]
2026-08-12 Rebuild the artefacts against the clearance-hole tree
    Second rebase, same reason as the first: the `out/` conflicts were
    resolved mechanically by taking this branch's side, which leaves the
    artefacts describing a six-key case whose clearance holes have no chamfer.
    Only `bottom` moves, in both layouts, and that is the whole overlap --
    `CLEAR_CHAMFER` is a `bottom()` feature and the shell never sees it.
    `shell.stl` is byte-identical to what the previous rebase produced, and
    `coupon` is byte-identical to what the fastener session committed: the
    merged sources regenerate their coupon exactly, which is the same
    orthogonality proof as last round and the reason to keep checking it.
    Both layouts e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
    [bottom.step, bottom.stl]
2026-08-13 Let the assembled unit delete the pegs and add the rib
    First six-key shell and plate printed and populated, and it corrected the
    model twice. Neither was visible to any check, because both are about
    what the part needs rather than about whether the model is consistent.
    **The pegs are gone.** A plate-mount switch clips into the top plate and
    its pins go into the hot-swap socket on the board, so the switch is what
    ties a breakout to the plate. The supports set the height, the shell
    presses down, and a locating peg carries nothing. Saqoosha's call, on the
    built part, against a model that had reasoned itself into two of them.
    They cost more than they were worth, which only shows once they are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
    [bottom.step, bottom.stl, shell.step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]
2026-08-13 Give the socket the shape the model has, not the one I described
    Saqoosha, looking at the printed plate: two bottom-plate columns are
    through the breakout's hot-swap socket. The check said they cleared by
    0.586. The check was wrong, and it was wrong because I summarised.
    `mock.py` drew the socket as a single 10.9 x 5.9 box. In
    `ref/neokey-breakout.step` the socket is three solids -- a body and a
    solder wing off each end -- and the wings put its real span at 15.9
    across, from x 2.241 to 18.141 board-local. The summary took the largest
    solid and threw the other two away. Nothing was wrong with the file.
    - `BREAKOUT_BACK_PARTS` in params is now every part on that board's back
    face, as boxes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
    [bottom.step, bottom.stl]
2026-08-13 Turn the board over before believing its back face
    Saqoosha: the socket and every component on that face have to be
    mirrored, left to right. He is right, and it explains the collision he
    found better than the missing wings did.
    The 4978's STEP draws the switch on -z. The case puts the switch side up,
    so the board is turned over about its long axis to get there -- and
    turning it over mirrors the back face left to right. The z flip was
    implicit in placing the parts below the board; the in-plane mirror that
    comes with it was simply not there. So the socket body, its two wings,
    the reverse-mount NeoPixel and the diode were all on the wrong side.
    That is why the columns that fouled on the print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
    [bottom.step, bottom.stl]
2026-08-13 Stand a column under every seam standoff
    Saqoosha's suggestion, and the geometry allows it, which it did not
    before the back face was modelled properly.
    The shell presses the breakouts down at four points -- two seams, front
    row and back row. Nothing pushed back up along those lines, so the pair
    was offset and left a moment. That was the reason for wanting three
    support pads per board in the first place, and it was always a
    consolation rather than a fix.
    A seam column straddles two boards, so it is the only kind that has to
    clear two back faces at once. It does: 2.979 at the front row and 0.688
    at the back. So the breakouts now get the same sandwich the NeoKey has --
    push down and push up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
    [bottom.step, bottom.stl]
2026-08-13 Model the receptacle that has no cable in it
    Saqoosha: the NeoKey has a STEMMA QT receptacle at each end and only one
    was in the mock. The reason it had only one was sound and wrong -- nothing
    can be plugged into the left one with a breakout butted against it, which
    is true of the cable and says nothing about the receptacle, which is
    soldered to the board either way and which the case has to not sit on.
    Modelling it turned up a graze immediately: the seam standoff at the
    NeoKey's left edge reached 4.640 up the board and the receptacle starts
    at 4.620. 0.011 mm3 -- small, and contact all the same, between a printed
    post and a connector on a board that is pressed against it. `SEAM_Y`'s
    front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
    [bottom.step, bottom.stl, shell.step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]
2026-08-13 Put every component on the face the board actually has them on
    Saqoosha, on the assembled unit: the STEMMA receptacles were on the wrong
    side, and every component is on one face with the switch side carrying
    nothing. Six rounds of me moving one feature at a time before that landed,
    because I kept treating a rigid board as three features with three
    orientations.
    - `BOARD_FLIP_X` / `BOARD_FLIP_Y` are one statement about how a board sits
    and everything follows from them: the sockets, the back-face parts, the
    receptacles, which row the shell presses on, where a column may stand.
    Written down per feature, those five answers can disagree, and they did
    - The receptacles move under the board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
    [bottom.step, bottom.stl, coupon.step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]
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2026-08-13 Give the five wires somewhere to be
    Nothing in the case had ever been shaped for wiring, and a scan of the
    space under the boards says how close that came to not working. Five
    wires have to cross the whole field -- 3V, GND, MOSI for the pixel
    chain, and a switch line per breakout -- and there is exactly one lane:
    case y +0.55 to +5.85, narrowing to 5.30 at x -32.1, the NeoKey's left
    edge. Four 26AWG abreast, and the fifth has nowhere.
    Hopping GND and 3V board to board does not help, which was claimed here
    and is wrong: the pinch point is at key1's own right edge, so every wire
    that reaches key1 at all crosses it.
    - WIRE_LANE_Y / WIRE_CHANNEL_D sink a 1.20 channel into the plate along
    tha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
    [bottom.step, bottom.stl, shell.step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]
2026-08-13 Keep the wire channel off the screws, and out of the other layout
    The channel landed last commit running from 2 mm left of the field to the
    QT Py's centre, which put it across both screw positions at y +8.2. That
    is worse than it sounds and nothing said so:
    - the counterbore's ceiling is at z 1.00 and the trench floor at 1.20, so
    0.70 of y was spanned by 0.20 of plate. One layer, printed over the
    bore, under the seat the screw head bears on -- the same failure this
    repository already has a paragraph about, arrived at from the other
    side
    - 0.45 of the shell's post stood on air beside it
    - every boolean read 0.000 through all of it, because a boolean asks what
    two solids share and a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
    [bottom.step, bottom.stl, shell.step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]
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2026-08-13 Boolean the plate that has to be there, not the plate that must not
    The wire channel eating the screw head's seat was caught by two
    plan-view margins, and a peer session pointed out those are arithmetic
    guards -- the same thing this repository already says is not evidence.
    It is right. Nothing that reads "what do these two solids share" can
    ever see it, because what the trench left behind is a void.
    So the polarity flips. `_head_seat_probe()` builds the ring the screw
    head bears on -- Ø SCREW_HEAD_DIA down to Ø SCREW_CLEAR_DIA, from above
    the lead-in cone to the plate's top face -- and subtracts the plate from
    it. What is left is plate that is required and is not there. Zero now;
    0.790 mm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
    [shell.step, shell.stl]
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

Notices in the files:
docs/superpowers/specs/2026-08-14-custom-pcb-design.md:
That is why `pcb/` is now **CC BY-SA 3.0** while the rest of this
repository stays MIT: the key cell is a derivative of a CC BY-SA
